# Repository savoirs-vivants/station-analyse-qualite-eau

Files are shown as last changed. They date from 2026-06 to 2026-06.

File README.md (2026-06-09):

# Station d'Analyse de la Qualité de l'Eau 💧

Station autonome pour la surveillance de la qualité de l'eau. Ce dépôt contient l'intégralité de la conception matérielle (schémas et routage PCB) ainsi que le firmware d'acquisition.

## 🎯 Objectif du projet

Ce système a pour but de collecter, traiter, transmettre et enregistrer des données environnementales issues de différentes sondes. Il est conçu pour être autonome en énergie et low-cost.

**Paramètres mesurés :**
*  Température de l'eau
*  Température et Humidité de l'air
*  Conductivité / TDS
*  Turbidité
*  Débit/Hauteur d'eau

## 📁 Architecture du projet

Ce dépôt est organisé en deux parties distinctes :

* 🛠️ **`/hardware`** : Fichiers de conception de la carte électronique réalisés sous KiCad (Schémas, PCB, nomenclatures).
* 💻 **`/firmware`** : Code source en C gérant l'acquisition , le traitement des signaux capteurs et la logique système.

*Pour plus de détails techniques, veuillez consulter les fichiers `README.md` présents dans chacun de ces répertoires.*

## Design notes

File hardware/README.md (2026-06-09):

# 🛠️ Conception Matérielle (Hardware)

Ce dossier contient l'intégralité du projet de conception de la carte mère de la **Station d'Analyse de la Qualité de l'Eau**. La carte est architecturée autour d'un microcontrôleur ultra-basse consommation **STM32U083RC**.

## 📌 Caractéristiques Techniques

* **Microcontrôleur :** STM32U083RC (ARM Cortex-M0+, optimisation Low-Power).
* **Mémoire non volatile :** FeRAM (Ferroelectric RAM) via bus SPI pour le datalogging.
* **Connectivité Radio :**
    * **LoRaWAN :** Module radio intégré pour la transmission vers réseau ChirpStack.
    * **Bluetooth Low Energy (BLE) :** Pour la récupération locale des données en cas de problème avec le LoRa.

## 📂 Architecture du dossier KiCad

* `*.kicad_sch` : Schémas électriques hiérarchiques.
* `*.kicad_pcb` : Routage de la carte.
* `/production` : Fichiers de fabrication générés pour JLCPCB.
* `/3D_Models` : Fichiers STEP pour le rendu 3D.

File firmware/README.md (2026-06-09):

# 💻 Code Embarqué (Firmware STM32)

Ce dossier contient le code source en **C** développé sous **STM32CubeIDE / Eclipse**. Le firmware orchestre l'acquisition des données environnementales, leur stockage sécurisé et leur transmission.

## ⚙️ Environnement & Outils

* **Cible :** STM32U083RC
* **IDE :** STM32CubeIDE (Génération initiale via STM32CubeMX)
* **Documentation :** Doxygen + Graphviz (Voir la section *Documentation* ci-dessous).

## 📂 Architecture du Code

Le projet suit la structure standard de STM32CubeIDE, enrichie de nos propres bibliothèques matérielles :

* `Core/Src/main.c` : Point d'entrée.
* `Core/Src/app_main_test.c` : Fichier d'orchestration principale (Machine d'états, gestion des priorités et du mode Sleep).
* `Drivers/Custom/` : Pilotes développés spécifiquement pour la station :
    * `driverDS18B20` : Lecture de la température (1-Wire émulé via UART).
    * `driverAnalog` : Gestion de l'ADC avec séquenceur fixe et transferts DMA.
    * `driverFRAM` & `driverDataLog` : Pilotes SPI bas niveau et système de fichiers pour le stockage des logs.
    * `driverLoRaWAN` : Empaquetage (Cayenne LPP) et transmission des trames.
    * `driverBLE` : Streaming des archives de données vers un smartphone.
    * `driverRTC` : Gestion du temps et réveils périodiques.

## 🚀 Fonctionnalités Clés & Choix Techniques

1.  **Datalogging Robuste :** Les mesures sont stockées en FeRAM. Le système utilise un pointeur circulaire (`newest_id`) pour gérer l'écrasement des données les plus anciennes.
2.  **Transmission LoRaWAN :** Envoi périodique sur réseau privé ChirpStack (Utilisation d'un `JoinEUI` à `0000000000000000` par défaut). Format de charge utile : **Cayenne LPP**.
3.  **Optimisation des transferts :** Utilisation systématique du DMA pour les lectures FeRAM et le streaming BLE afin de ne pas bloquer le processeur et éviter les corruptions de données.
4.  **Mathématiques en Virgule Fixe :** Remplacement des `float` par la notation en virgule fixe (Q-format) sur 16 bits signés pour optimiser le temps d'exécution et réduire la charge utile radio.

## 📚 Documentation (Doxygen)

Le code est intégralement documenté via des balises Doxygen.
Pour générer la documentation HTML sur votre machine :
1. Ouvrir `Doxywizard`.
2. Charger le fichier de configuration (Doxyfile) situé à la racine du projet firmware.
3. Vérifier que l'option **"Scan recursively"** est bien cochée.
4. Cliquer sur **"Run Doxygen"**. La documentation sera disponible dans le dossier `/html`.

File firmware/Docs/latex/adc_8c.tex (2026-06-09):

\doxysection{C:\+/\+\+Users/\+valen/\+\+Documents/\+\+BUT GEII/\+\+SAE601/\+station\+\_\+analyse\+\_\+qualite\+\_\+eau/\+firmware/\+station\+\_\+analyse\+\_\+qualite\+\_\+eau/\+\+Core/\+\+Src/\+adc.c File Reference}
\hypertarget{adc_8c}{}\label{adc_8c}\index{C:/Users/valen/Documents/BUT GEII/SAE601/station\_analyse\_qualite\_eau/firmware/station\_analyse\_qualite\_eau/Core/Src/adc.c@{C:/Users/valen/Documents/BUT GEII/SAE601/station\_analyse\_qualite\_eau/firmware/station\_analyse\_qualite\_eau/Core/Src/adc.c}}

This file provides code for the configuration of the ADC instances.  

{\ttfamily \+\#include "{}adc.\+h"{}}\newline
Include dependency graph for adc.\+c:\+
\nopagebreak
\begin{figure}[H]
\begin{center}
\leavevmode
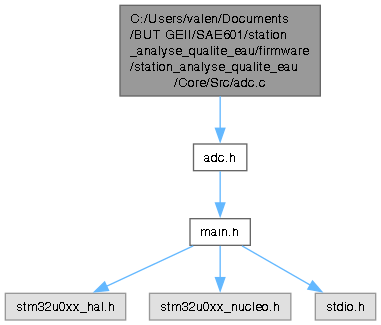
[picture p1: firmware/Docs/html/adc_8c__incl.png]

\end{center}
\end{figure}
\doxysubsubsection*{Functions}
\begin{DoxyCompactItemize}
\item 
void \doxymbox{\hyperlink{adc_8c_acccd58aa70215a6b184ad242312ffd0c}{MX\+\_\+\+ADC1\+\_\+\+Init}} (void)
\item 
void \doxymbox{\hyperlink{adc_8c_ac3139540667c403c5dfd37a99c610b1c}{HAL\+\_\+\+ADC\+\_\+\+Msp\+Init}} (ADC\+\_\+\+Handle\+Type\+Def \texorpdfstring{$\ast$}{*}adc\+Handle)
\item 
void \doxymbox{\hyperlink{adc_8c_a3f61f2c2af0f122f81a87af8ad7b4360}{HAL\+\_\+\+ADC\+\_\+\+Msp\+De\+Init}} (ADC\+\_\+\+Handle\+Type\+Def \texorpdfstring{$\ast$}{*}adc\+Handle)
\end{DoxyCompactItemize}
\doxysubsubsection*{Variables}
\begin{DoxyCompactItemize}
\item 
ADC\+\_\+\+Handle\+Type\+Def \doxymbox{\hyperlink{adc_8c_a22b804736f5648d52f639b2647d4ed13}{hadc1}}
\item 
DMA\+\_\+\+Handle\+Type\+Def \doxymbox{\hyperlink{adc_8c_a1c126854bb1813d31ab4776b21dcc51f}{hdma\+\_\+adc1}}
\end{DoxyCompactItemize}

\doxysubsection{Detailed Description}
This file provides code for the configuration of the ADC instances. 

\begin{DoxyAttention}{Attention}

\end{DoxyAttention}
Copyright (c) 2026 STMicroelectronics. All rights reserved.

This software is licensed under terms that can be found in the LICENSE file in the root directory of this software component. If no LICENSE file comes with this software, it is provided AS-\/\+IS. 

\label{adc_8c_doc-func-members}
\Hypertarget{adc_8c_doc-func-members}
\doxysubsection{Function Documentation}
\Hypertarget{adc_8c_a3f61f2c2af0f122f81a87af8ad7b4360}\index{adc.c@{adc.c}!HAL\_ADC\_MspDeInit@{HAL\_ADC\_MspDeInit}}
\index{HAL\_ADC\_MspDeInit@{HAL\_ADC\_MspDeInit}!adc.c@{adc.c}}
\doxysubsubsection{\texorpdfstring{HAL\_ADC\_MspDeInit()}{HAL\_ADC\_MspDeInit()}}
{\footnotesize\ttfamily \label{adc_8c_a3f61f2c2af0f122f81a87af8ad7b4360} 
void HAL\+\_\+\+ADC\+\_\+\+Msp\+De\+Init (\begin{DoxyParamCaption}\item[{ADC\+\_\+\+Handle\+Type\+Def \texorpdfstring{$\ast$}{*}}]{adc\+Handle}{}\end{DoxyParamCaption})}

ADC1 GPIO Configuration PC2 -\/-\/-\/-\/-\/-\/\texorpdfstring{$>$}{>} ADC1\+\_\+\+IN2 PC3 -\/-\/-\/-\/-\/-\/\texorpdfstring{$>$}{>} ADC1\+\_\+\+IN3 PB1 -\/-\/-\/-\/-\/-\/\texorpdfstring{$>$}{>} ADC1\+\_\+\+IN18\Hypertarget{adc_8c_ac3139540667c403c5dfd37a99c610b1c}\index{adc.c@{adc.c}!HAL\_ADC\_MspInit@{HAL\_ADC\_MspInit}}
\index{HAL\_ADC\_MspInit@{HAL\_ADC\_MspInit}!adc.c@{adc.c}}
\doxysubsubsection{\texorpdfstring{HAL\_ADC\_MspInit()}{HAL\_ADC\_MspInit()}}
{\footnotesize\ttfamily \label{adc_8c_ac3139540667c403c5dfd37a99c610b1c} 
void HAL\+\_\+\+ADC\+\_\+\+Msp\+Init (\begin{DoxyParamCaption}\item[{ADC\+\_\+\+Handle\+Type\+Def \texorpdfstring{$\ast$}{*}}]{adc\+Handle}{}\end{DoxyParamCaption})}

Initializes the peripherals clocks

ADC1 GPIO Configuration PC2 -\/-\/-\/-\/-\/-\/\texorpdfstring{$>$}{>} ADC1\+\_\+\+IN2 PC3 -\/-\/-\/-\/-\/-\/\texorpdfstring{$>$}{>} ADC1\+\_\+\+IN3 PB1 -\/-\/-\/-\/-\/-\/\texorpdfstring{$>$}{>} ADC1\+\_\+\+IN18Here is the call graph for this function:\+
\nopagebreak
\begin{figure}[H]
\begin{center}
\leavevmode

\end{center}
\end{figure}
\Hypertarget{adc_8c_acccd58aa70215a6b184ad242312ffd0c}\index{adc.c@{adc.c}!MX\_ADC1\_Init@{MX\_ADC1\_Init}}
\index{MX\_ADC1\_Init@{MX\_ADC1\_Init}!adc.c@{adc.c}}
\doxysubsubsection{\texorpdfstring{MX\_ADC1\_Init()}{MX\_ADC1\_Init()}}
{\footnotesize\ttfamily \label{adc_8c_acccd58aa70215a6b184ad242312ffd0c} 
void MX\+\_\+\+ADC1\+\_\+\+Init (\begin{DoxyParamCaption}\item[{void}]{}{}\end{DoxyParamCaption})}

Configure the global features of the ADC (Clock, Resolution, Data Alignment and number of conversion)

Configure Regular Channel

Configure Regular Channel

Configure Regular Channel

Configure Regular Channel

Configure the Watch\+Dogs 2

Configure the Watch\+Dogs 3Here is the call graph for this function:\+
\nopagebreak
\begin{figure}[H]
\begin{center}
\leavevmode

\end{center}
\end{figure}
Here is the caller graph for this function:\+
\nopagebreak
\begin{figure}[H]
\begin{center}
\leavevmode

\end{center}
\end{figure}

\label{adc_8c_doc-var-members}
\Hypertarget{adc_8c_doc-var-members}
\doxysubsection{Variable Documentation}
\Hypertarget{adc_8c_a22b804736f5648d52f639b2647d4ed13}\index{adc.c@{adc.c}!hadc1@{hadc1}}
\index{hadc1@{hadc1}!adc.c@{adc.c}}
\doxysubsubsection{\texorpdfstring{hadc1}{hadc1}}
{\footnotesize\ttfamily \label{adc_8c_a22b804736f5648d52f639b2647d4ed13} 
ADC\+\_\+\+Handle\+Type\+Def hadc1}

\Hypertarget{adc_8c_a1c126854bb1813d31ab4776b21dcc51f}\index{adc.c@{adc.c}!hdma\_adc1@{hdma\_adc1}}
\index{hdma\_adc1@{hdma\_adc1}!adc.c@{adc.c}}
\doxysubsubsection{\texorpdfstring{hdma\_adc1}{hdma\_adc1}}
{\footnotesize\ttfamily \label{adc_8c_a1c126854bb1813d31ab4776b21dcc51f} 
DMA\+\_\+\+Handle\+Type\+Def hdma\+\_\+adc1}

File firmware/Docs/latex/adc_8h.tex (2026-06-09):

\doxysection{C:\+/\+\+Users/\+valen/\+\+Documents/\+\+BUT GEII/\+\+SAE601/\+station\+\_\+analyse\+\_\+qualite\+\_\+eau/\+firmware/\+station\+\_\+analyse\+\_\+qualite\+\_\+eau/\+\+Core/\+\+Inc/\+adc.h File Reference}
\hypertarget{adc_8h}{}\label{adc_8h}\index{C:/Users/valen/Documents/BUT GEII/SAE601/station\_analyse\_qualite\_eau/firmware/station\_analyse\_qualite\_eau/Core/Inc/adc.h@{C:/Users/valen/Documents/BUT GEII/SAE601/station\_analyse\_qualite\_eau/firmware/station\_analyse\_qualite\_eau/Core/Inc/adc.h}}

This file contains all the function prototypes for the \doxylink{adc_8c}{adc.\+c} file.  

{\ttfamily \+\#include "{}main.\+h"{}}\newline
Include dependency graph for adc.\+h:\+
\nopagebreak
\begin{figure}[H]
\begin{center}
\leavevmode
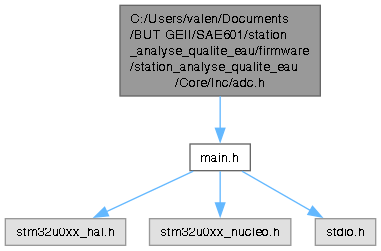
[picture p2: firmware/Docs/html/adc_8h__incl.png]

\end{center}
\end{figure}
This graph shows which files directly or indirectly include this file:\+
\nopagebreak
\begin{figure}[H]
\begin{center}
\leavevmode
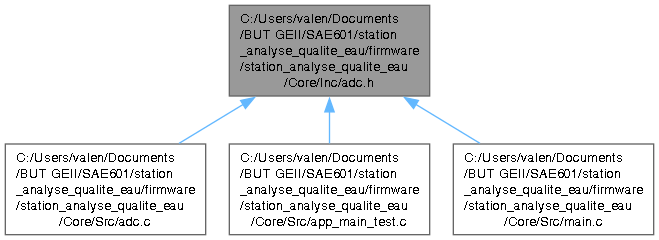
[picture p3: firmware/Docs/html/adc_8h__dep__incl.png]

\end{center}
\end{figure}
\doxysubsubsection*{Functions}
\begin{DoxyCompactItemize}
\item 
void \doxymbox{\hyperlink{adc_8h_acccd58aa70215a6b184ad242312ffd0c}{MX\+\_\+\+ADC1\+\_\+\+Init}} (void)
\end{DoxyCompactItemize}
\doxysubsubsection*{Variables}
\begin{DoxyCompactItemize}
\item 
ADC\+\_\+\+Handle\+Type\+Def \doxymbox{\hyperlink{adc_8h_a22b804736f5648d52f639b2647d4ed13}{hadc1}}
\end{DoxyCompactItemize}

\doxysubsection{Detailed Description}
This file contains all the function prototypes for the \doxylink{adc_8c}{adc.\+c} file. 

\begin{DoxyAttention}{Attention}

\end{DoxyAttention}
Copyright (c) 2026 STMicroelectronics. All rights reserved.

This software is licensed under terms that can be found in the LICENSE file in the root directory of this software component. If no LICENSE file comes with this software, it is provided AS-\/\+IS. 

\label{adc_8h_doc-func-members}
\Hypertarget{adc_8h_doc-func-members}
\doxysubsection{Function Documentation}
\Hypertarget{adc_8h_acccd58aa70215a6b184ad242312ffd0c}\index{adc.h@{adc.h}!MX\_ADC1\_Init@{MX\_ADC1\_Init}}
\index{MX\_ADC1\_Init@{MX\_ADC1\_Init}!adc.h@{adc.h}}
\doxysubsubsection{\texorpdfstring{MX\_ADC1\_Init()}{MX\_ADC1\_Init()}}
{\footnotesize\ttfamily \label{adc_8h_acccd58aa70215a6b184ad242312ffd0c} 
void MX\+\_\+\+ADC1\+\_\+\+Init (\begin{DoxyParamCaption}\item[{void}]{}{}\end{DoxyParamCaption})}

Configure the global features of the ADC (Clock, Resolution, Data Alignment and number of conversion)

Configure Regular Channel

Configure Regular Channel

Configure Regular Channel

Configure Regular Channel

Configure the Watch\+Dogs 2

Configure the Watch\+Dogs 3Here is the call graph for this function:\+
\nopagebreak
\begin{figure}[H]
\begin{center}
\leavevmode

\end{center}
\end{figure}
Here is the caller graph for this function:\+
\nopagebreak
\begin{figure}[H]
\begin{center}
\leavevmode

\end{center}
\end{figure}

\label{adc_8h_doc-var-members}
\Hypertarget{adc_8h_doc-var-members}
\doxysubsection{Variable Documentation}
\Hypertarget{adc_8h_a22b804736f5648d52f639b2647d4ed13}\index{adc.h@{adc.h}!hadc1@{hadc1}}
\index{hadc1@{hadc1}!adc.h@{adc.h}}
\doxysubsubsection{\texorpdfstring{hadc1}{hadc1}}
{\footnotesize\ttfamily \label{adc_8h_a22b804736f5648d52f639b2647d4ed13} 
ADC\+\_\+\+Handle\+Type\+Def hadc1\hspace{0.3cm}{\ttfamily [extern]}}

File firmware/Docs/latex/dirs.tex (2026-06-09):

\doxysection{Directories}
\begin{DoxyCompactList}
\item \contentsline{section}{Core }{\pageref{dir_9d5e7573dc5466d7cafab5f0bc7db382}}{}
\begin{DoxyCompactList}
\item \contentsline{section}{Inc }{\pageref{dir_90b35f58c259cafbcc0aa6572fba667e}}{}
\begin{DoxyCompactList}
\item \contentsline{section}{adc.\+h }{\pageref{adc_8h}}{}
\item \contentsline{section}{app\+\_\+main\+\_\+test.\+h }{\pageref{app__main__test_8h}}{}
\item \contentsline{section}{dma.\+h }{\pageref{dma_8h}}{}
\item \contentsline{section}{driver\+Analog.\+h }{\pageref{driver_analog_8h}}{}
\item \contentsline{section}{driver\+BLE.\+h }{\pageref{driver_b_l_e_8h}}{}
\item \contentsline{section}{driver\+Data\+Log.\+h }{\pageref{driver_data_log_8h}}{}
\item \contentsline{section}{driver\+DS18\+B20.\+h }{\pageref{driver_d_s18_b20_8h}}{}
\item \contentsline{section}{driver\+FRAM.\+h }{\pageref{driver_f_r_a_m_8h}}{}
\item \contentsline{section}{driver\+Lo\+Ra.\+h }{\pageref{driver_lo_ra_8h}}{}
\item \contentsline{section}{driver\+Lo\+Ra\+App.\+h }{\pageref{driver_lo_ra_app_8h}}{}
\item \contentsline{section}{driver\+Lo\+Ra\+WAN.\+h }{\pageref{driver_lo_ra_w_a_n_8h}}{}
\item \contentsline{section}{driver\+LPPCayenne.\+h }{\pageref{driver_l_p_p_cayenne_8h}}{}
\item \contentsline{section}{driver\+RTC.\+h }{\pageref{driver_r_t_c_8h}}{}
\item \contentsline{section}{gpio.\+h }{\pageref{gpio_8h}}{}
\item \contentsline{section}{lptim.\+h }{\pageref{lptim_8h}}{}
\item \contentsline{section}{main.\+h }{\pageref{main_8h}}{}
\item \contentsline{section}{rtc.\+h }{\pageref{rtc_8h}}{}
\item \contentsline{section}{spi.\+h }{\pageref{spi_8h}}{}
\item \contentsline{section}{stm32u0xx\+\_\+hal\+\_\+conf.\+h }{\pageref{stm32u0xx__hal__conf_8h}}{}
\item \contentsline{section}{stm32u0xx\+\_\+it.\+h }{\pageref{stm32u0xx__it_8h}}{}
\item \contentsline{section}{stm32u0xx\+\_\+nucleo\+\_\+conf.\+h }{\pageref{stm32u0xx__nucleo__conf_8h}}{}
\item \contentsline{section}{test\+\_\+analog.\+h }{\pageref{test__analog_8h}}{}
\item \contentsline{section}{test\+\_\+ble.\+h }{\pageref{test__ble_8h}}{}
\item \contentsline{section}{test\+\_\+datalog.\+h }{\pageref{test__datalog_8h}}{}
\item \contentsline{section}{test\+\_\+ds18b20.\+h }{\pageref{test__ds18b20_8h}}{}
\item \contentsline{section}{test\+\_\+fram.\+h }{\pageref{test__fram_8h}}{}
\item \contentsline{section}{test\+\_\+lorawan.\+h }{\pageref{test__lorawan_8h}}{}
\item \contentsline{section}{test\+\_\+lpp.\+h }{\pageref{test__lpp_8h}}{}
\item \contentsline{section}{tim.\+h }{\pageref{tim_8h}}{}
\item \contentsline{section}{usart.\+h }{\pageref{usart_8h}}{}
\end{DoxyCompactList}
\item \contentsline{section}{Src }{\pageref{dir_1ca2d35386e5ad8f7045c2fe5e28151f}}{}
\begin{DoxyCompactList}
\item \contentsline{section}{adc.\+c }{\pageref{adc_8c}}{}
\item \contentsline{section}{app\+\_\+main\+\_\+test.\+c }{\pageref{app__main__test_8c}}{}
\item \contentsline{section}{dma.\+c }{\pageref{dma_8c}}{}
\item \contentsline{section}{driver\+Analog.\+c }{\pageref{driver_analog_8c}}{}
\item \contentsline{section}{driver\+BLE.\+c }{\pageref{driver_b_l_e_8c}}{}
\item \contentsline{section}{driver\+Data\+Log.\+c }{\pageref{driver_data_log_8c}}{}
\item \contentsline{section}{driver\+DS18\+B20.\+c }{\pageref{driver_d_s18_b20_8c}}{}
\item \contentsline{section}{driver\+FRAM.\+c }{\pageref{driver_f_r_a_m_8c}}{}
\item \contentsline{section}{driver\+Lo\+Ra.\+c }{\pageref{driver_lo_ra_8c}}{}
\item \contentsline{section}{driver\+Lo\+Ra\+App.\+c }{\pageref{driver_lo_ra_app_8c}}{}
\item \contentsline{section}{driver\+Lo\+Ra\+WAN.\+c }{\pageref{driver_lo_ra_w_a_n_8c}}{}
\item \contentsline{section}{driver\+LPPCayenne.\+c }{\pageref{driver_l_p_p_cayenne_8c}}{}
\item \contentsline{section}{driver\+RTC.\+c }{\pageref{driver_r_t_c_8c}}{}
\item \contentsline{section}{gpio.\+c }{\pageref{gpio_8c}}{}
\item \contentsline{section}{lptim.\+c }{\pageref{lptim_8c}}{}
\item \contentsline{section}{main.\+c }{\pageref{main_8c}}{}
\item \contentsline{section}{rtc.\+c }{\pageref{rtc_8c}}{}
\item \contentsline{section}{spi.\+c }{\pageref{spi_8c}}{}
\item \contentsline{section}{stm32u0xx\+\_\+hal\+\_\+msp.\+c }{\pageref{stm32u0xx__hal__msp_8c}}{}
\item \contentsline{section}{stm32u0xx\+\_\+it.\+c }{\pageref{stm32u0xx__it_8c}}{}
\item \contentsline{section}{syscalls.\+c }{\pageref{syscalls_8c}}{}
\item \contentsline{section}{sysmem.\+c }{\pageref{sysmem_8c}}{}
\item \contentsline{section}{system\+\_\+stm32u0xx.\+c }{\pageref{system__stm32u0xx_8c}}{}
\item \contentsline{section}{test\+\_\+analog.\+c }{\pageref{test__analog_8c}}{}
\item \contentsline{section}{test\+\_\+ble.\+c }{\pageref{test__ble_8c}}{}
\item \contentsline{section}{test\+\_\+datalog.\+c }{\pageref{test__datalog_8c}}{}
\item \contentsline{section}{test\+\_\+ds18b20.\+c }{\pageref{test__ds18b20_8c}}{}
\item \contentsline{section}{test\+\_\+fram.\+c }{\pageref{test__fram_8c}}{}
\item \contentsline{section}{test\+\_\+lorawan.\+c }{\pageref{test__lorawan_8c}}{}
\item \contentsline{section}{test\+\_\+lpp.\+c }{\pageref{test__lpp_8c}}{}
\item \contentsline{section}{tim.\+c }{\pageref{tim_8c}}{}
\item \contentsline{section}{usart.\+c }{\pageref{usart_8c}}{}
\end{DoxyCompactList}
\end{DoxyCompactList}
\item \contentsline{section}{Inc }{\pageref{dir_90b35f58c259cafbcc0aa6572fba667e}}{}
\begin{DoxyCompactList}
\item \contentsline{section}{adc.\+h }{\pageref{adc_8h}}{}
\item \contentsline{section}{app\+\_\+main\+\_\+test.\+h }{\pageref{app__main__test_8h}}{}
\item \contentsline{section}{dma.\+h }{\pageref{dma_8h}}{}
\item \contentsline{section}{driver\+Analog.\+h }{\pageref{driver_analog_8h}}{}
\item \contentsline{section}{driver\+BLE.\+h }{\pageref{driver_b_l_e_8h}}{}
\item \contentsline{section}{driver\+Data\+Log.\+h }{\pageref{driver_data_log_8h}}{}
\item \contentsline{section}{driver\+DS18\+B20.\+h }{\pageref{driver_d_s18_b20_8h}}{}
\item \contentsline{section}{driver\+FRAM.\+h }{\pageref{driver_f_r_a_m_8h}}{}
\item \contentsline{section}{driver\+Lo\+Ra.\+h }{\pageref{driver_lo_ra_8h}}{}
\item \contentsline{section}{driver\+Lo\+Ra\+App.\+h }{\pageref{driver_lo_ra_app_8h}}{}
\item \contentsline{section}{driver\+Lo\+Ra\+WAN.\+h }{\pageref{driver_lo_ra_w_a_n_8h}}{}
\item \contentsline{section}{driver\+LPPCayenne.\+h }{\pageref{driver_l_p_p_cayenne_8h}}{}
\item \contentsline{section}{driver\+RTC.\+h }{\pageref{driver_r_t_c_8h}}{}
\item \contentsline{section}{gpio.\+h }{\pageref{gpio_8h}}{}
\item \contentsline{section}{lptim.\+h }{\pageref{lptim_8h}}{}
\item \contentsline{section}{main.\+h }{\pageref{main_8h}}{}
\item \contentsline{section}{rtc.\+h }{\pageref{rtc_8h}}{}
\item \contentsline{section}{spi.\+h }{\pageref{spi_8h}}{}
\item \contentsline{section}{stm32u0xx\+\_\+hal\+\_\+conf.\+h }{\pageref{stm32u0xx__hal__conf_8h}}{}
\item \contentsline{section}{stm32u0xx\+\_\+it.\+h }{\pageref{stm32u0xx__it_8h}}{}
\item \contentsline{section}{stm32u0xx\+\_\+nucleo\+\_\+conf.\+h }{\pageref{stm32u0xx__nucleo__conf_8h}}{}
\item \contentsline{section}{test\+\_\+analog.\+h }{\pageref{test__analog_8h}}{}
\item \contentsline{section}{test\+\_\+ble.\+h }{\pageref{test__ble_8h}}{}
\item \contentsline{section}{test\+\_\+datalog.\+h }{\pageref{test__datalog_8h}}{}
\item \contentsline{section}{test\+\_\+ds18b20.\+h }{\pageref{test__ds18b20_8h}}{}
\item \contentsline{section}{test\+\_\+fram.\+h }{\pageref{test__fram_8h}}{}
\item \contentsline{section}{test\+\_\+lorawan.\+h }{\pageref{test__lorawan_8h}}{}
\item \contentsline{section}{test\+\_\+lpp.\+h }{\pageref{test__lpp_8h}}{}
\item \contentsline{section}{tim.\+h }{\pageref{tim_8h}}{}
\item \contentsline{section}{usart.\+h }{\pageref{usart_8h}}{}
\end{DoxyCompactList}
\item \contentsline{section}{Src }{\pageref{dir_1ca2d35386e5ad8f7045c2fe5e28151f}}{}
\begin{DoxyCompactList}
\item \contentsline{section}{adc.\+c }{\pageref{adc_8c}}{}
\item \contentsline{section}{app\+\_\+main\+\_\+test.\+c }{\pageref{app__main__test_8c}}{}
\item \contentsline{section}{dma.\+c }{\pageref{dma_8c}}{}
\item \contentsline{section}{driver\+Analog.\+c }{\pageref{driver_analog_8c}}{}
\item \contentsline{section}{driver\+BLE.\+c }{\pageref{driver_b_l_e_8c}}{}
\item \contentsline{section}{driver\+Data\+Log.\+c }{\pageref{driver_data_log_8c}}{}
\item \contentsline{section}{driver\+DS18\+B20.\+c }{\pageref{driver_d_s18_b20_8c}}{}
\item \contentsline{section}{driver\+FRAM.\+c }{\pageref{driver_f_r_a_m_8c}}{}
\item \contentsline{section}{driver\+Lo\+Ra.\+c }{\pageref{driver_lo_ra_8c}}{}
\item \contentsline{section}{driver\+Lo\+Ra\+App.\+c }{\pageref{driver_lo_ra_app_8c}}{}
\item \contentsline{section}{driver\+Lo\+Ra\+WAN.\+c }{\pageref{driver_lo_ra_w_a_n_8c}}{}
\item \contentsline{section}{driver\+LPPCayenne.\+c }{\pageref{driver_l_p_p_cayenne_8c}}{}
\item \contentsline{section}{driver\+RTC.\+c }{\pageref{driver_r_t_c_8c}}{}
\item \contentsline{section}{gpio.\+c }{\pageref{gpio_8c}}{}
\item \contentsline{section}{lptim.\+c }{\pageref{lptim_8c}}{}
\item \contentsline{section}{main.\+c }{\pageref{main_8c}}{}
\item \contentsline{section}{rtc.\+c }{\pageref{rtc_8c}}{}
\item \contentsline{section}{spi.\+c }{\pageref{spi_8c}}{}
\item \contentsline{section}{stm32u0xx\+\_\+hal\+\_\+msp.\+c }{\pageref{stm32u0xx__hal__msp_8c}}{}
\item \contentsline{section}{stm32u0xx\+\_\+it.\+c }{\pageref{stm32u0xx__it_8c}}{}
\item \contentsline{section}{syscalls.\+c }{\pageref{syscalls_8c}}{}
\item \contentsline{section}{sysmem.\+c }{\pageref{sysmem_8c}}{}
\item \contentsline{section}{system\+\_\+stm32u0xx.\+c }{\pageref{system__stm32u0xx_8c}}{}
\item \contentsline{section}{test\+\_\+analog.\+c }{\pageref{test__analog_8c}}{}
\item \contentsline{section}{test\+\_\+ble.\+c }{\pageref{test__ble_8c}}{}
\item \contentsline{section}{test\+\_\+datalog.\+c }{\pageref{test__datalog_8c}}{}
\item \contentsline{section}{test\+\_\+ds18b20.\+c }{\pageref{test__ds18b20_8c}}{}
\item \contentsline{section}{test\+\_\+fram.\+c }{\pageref{test__fram_8c}}{}
\item \contentsline{section}{test\+\_\+lorawan.\+c }{\pageref{test__lorawan_8c}}{}
\item \contentsline{section}{test\+\_\+lpp.\+c }{\pageref{test__lpp_8c}}{}
\item \contentsline{section}{tim.\+c }{\pageref{tim_8c}}{}
\item \contentsline{section}{usart.\+c }{\pageref{usart_8c}}{}
\end{DoxyCompactList}
\item \contentsline{section}{station\+\_\+analyse\+\_\+qualite\+\_\+eau }{\pageref{dir_4fc195ea1a251ebc8cad320ade13d143}}{}
\begin{DoxyCompactList}
\item \contentsline{section}{Core }{\pageref{dir_9d5e7573dc5466d7cafab5f0bc7db382}}{}
\begin{DoxyCompactList}
\item \contentsline{section}{Inc }{\pageref{dir_90b35f58c259cafbcc0aa6572fba667e}}{}
\begin{DoxyCompactList}
\item \contentsline{section}{adc.\+h }{\pageref{adc_8h}}{}
\item \contentsline{section}{app\+\_\+main\+\_\+test.\+h }{\pageref{app__main__test_8h}}{}
\item \contentsline{section}{dma.\+h }{\pageref{dma_8h}}{}
\item \contentsline{section}{driver\+Analog.\+h }{\pageref{driver_analog_8h}}{}
\item \contentsline{section}{driver\+BLE.\+h }{\pageref{driver_b_l_e_8h}}{}
\item \contentsline{section}{driver\+Data\+Log.\+h }{\pageref{driver_data_log_8h}}{}
\item \contentsline{section}{driver\+DS18\+B20.\+h }{\pageref{driver_d_s18_b20_8h}}{}
\item \contentsline{section}{driver\+FRAM.\+h }{\pageref{driver_f_r_a_m_8h}}{}
\item \contentsline{section}{driver\+Lo\+Ra.\+h }{\pageref{driver_lo_ra_8h}}{}
\item \contentsline{section}{driver\+Lo\+Ra\+App.\+h }{\pageref{driver_lo_ra_app_8h}}{}
\item \contentsline{section}{driver\+Lo\+Ra\+WAN.\+h }{\pageref{driver_lo_ra_w_a_n_8h}}{}
\item \contentsline{section}{driver\+LPPCayenne.\+h }{\pageref{driver_l_p_p_cayenne_8h}}{}
\item \contentsline{section}{driver\+RTC.\+h }{\pageref{driver_r_t_c_8h}}{}
\item \contentsline{section}{gpio.\+h }{\pageref{gpio_8h}}{}
\item \contentsline{section}{lptim.\+h }{\pageref{lptim_8h}}{}
\item \contentsline{section}{main.\+h }{\pageref{main_8h}}{}
\item \contentsline{section}{rtc.\+h }{\pageref{rtc_8h}}{}
\item \contentsline{section}{spi.\+h }{\pageref{spi_8h}}{}
\item \contentsline{section}{stm32u0xx\+\_\+hal\+\_\+conf.\+h }{\pageref{stm32u0xx__hal__conf_8h}}{}
\item \contentsline{section}{stm32u0xx\+\_\+it.\+h }{\pageref{stm32u0xx__it_8h}}{}
\item \contentsline{section}{stm32u0xx\+\_\+nucleo\+\_\+conf.\+h }{\pageref{stm32u0xx__nucleo__conf_8h}}{}
\item \contentsline{section}{test\+\_\+analog.\+h }{\pageref{test__analog_8h}}{}
\item \contentsline{section}{test\+\_\+ble.\+h }{\pageref{test__ble_8h}}{}
\item \contentsline{section}{test\+\_\+datalog.\+h }{\pageref{test__datalog_8h}}{}
\item \contentsline{section}{test\+\_\+ds18b20.\+h }{\pageref{test__ds18b20_8h}}{}
\item \contentsline{section}{test\+\_\+fram.\+h }{\pageref{test__fram_8h}}{}
\item \contentsline{section}{test\+\_\+lorawan.\+h }{\pageref{test__lorawan_8h}}{}
\item \contentsline{section}{test\+\_\+lpp.\+h }{\pageref{test__lpp_8h}}{}
\item \contentsline{section}{tim.\+h }{\pageref{tim_8h}}{}
\item \contentsline{section}{usart.\+h }{\pageref{usart_8h}}{}
\end{DoxyCompactList}
\item \contentsline{section}{Src }{\pageref{dir_1ca2d35386e5ad8f7045c2fe5e28151f}}{}
\begin{DoxyCompactList}
\item \contentsline{section}{adc.\+c }{\pageref{adc_8c}}{}
\item \contentsline{section}{app\+\_\+main\+\_\+test.\+c }{\pageref{app__main__test_8c}}{}
\item \contentsline{section}{dma.\+c }{\pageref{dma_8c}}{}
\item \contentsline{section}{driver\+Analog.\+c }{\pageref{driver_analog_8c}}{}
\item \contentsline{section}{driver\+BLE.\+c }{\pageref{driver_b_l_e_8c}}{}
\item \contentsline{section}{driver\+Data\+Log.\+c }{\pageref{driver_data_log_8c}}{}
\item \contentsline{section}{driver\+DS18\+B20.\+c }{\pageref{driver_d_s18_b20_8c}}{}
\item \contentsline{section}{driver\+FRAM.\+c }{\pageref{driver_f_r_a_m_8c}}{}
\item \contentsline{section}{driver\+Lo\+Ra.\+c }{\pageref{driver_lo_ra_8c}}{}
\item \contentsline{section}{driver\+Lo\+Ra\+App.\+c }{\pageref{driver_lo_ra_app_8c}}{}
\item \contentsline{section}{driver\+Lo\+Ra\+WAN.\+c }{\pageref{driver_lo_ra_w_a_n_8c}}{}
\item \contentsline{section}{driver\+LPPCayenne.\+c }{\pageref{driver_l_p_p_cayenne_8c}}{}
\item \contentsline{section}{driver\+RTC.\+c }{\pageref{driver_r_t_c_8c}}{}
\item \contentsline{section}{gpio.\+c }{\pageref{gpio_8c}}{}
\item \contentsline{section}{lptim.\+c }{\pageref{lptim_8c}}{}
\item \contentsline{section}{main.\+c }{\pageref{main_8c}}{}
\item \contentsline{section}{rtc.\+c }{\pageref{rtc_8c}}{}
\item \contentsline{section}{spi.\+c }{\pageref{spi_8c}}{}
\item \contentsline{section}{stm32u0xx\+\_\+hal\+\_\+msp.\+c }{\pageref{stm32u0xx__hal__msp_8c}}{}
\item \contentsline{section}{stm32u0xx\+\_\+it.\+c }{\pageref{stm32u0xx__it_8c}}{}
\item \contentsline{section}{syscalls.\+c }{\pageref{syscalls_8c}}{}
\item \contentsline{section}{sysmem.\+c }{\pageref{sysmem_8c}}{}
\item \contentsline{section}{system\+\_\+stm32u0xx.\+c }{\pageref{system__stm32u0xx_8c}}{}
\item \contentsline{section}{test\+\_\+analog.\+c }{\pageref{test__analog_8c}}{}
\item \contentsline{section}{test\+\_\+ble.\+c }{\pageref{test__ble_8c}}{}
\item \contentsline{section}{test\+\_\+datalog.\+c }{\pageref{test__datalog_8c}}{}
\item \contentsline{section}{test\+\_\+ds18b20.\+c }{\pageref{test__ds18b20_8c}}{}
\item \contentsline{section}{test\+\_\+fram.\+c }{\pageref{test__fram_8c}}{}
\item \contentsline{section}{test\+\_\+lorawan.\+c }{\pageref{test__lorawan_8c}}{}
\item \contentsline{section}{test\+\_\+lpp.\+c }{\pageref{test__lpp_8c}}{}
\item \contentsline{section}{tim.\+c }{\pageref{tim_8c}}{}
\item \contentsline{section}{usart.\+c }{\pageref{usart_8c}}{}
\end{DoxyCompactList}
\end{DoxyCompactList}
\end{DoxyCompactList}
\end{DoxyCompactList}

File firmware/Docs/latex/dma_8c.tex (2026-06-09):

\doxysection{C:\+/\+\+Users/\+valen/\+\+Documents/\+\+BUT GEII/\+\+SAE601/\+station\+\_\+analyse\+\_\+qualite\+\_\+eau/\+firmware/\+station\+\_\+analyse\+\_\+qualite\+\_\+eau/\+\+Core/\+\+Src/\+dma.c File Reference}
\hypertarget{dma_8c}{}\label{dma_8c}\index{C:/Users/valen/Documents/BUT GEII/SAE601/station\_analyse\_qualite\_eau/firmware/station\_analyse\_qualite\_eau/Core/Src/dma.c@{C:/Users/valen/Documents/BUT GEII/SAE601/station\_analyse\_qualite\_eau/firmware/station\_analyse\_qualite\_eau/Core/Src/dma.c}}

This file provides code for the configuration of all the requested memory to memory DMA transfers.  

{\ttfamily \+\#include "{}dma.\+h"{}}\newline
Include dependency graph for dma.\+c:\+
\nopagebreak
\begin{figure}[H]
\begin{center}
\leavevmode
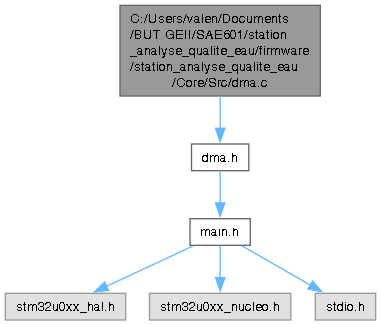
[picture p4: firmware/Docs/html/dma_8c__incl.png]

\end{center}
\end{figure}
\doxysubsubsection*{Functions}
\begin{DoxyCompactItemize}
\item 
void \doxymbox{\hyperlink{dma_8c_a323249dac769f9855c10b4ec9446b707}{MX\+\_\+\+DMA\+\_\+\+Init}} (void)
\end{DoxyCompactItemize}

\doxysubsection{Detailed Description}
This file provides code for the configuration of all the requested memory to memory DMA transfers. 

\begin{DoxyAttention}{Attention}

\end{DoxyAttention}
Copyright (c) 2026 STMicroelectronics. All rights reserved.

This software is licensed under terms that can be found in the LICENSE file in the root directory of this software component. If no LICENSE file comes with this software, it is provided AS-\/\+IS. 

\label{dma_8c_doc-func-members}
\Hypertarget{dma_8c_doc-func-members}
\doxysubsection{Function Documentation}
\Hypertarget{dma_8c_a323249dac769f9855c10b4ec9446b707}\index{dma.c@{dma.c}!MX\_DMA\_Init@{MX\_DMA\_Init}}
\index{MX\_DMA\_Init@{MX\_DMA\_Init}!dma.c@{dma.c}}
\doxysubsubsection{\texorpdfstring{MX\_DMA\_Init()}{MX\_DMA\_Init()}}
{\footnotesize\ttfamily \label{dma_8c_a323249dac769f9855c10b4ec9446b707} 
void MX\+\_\+\+DMA\+\_\+\+Init (\begin{DoxyParamCaption}\item[{void}]{}{}\end{DoxyParamCaption})}

Enable DMA controller clock Here is the caller graph for this function:\+
\nopagebreak
\begin{figure}[H]
\begin{center}
\leavevmode

\end{center}
\end{figure}

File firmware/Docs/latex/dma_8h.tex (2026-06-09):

\doxysection{C:\+/\+\+Users/\+valen/\+\+Documents/\+\+BUT GEII/\+\+SAE601/\+station\+\_\+analyse\+\_\+qualite\+\_\+eau/\+firmware/\+station\+\_\+analyse\+\_\+qualite\+\_\+eau/\+\+Core/\+\+Inc/\+dma.h File Reference}
\hypertarget{dma_8h}{}\label{dma_8h}\index{C:/Users/valen/Documents/BUT GEII/SAE601/station\_analyse\_qualite\_eau/firmware/station\_analyse\_qualite\_eau/Core/Inc/dma.h@{C:/Users/valen/Documents/BUT GEII/SAE601/station\_analyse\_qualite\_eau/firmware/station\_analyse\_qualite\_eau/Core/Inc/dma.h}}

This file contains all the function prototypes for the \doxylink{dma_8c}{dma.\+c} file.  

{\ttfamily \+\#include "{}main.\+h"{}}\newline
Include dependency graph for dma.\+h:\+
\nopagebreak
\begin{figure}[H]
\begin{center}
\leavevmode
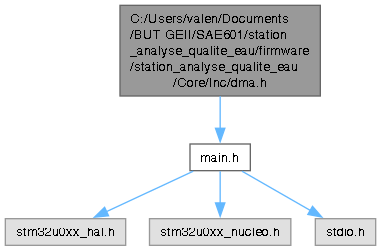
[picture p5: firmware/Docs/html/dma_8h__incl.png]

\end{center}
\end{figure}
This graph shows which files directly or indirectly include this file:\+
\nopagebreak
\begin{figure}[H]
\begin{center}
\leavevmode
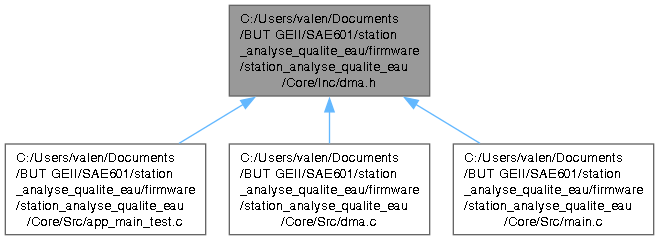
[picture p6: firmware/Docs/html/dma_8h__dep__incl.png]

\end{center}
\end{figure}
\doxysubsubsection*{Functions}
\begin{DoxyCompactItemize}
\item 
void \doxymbox{\hyperlink{dma_8h_a323249dac769f9855c10b4ec9446b707}{MX\+\_\+\+DMA\+\_\+\+Init}} (void)
\end{DoxyCompactItemize}

\doxysubsection{Detailed Description}
This file contains all the function prototypes for the \doxylink{dma_8c}{dma.\+c} file. 

\begin{DoxyAttention}{Attention}

\end{DoxyAttention}
Copyright (c) 2026 STMicroelectronics. All rights reserved.

This software is licensed under terms that can be found in the LICENSE file in the root directory of this software component. If no LICENSE file comes with this software, it is provided AS-\/\+IS. 

\label{dma_8h_doc-func-members}
\Hypertarget{dma_8h_doc-func-members}
\doxysubsection{Function Documentation}
\Hypertarget{dma_8h_a323249dac769f9855c10b4ec9446b707}\index{dma.h@{dma.h}!MX\_DMA\_Init@{MX\_DMA\_Init}}
\index{MX\_DMA\_Init@{MX\_DMA\_Init}!dma.h@{dma.h}}
\doxysubsubsection{\texorpdfstring{MX\_DMA\_Init()}{MX\_DMA\_Init()}}
{\footnotesize\ttfamily \label{dma_8h_a323249dac769f9855c10b4ec9446b707} 
void MX\+\_\+\+DMA\+\_\+\+Init (\begin{DoxyParamCaption}\item[{void}]{}{}\end{DoxyParamCaption})}

Enable DMA controller clock Here is the caller graph for this function:\+
\nopagebreak
\begin{figure}[H]
\begin{center}
\leavevmode

\end{center}
\end{figure}

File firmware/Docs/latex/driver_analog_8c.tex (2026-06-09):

\doxysection{C:\+/\+\+Users/\+valen/\+\+Documents/\+\+BUT GEII/\+\+SAE601/\+station\+\_\+analyse\+\_\+qualite\+\_\+eau/\+firmware/\+station\+\_\+analyse\+\_\+qualite\+\_\+eau/\+\+Core/\+\+Src/\+driver\+Analog.c File Reference}
\hypertarget{driver_analog_8c}{}\label{driver_analog_8c}\index{C:/Users/valen/Documents/BUT GEII/SAE601/station\_analyse\_qualite\_eau/firmware/station\_analyse\_qualite\_eau/Core/Src/driverAnalog.c@{C:/Users/valen/Documents/BUT GEII/SAE601/station\_analyse\_qualite\_eau/firmware/station\_analyse\_qualite\_eau/Core/Src/driverAnalog.c}}
{\ttfamily \+\#include "{}driver\+Analog.\+h"{}}\newline
{\ttfamily \+\#include $<$string.\+h$>$}\newline
Include dependency graph for driver\+Analog.\+c:\+
\nopagebreak
\begin{figure}[H]
\begin{center}
\leavevmode
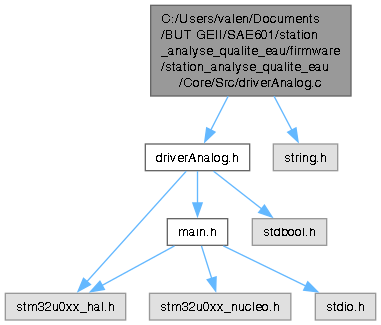
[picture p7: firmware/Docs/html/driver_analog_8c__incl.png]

\end{center}
\end{figure}
\doxysubsubsection*{Macros}
\begin{DoxyCompactItemize}
\item 
\+\#define \doxymbox{\hyperlink{driver_analog_8c_a391982875032f735379bc0dabd2ed7ed}{ANALOG\+\_\+\+PRINT}}(...)
\end{DoxyCompactItemize}
\doxysubsubsection*{Functions}
\begin{DoxyCompactItemize}
\item 
\doxymbox{\hyperlink{driver_analog_8h_af51dcdaed089c23aa51f7be006dc69c4}{Analog\+\_\+\+Result\+\_\+t}} \doxymbox{\hyperlink{driver_analog_8c_a866228196e63804439b8618f3549c297}{Analog\+\_\+\+Init}} (\doxymbox{\hyperlink{struct_analog__t}{Analog\+\_\+t}} \texorpdfstring{$\ast$}{*}hanalog, ADC\+\_\+\+Handle\+Type\+Def \texorpdfstring{$\ast$}{*}hadc)
\begin{DoxyCompactList}\small\item\em Initialise le driver analogique et lance la calibration matérielle. \end{DoxyCompactList}\item 
\doxymbox{\hyperlink{driver_analog_8h_af51dcdaed089c23aa51f7be006dc69c4}{Analog\+\_\+\+Result\+\_\+t}} \doxymbox{\hyperlink{driver_analog_8c_afee6bed3ae606eeebb59feda2dc2208b}{Analog\+\_\+\+Start}} (\doxymbox{\hyperlink{struct_analog__t}{Analog\+\_\+t}} \texorpdfstring{$\ast$}{*}hanalog)
\begin{DoxyCompactList}\small\item\em Demande le démarrage d\textquotesingle{}une nouvelle séquence de conversions. \end{DoxyCompactList}\item 
void \doxymbox{\hyperlink{driver_analog_8c_a9954dbb1a49b2e43a09dedc54a48d79c}{Analog\+\_\+\+Process}} (\doxymbox{\hyperlink{struct_analog__t}{Analog\+\_\+t}} \texorpdfstring{$\ast$}{*}hanalog)
\begin{DoxyCompactList}\small\item\em Machine d\textquotesingle{}état (FSM) gérant la séquence DMA, les timeouts et les calculs physiques. \end{DoxyCompactList}\item 
\doxymbox{\hyperlink{driver_analog_8h_a67e4ace606a4946983ae18c7f7970cbf}{Analog\+\_\+\+Status\+\_\+t}} \doxymbox{\hyperlink{driver_analog_8c_a53c52728e5f98bce7ffb92ea1ac6c21e}{Analog\+\_\+\+Get\+Status}} (\doxymbox{\hyperlink{struct_analog__t}{Analog\+\_\+t}} \texorpdfstring{$\ast$}{*}hanalog)
\begin{DoxyCompactList}\small\item\em Retourne le statut opérationnel actuel du driver. \end{DoxyCompactList}\item 
void \doxymbox{\hyperlink{driver_analog_8c_ad22fd8d893a43f1ba2c0ba4aa171efe8}{Analog\+\_\+\+Conv\+Cplt\+Callback}} (\doxymbox{\hyperlink{struct_analog__t}{Analog\+\_\+t}} \texorpdfstring{$\ast$}{*}hanalog)
\begin{DoxyCompactList}\small\item\em Fonction de rappel (Callback) à insérer dans l\textquotesingle{}interruption HAL\+\_\+\+ADC\+\_\+\+Conv\+Cplt\+Callback. \end{DoxyCompactList}\end{DoxyCompactItemize}

\label{driver_analog_8c_doc-define-members}
\Hypertarget{driver_analog_8c_doc-define-members}
\doxysubsection{Macro Definition Documentation}
\Hypertarget{driver_analog_8c_a391982875032f735379bc0dabd2ed7ed}\index{driverAnalog.c@{driverAnalog.c}!ANALOG\_PRINT@{ANALOG\_PRINT}}
\index{ANALOG\_PRINT@{ANALOG\_PRINT}!driverAnalog.c@{driverAnalog.c}}
\doxysubsubsection{\texorpdfstring{ANALOG\_PRINT}{ANALOG\_PRINT}}
{\footnotesize\ttfamily \label{driver_analog_8c_a391982875032f735379bc0dabd2ed7ed} 
\+\#define ANALOG\+\_\+\+PRINT(\begin{DoxyParamCaption}\item[{}]{}...{}\end{DoxyParamCaption})}

\label{driver_analog_8c_doc-func-members}
\Hypertarget{driver_analog_8c_doc-func-members}
\doxysubsection{Function Documentation}
\Hypertarget{driver_analog_8c_ad22fd8d893a43f1ba2c0ba4aa171efe8}\index{driverAnalog.c@{driverAnalog.c}!Analog\_ConvCpltCallback@{Analog\_ConvCpltCallback}}
\index{Analog\_ConvCpltCallback@{Analog\_ConvCpltCallback}!driverAnalog.c@{driverAnalog.c}}
\doxysubsubsection{\texorpdfstring{Analog\_ConvCpltCallback()}{Analog\_ConvCpltCallback()}}
{\footnotesize\ttfamily \label{driver_analog_8c_ad22fd8d893a43f1ba2c0ba4aa171efe8} 
void Analog\+\_\+\+Conv\+Cplt\+Callback (\begin{DoxyParamCaption}\item[{\doxymbox{\hyperlink{struct_analog__t}{Analog\+\_\+t}} \texorpdfstring{$\ast$}{*}}]{hanalog}{}\end{DoxyParamCaption})}

Fonction de rappel (Callback) à insérer dans l\textquotesingle{}interruption HAL\+\_\+\+ADC\+\_\+\+Conv\+Cplt\+Callback. 

\begin{DoxyNote}{Note}
Lève le drapeau de fin de conversion pour débloquer la machine d\textquotesingle{}état. 
\end{DoxyNote}

\begin{DoxyParams}{Parameters}
{\em hanalog} & Pointeur vers l\textquotesingle{}instance du driver Analogique. \\
\hline
\end{DoxyParams}
Here is the caller graph for this function:\+
\nopagebreak
\begin{figure}[H]
\begin{center}
\leavevmode

\end{center}
\end{figure}
\Hypertarget{driver_analog_8c_a53c52728e5f98bce7ffb92ea1ac6c21e}\index{driverAnalog.c@{driverAnalog.c}!Analog\_GetStatus@{Analog\_GetStatus}}
\index{Analog\_GetStatus@{Analog\_GetStatus}!driverAnalog.c@{driverAnalog.c}}
\doxysubsubsection{\texorpdfstring{Analog\_GetStatus()}{Analog\_GetStatus()}}
{\footnotesize\ttfamily \label{driver_analog_8c_a53c52728e5f98bce7ffb92ea1ac6c21e} 
\doxymbox{\hyperlink{driver_analog_8h_a67e4ace606a4946983ae18c7f7970cbf}{Analog\+\_\+\+Status\+\_\+t}} Analog\+\_\+\+Get\+Status (\begin{DoxyParamCaption}\item[{\doxymbox{\hyperlink{struct_analog__t}{Analog\+\_\+t}} \texorpdfstring{$\ast$}{*}}]{hanalog}{}\end{DoxyParamCaption})}

Retourne le statut opérationnel actuel du driver. 

\begin{DoxyParams}{Parameters}
{\em hanalog} & Pointeur vers l\textquotesingle{}instance du driver Analogique. \\
\hline
\end{DoxyParams}

\begin{DoxyRetVals}{Return values}
{\em ANALOG\+\_\+\+STATUS\+\_\+\+READY,ANALOG\+\_\+\+STATUS\+\_\+\+BUSY} & ou ANALOG\+\_\+\+STATUS\+\_\+\+ERROR. \\
\hline
\end{DoxyRetVals}
Here is the caller graph for this function:\+
\nopagebreak
\begin{figure}[H]
\begin{center}
\leavevmode

\end{center}
\end{figure}
\Hypertarget{driver_analog_8c_a866228196e63804439b8618f3549c297}\index{driverAnalog.c@{driverAnalog.c}!Analog\_Init@{Analog\_Init}}
\index{Analog\_Init@{Analog\_Init}!driverAnalog.c@{driverAnalog.c}}
\doxysubsubsection{\texorpdfstring{Analog\_Init()}{Analog\_Init()}}
{\footnotesize\ttfamily \label{driver_analog_8c_a866228196e63804439b8618f3549c297} 
\doxymbox{\hyperlink{driver_analog_8h_af51dcdaed089c23aa51f7be006dc69c4}{Analog\+\_\+\+Result\+\_\+t}} Analog\+\_\+\+Init (\begin{DoxyParamCaption}\item[{\doxymbox{\hyperlink{struct_analog__t}{Analog\+\_\+t}} \texorpdfstring{$\ast$}{*}}]{hanalog}{, }\item[{ADC\+\_\+\+Handle\+Type\+Def \texorpdfstring{$\ast$}{*}}]{hadc}{}\end{DoxyParamCaption})}

Initialise le driver analogique et lance la calibration matérielle. 

\begin{DoxyNote}{Note}
Doit être appelée une seule fois au démarrage de l\textquotesingle{}application. 
\end{DoxyNote}

\begin{DoxyParams}{Parameters}
{\em hanalog} & Pointeur vers l\textquotesingle{}instance du driver Analogique. \\
\hline
{\em hadc} & Pointeur vers le handle HAL de l\textquotesingle{}ADC (déjà initialisé par Cube\+MX). \\
\hline
\end{DoxyParams}

\begin{DoxyRetVals}{Return values}
{\em ANALOG\+\_\+\+OK} & en cas de succès, ANALOG\+\_\+\+ERR\+\_\+\+HAL si la calibration échoue. \\
\hline
\end{DoxyRetVals}
Here is the caller graph for this function:\+
\nopagebreak
\begin{figure}[H]
\begin{center}
\leavevmode

\end{center}
\end{figure}
\Hypertarget{driver_analog_8c_a9954dbb1a49b2e43a09dedc54a48d79c}\index{driverAnalog.c@{driverAnalog.c}!Analog\_Process@{Analog\_Process}}
\index{Analog\_Process@{Analog\_Process}!driverAnalog.c@{driverAnalog.c}}
\doxysubsubsection{\texorpdfstring{Analog\_Process()}{Analog\_Process()}}
{\footnotesize\ttfamily \label{driver_analog_8c_a9954dbb1a49b2e43a09dedc54a48d79c} 
void Analog\+\_\+\+Process (\begin{DoxyParamCaption}\item[{\doxymbox{\hyperlink{struct_analog__t}{Analog\+\_\+t}} \texorpdfstring{$\ast$}{*}}]{hanalog}{}\end{DoxyParamCaption})}

Machine d\textquotesingle{}état (FSM) gérant la séquence DMA, les timeouts et les calculs physiques. 

\begin{DoxyNote}{Note}
Doit être appelée régulièrement dans la boucle principale (main/\+while(1)). 
\end{DoxyNote}

\begin{DoxyParams}{Parameters}
{\em hanalog} & Pointeur vers l\textquotesingle{}instance du driver Analogique. \\
\hline
\end{DoxyParams}
Here is the caller graph for this function:\+
\nopagebreak
\begin{figure}[H]
\begin{center}
\leavevmode

\end{center}
\end{figure}
\Hypertarget{driver_analog_8c_afee6bed3ae606eeebb59feda2dc2208b}\index{driverAnalog.c@{driverAnalog.c}!Analog\_Start@{Analog\_Start}}
\index{Analog\_Start@{Analog\_Start}!driverAnalog.c@{driverAnalog.c}}
\doxysubsubsection{\texorpdfstring{Analog\_Start()}{Analog\_Start()}}
{\footnotesize\ttfamily \label{driver_analog_8c_afee6bed3ae606eeebb59feda2dc2208b} 
\doxymbox{\hyperlink{driver_analog_8h_af51dcdaed089c23aa51f7be006dc69c4}{Analog\+\_\+\+Result\+\_\+t}} Analog\+\_\+\+Start (\begin{DoxyParamCaption}\item[{\doxymbox{\hyperlink{struct_analog__t}{Analog\+\_\+t}} \texorpdfstring{$\ast$}{*}}]{hanalog}{}\end{DoxyParamCaption})}

Demande le démarrage d\textquotesingle{}une nouvelle séquence de conversions. 

\begin{DoxyParams}{Parameters}
{\em hanalog} & Pointeur vers l\textquotesingle{}instance du driver Analogique. \\
\hline
\end{DoxyParams}

\begin{DoxyRetVals}{Return values}
{\em ANALOG\+\_\+\+OK} & si la demande est acceptée, ANALOG\+\_\+\+ERR\+\_\+\+BUSY si l\textquotesingle{}ADC est déjà occupé. \\
\hline
\end{DoxyRetVals}
Here is the caller graph for this function:\+
\nopagebreak
\begin{figure}[H]
\begin{center}
\leavevmode

\end{center}
\end{figure}

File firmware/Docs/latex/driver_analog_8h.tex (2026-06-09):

\doxysection{C:\+/\+\+Users/\+valen/\+\+Documents/\+\+BUT GEII/\+\+SAE601/\+station\+\_\+analyse\+\_\+qualite\+\_\+eau/\+firmware/\+station\+\_\+analyse\+\_\+qualite\+\_\+eau/\+\+Core/\+\+Inc/\+driver\+Analog.h File Reference}
\hypertarget{driver_analog_8h}{}\label{driver_analog_8h}\index{C:/Users/valen/Documents/BUT GEII/SAE601/station\_analyse\_qualite\_eau/firmware/station\_analyse\_qualite\_eau/Core/Inc/driverAnalog.h@{C:/Users/valen/Documents/BUT GEII/SAE601/station\_analyse\_qualite\_eau/firmware/station\_analyse\_qualite\_eau/Core/Inc/driverAnalog.h}}

Pilote d\textquotesingle{}acquisition analogique (ADC) asynchrone avec monitoring.  

{\ttfamily \+\#include "{}main.\+h"{}}\newline
{\ttfamily \+\#include "{}stm32u0xx\+\_\+hal.\+h"{}}\newline
{\ttfamily \+\#include $<$stdbool.\+h$>$}\newline
Include dependency graph for driver\+Analog.\+h:\+
\nopagebreak
\begin{figure}[H]
\begin{center}
\leavevmode
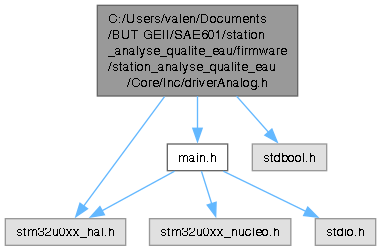
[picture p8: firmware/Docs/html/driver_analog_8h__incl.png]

\end{center}
\end{figure}
This graph shows which files directly or indirectly include this file:\+
\nopagebreak
\begin{figure}[H]
\begin{center}
\leavevmode
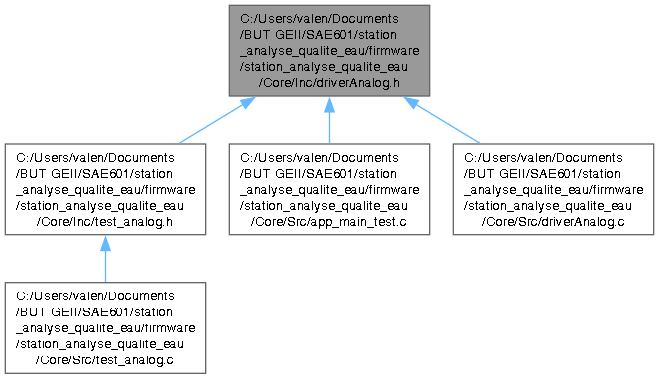
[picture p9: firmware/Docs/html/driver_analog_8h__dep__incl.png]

\end{center}
\end{figure}
\doxysubsubsection*{Data Structures}
\begin{DoxyCompactItemize}
\item 
struct \doxymbox{\hyperlink{struct_analog__t}{Analog\+\_\+t}}
\begin{DoxyCompactList}\small\item\em Contexte d\textquotesingle{}exécution global du driver analogique. \end{DoxyCompactList}\end{DoxyCompactItemize}
\doxysubsubsection*{Macros}
\begin{DoxyCompactItemize}
\item 
\+\#define \doxymbox{\hyperlink{driver_analog_8h_a2b253ff8dc858bafc4bb77978b98b521}{NBR\+\_\+\+ANALOG\+\_\+\+SENSOR}}~4U
\begin{DoxyCompactList}\small\item\em Nombre total de canaux convertis par la séquence ADC (Ranks). \end{DoxyCompactList}\item 
\+\#define \doxymbox{\hyperlink{driver_analog_8h_ab740447b0224929bac4b8378412d02af}{ATTENUATOR\+\_\+\+MULTIPLICATOR}}~2.\+0f
\begin{DoxyCompactList}\small\item\em Coefficient multiplicateur pour compenser un pont diviseur externe. \end{DoxyCompactList}\item 
\+\#define \doxymbox{\hyperlink{driver_analog_8h_ae098a09e49608e9ff36d34690288a6b7}{ADC\+\_\+\+MAX\+\_\+\+RESOLUTION\+\_\+12B}}~4095.\+0f
\begin{DoxyCompactList}\small\item\em Valeur maximale d\textquotesingle{}un ADC 12 bits (Utilisé pour éviter le conflit avec la macro HAL). \end{DoxyCompactList}\end{DoxyCompactItemize}
\doxysubsubsection*{Enumerations}
\begin{DoxyCompactItemize}
\item 
enum \doxymbox{\hyperlink{driver_analog_8h_af51dcdaed089c23aa51f7be006dc69c4}{Analog\+\_\+\+Result\+\_\+t}} \{ \doxymbox{\hyperlink{driver_analog_8h_af51dcdaed089c23aa51f7be006dc69c4ac393781bf1cc6966378f70ad49d2d401}{ANALOG\+\_\+\+OK}} = 0
, \doxymbox{\hyperlink{driver_analog_8h_af51dcdaed089c23aa51f7be006dc69c4ad2b216ef435441a04c9c311c2d78b2e5}{ANALOG\+\_\+\+ERR\+\_\+\+PARAM}}
, \doxymbox{\hyperlink{driver_analog_8h_af51dcdaed089c23aa51f7be006dc69c4ac38d730ab0d0d0589b85858413cc7be5}{ANALOG\+\_\+\+ERR\+\_\+\+BUSY}}
, \doxymbox{\hyperlink{driver_analog_8h_af51dcdaed089c23aa51f7be006dc69c4a4a876a3a82aa5dfc59a3a34a53afbeb5}{ANALOG\+\_\+\+ERR\+\_\+\+HAL}}
 \}
\begin{DoxyCompactList}\small\item\em Code de retour immédiat pour les appels de l\textquotesingle{}API. \end{DoxyCompactList}\item 
enum \doxymbox{\hyperlink{driver_analog_8h_a67e4ace606a4946983ae18c7f7970cbf}{Analog\+\_\+\+Status\+\_\+t}} \{ \doxymbox{\hyperlink{driver_analog_8h_a67e4ace606a4946983ae18c7f7970cbfad13798b1a3a04a689d20668d92f74206}{ANALOG\+\_\+\+STATUS\+\_\+\+READY}} = 0
, \doxymbox{\hyperlink{driver_analog_8h_a67e4ace606a4946983ae18c7f7970cbfad77efc015db0617891c3e4ca2f3e27c8}{ANALOG\+\_\+\+STATUS\+\_\+\+BUSY}}
, \doxymbox{\hyperlink{driver_analog_8h_a67e4ace606a4946983ae18c7f7970cbfa20b1ce2712ac17b9da25f7960054e5f0}{ANALOG\+\_\+\+STATUS\+\_\+\+ERROR}}
 \}
\begin{DoxyCompactList}\small\item\em Statut opérationnel global du driver analogique. \end{DoxyCompactList}\item 
enum \doxymbox{\hyperlink{driver_analog_8h_a265ba346976a3893bb384d3e9f56bb78}{Analog\+\_\+\+State\+\_\+t}} \{ \doxymbox{\hyperlink{driver_analog_8h_a265ba346976a3893bb384d3e9f56bb78afdd294605d2bf321eca2690912324dc1}{ANALOG\+\_\+\+IDLE}} = 0
, \doxymbox{\hyperlink{driver_analog_8h_a265ba346976a3893bb384d3e9f56bb78a5b03926559a2e874c06cb683f09d651d}{ANALOG\+\_\+\+START\+\_\+\+CONVERSION}}
, \doxymbox{\hyperlink{driver_analog_8h_a265ba346976a3893bb384d3e9f56bb78ac3bc92d03e3d0da3b6ca6c5fb7d1f50f}{ANALOG\+\_\+\+WAIT\+\_\+\+CONVERSION}}
, \doxymbox{\hyperlink{driver_analog_8h_a265ba346976a3893bb384d3e9f56bb78a01963c6df14ab6d04f7d154bf9aa6476}{ANALOG\+\_\+\+PROCESS\+\_\+\+DATA}}
 \}
\begin{DoxyCompactList}\small\item\em États internes de la machine d\textquotesingle{}état (FSM). \end{DoxyCompactList}\end{DoxyCompactItemize}
\doxysubsubsection*{Functions}
\begin{DoxyCompactItemize}
\item 
\doxymbox{\hyperlink{driver_analog_8h_af51dcdaed089c23aa51f7be006dc69c4}{Analog\+\_\+\+Result\+\_\+t}} \doxymbox{\hyperlink{driver_analog_8h_a866228196e63804439b8618f3549c297}{Analog\+\_\+\+Init}} (\doxymbox{\hyperlink{struct_analog__t}{Analog\+\_\+t}} \texorpdfstring{$\ast$}{*}hanalog, ADC\+\_\+\+Handle\+Type\+Def \texorpdfstring{$\ast$}{*}hadc)
\begin{DoxyCompactList}\small\item\em Initialise le driver analogique et lance la calibration matérielle. \end{DoxyCompactList}\item 
\doxymbox{\hyperlink{driver_analog_8h_af51dcdaed089c23aa51f7be006dc69c4}{Analog\+\_\+\+Result\+\_\+t}} \doxymbox{\hyperlink{driver_analog_8h_afee6bed3ae606eeebb59feda2dc2208b}{Analog\+\_\+\+Start}} (\doxymbox{\hyperlink{struct_analog__t}{Analog\+\_\+t}} \texorpdfstring{$\ast$}{*}hanalog)
\begin{DoxyCompactList}\small\item\em Demande le démarrage d\textquotesingle{}une nouvelle séquence de conversions. \end{DoxyCompactList}\item 
void \doxymbox{\hyperlink{driver_analog_8h_a9954dbb1a49b2e43a09dedc54a48d79c}{Analog\+\_\+\+Process}} (\doxymbox{\hyperlink{struct_analog__t}{Analog\+\_\+t}} \texorpdfstring{$\ast$}{*}hanalog)
\begin{DoxyCompactList}\small\item\em Machine d\textquotesingle{}état (FSM) gérant la séquence DMA, les timeouts et les calculs physiques. \end{DoxyCompactList}\item 
\doxymbox{\hyperlink{driver_analog_8h_a67e4ace606a4946983ae18c7f7970cbf}{Analog\+\_\+\+Status\+\_\+t}} \doxymbox{\hyperlink{driver_analog_8h_a53c52728e5f98bce7ffb92ea1ac6c21e}{Analog\+\_\+\+Get\+Status}} (\doxymbox{\hyperlink{struct_analog__t}{Analog\+\_\+t}} \texorpdfstring{$\ast$}{*}hanalog)
\begin{DoxyCompactList}\small\item\em Retourne le statut opérationnel actuel du driver. \end{DoxyCompactList}\item 
void \doxymbox{\hyperlink{driver_analog_8h_ad22fd8d893a43f1ba2c0ba4aa171efe8}{Analog\+\_\+\+Conv\+Cplt\+Callback}} (\doxymbox{\hyperlink{struct_analog__t}{Analog\+\_\+t}} \texorpdfstring{$\ast$}{*}hanalog)
\begin{DoxyCompactList}\small\item\em Fonction de rappel (Callback) à insérer dans l\textquotesingle{}interruption HAL\+\_\+\+ADC\+\_\+\+Conv\+Cplt\+Callback. \end{DoxyCompactList}\end{DoxyCompactItemize}

\doxysubsection{Detailed Description}
Pilote d\textquotesingle{}acquisition analogique (ADC) asynchrone avec monitoring. 

\begin{DoxyAuthor}{Author}
\+[Ton Nom/\+\+Projet]\+ 
\end{DoxyAuthor}
\begin{DoxyDate}{Date}
\+[Date actuelle]\+
\end{DoxyDate}
Ce module gère l\textquotesingle{}acquisition de capteurs analogiques externes et internes (Température MCU, VREFINT, VBAT) via le DMA du STM32 pour un fonctionnement 100\% non-\/bloquant.
\begin{DoxyItemize}
\item Il intègre une compensation dynamique de la tension d\textquotesingle{}alimentation (VDDA) basée sur la lecture de la référence interne (VREFINT), garantissant des mesures précises même lors de la décharge d\textquotesingle{}une batterie.
\end{DoxyItemize}

\begin{DoxyNote}{Note}
L\textquotesingle{}ordre des conversions dans Cube\+MX doit correspondre aux index :\+
\begin{DoxyItemize}
\item Index 0, 1 :\+ Capteurs externes (ex:\+ C1, C2)
\item Index 2 :\+ VREFINT Channel
\item Index 3 :\+ Temperature Sensor Channel
\item Index 4 :\+ Vbat Channel 
\end{DoxyItemize}
\end{DoxyNote}

\label{driver_analog_8h_doc-define-members}
\Hypertarget{driver_analog_8h_doc-define-members}
\doxysubsection{Macro Definition Documentation}
\Hypertarget{driver_analog_8h_ae098a09e49608e9ff36d34690288a6b7}\index{driverAnalog.h@{driverAnalog.h}!ADC\_MAX\_RESOLUTION\_12B@{ADC\_MAX\_RESOLUTION\_12B}}
\index{ADC\_MAX\_RESOLUTION\_12B@{ADC\_MAX\_RESOLUTION\_12B}!driverAnalog.h@{driverAnalog.h}}
\doxysubsubsection{\texorpdfstring{ADC\_MAX\_RESOLUTION\_12B}{ADC\_MAX\_RESOLUTION\_12B}}
{\footnotesize\ttfamily \label{driver_analog_8h_ae098a09e49608e9ff36d34690288a6b7} 
\+\#define ADC\+\_\+\+MAX\+\_\+\+RESOLUTION\+\_\+12B~4095.\+0f}

Valeur maximale d\textquotesingle{}un ADC 12 bits (Utilisé pour éviter le conflit avec la macro HAL). 

\Hypertarget{driver_analog_8h_ab740447b0224929bac4b8378412d02af}\index{driverAnalog.h@{driverAnalog.h}!ATTENUATOR\_MULTIPLICATOR@{ATTENUATOR\_MULTIPLICATOR}}
\index{ATTENUATOR\_MULTIPLICATOR@{ATTENUATOR\_MULTIPLICATOR}!driverAnalog.h@{driverAnalog.h}}
\doxysubsubsection{\texorpdfstring{ATTENUATOR\_MULTIPLICATOR}{ATTENUATOR\_MULTIPLICATOR}}
{\footnotesize\ttfamily \label{driver_analog_8h_ab740447b0224929bac4b8378412d02af} 
\+\#define ATTENUATOR\+\_\+\+MULTIPLICATOR~2.\+0f}

Coefficient multiplicateur pour compenser un pont diviseur externe. 

\Hypertarget{driver_analog_8h_a2b253ff8dc858bafc4bb77978b98b521}\index{driverAnalog.h@{driverAnalog.h}!NBR\_ANALOG\_SENSOR@{NBR\_ANALOG\_SENSOR}}
\index{NBR\_ANALOG\_SENSOR@{NBR\_ANALOG\_SENSOR}!driverAnalog.h@{driverAnalog.h}}
\doxysubsubsection{\texorpdfstring{NBR\_ANALOG\_SENSOR}{NBR\_ANALOG\_SENSOR}}
{\footnotesize\ttfamily \label{driver_analog_8h_a2b253ff8dc858bafc4bb77978b98b521} 
\+\#define NBR\+\_\+\+ANALOG\+\_\+\+SENSOR~4U}

Nombre total de canaux convertis par la séquence ADC (Ranks). 

\label{driver_analog_8h_doc-enum-members}
\Hypertarget{driver_analog_8h_doc-enum-members}
\doxysubsection{Enumeration Type Documentation}
\Hypertarget{driver_analog_8h_af51dcdaed089c23aa51f7be006dc69c4}\index{driverAnalog.h@{driverAnalog.h}!Analog\_Result\_t@{Analog\_Result\_t}}
\index{Analog\_Result\_t@{Analog\_Result\_t}!driverAnalog.h@{driverAnalog.h}}
\doxysubsubsection{\texorpdfstring{Analog\_Result\_t}{Analog\_Result\_t}}
{\footnotesize\ttfamily \label{driver_analog_8h_af51dcdaed089c23aa51f7be006dc69c4} 
enum \doxymbox{\hyperlink{driver_analog_8h_af51dcdaed089c23aa51f7be006dc69c4}{Analog\+\_\+\+Result\+\_\+t}}}

Code de retour immédiat pour les appels de l\textquotesingle{}API. 

\begin{DoxyEnumFields}[2]{Enumerator}
\raisebox{\heightof{T}}[0pt][0pt]{\index{ANALOG\_OK@{ANALOG\_OK}!driverAnalog.h@{driverAnalog.h}}
\index{driverAnalog.h@{driverAnalog.h}!ANALOG\_OK@{ANALOG\_OK}}
}\Hypertarget{driver_analog_8h_af51dcdaed089c23aa51f7be006dc69c4ac393781bf1cc6966378f70ad49d2d401}\label{driver_analog_8h_af51dcdaed089c23aa51f7be006dc69c4ac393781bf1cc6966378f70ad49d2d401} 
ANALOG\+\_\+\+OK&Opération acceptée avec succès \\
\hline

\raisebox{\heightof{T}}[0pt][0pt]{\index{ANALOG\_ERR\_PARAM@{ANALOG\_ERR\_PARAM}!driverAnalog.h@{driverAnalog.h}}
\index{driverAnalog.h@{driverAnalog.h}!ANALOG\_ERR\_PARAM@{ANALOG\_ERR\_PARAM}}
}\Hypertarget{driver_analog_8h_af51dcdaed089c23aa51f7be006dc69c4ad2b216ef435441a04c9c311c2d78b2e5}\label{driver_analog_8h_af51dcdaed089c23aa51f7be006dc69c4ad2b216ef435441a04c9c311c2d78b2e5} 
ANALOG\+\_\+\+ERR\+\_\+\+PARAM&Erreur de paramètre (ex:\+ pointeur NULL) \\
\hline

\raisebox{\heightof{T}}[0pt][0pt]{\index{ANALOG\_ERR\_BUSY@{ANALOG\_ERR\_BUSY}!driverAnalog.h@{driverAnalog.h}}
\index{driverAnalog.h@{driverAnalog.h}!ANALOG\_ERR\_BUSY@{ANALOG\_ERR\_BUSY}}
}\Hypertarget{driver_analog_8h_af51dcdaed089c23aa51f7be006dc69c4ac38d730ab0d0d0589b85858413cc7be5}\label{driver_analog_8h_af51dcdaed089c23aa51f7be006dc69c4ac38d730ab0d0d0589b85858413cc7be5} 
ANALOG\+\_\+\+ERR\+\_\+\+BUSY&Refus :\+ Une conversion DMA est déjà en cours \\
\hline

\raisebox{\heightof{T}}[0pt][0pt]{\index{ANALOG\_ERR\_HAL@{ANALOG\_ERR\_HAL}!driverAnalog.h@{driverAnalog.h}}
\index{driverAnalog.h@{driverAnalog.h}!ANALOG\_ERR\_HAL@{ANALOG\_ERR\_HAL}}
}\Hypertarget{driver_analog_8h_af51dcdaed089c23aa51f7be006dc69c4a4a876a3a82aa5dfc59a3a34a53afbeb5}\label{driver_analog_8h_af51dcdaed089c23aa51f7be006dc69c4a4a876a3a82aa5dfc59a3a34a53afbeb5} 
ANALOG\+\_\+\+ERR\+\_\+\+HAL&Erreur retournée par la couche d\textquotesingle{}abstraction matérielle (HAL) \\
\hline

\end{DoxyEnumFields}
\Hypertarget{driver_analog_8h_a265ba346976a3893bb384d3e9f56bb78}\index{driverAnalog.h@{driverAnalog.h}!Analog\_State\_t@{Analog\_State\_t}}
\index{Analog\_State\_t@{Analog\_State\_t}!driverAnalog.h@{driverAnalog.h}}
\doxysubsubsection{\texorpdfstring{Analog\_State\_t}{Analog\_State\_t}}
{\footnotesize\ttfamily \label{driver_analog_8h_a265ba346976a3893bb384d3e9f56bb78} 
enum \doxymbox{\hyperlink{driver_analog_8h_a265ba346976a3893bb384d3e9f56bb78}{Analog\+\_\+\+State\+\_\+t}}}

États internes de la machine d\textquotesingle{}état (FSM). 

\begin{DoxyNote}{Note}
À usage interne par \doxylink{driver_analog_8h_a9954dbb1a49b2e43a09dedc54a48d79c}{Analog\+\_\+\+Process()}. 
\end{DoxyNote}
\begin{DoxyEnumFields}[2]{Enumerator}
\raisebox{\heightof{T}}[0pt][0pt]{\index{ANALOG\_IDLE@{ANALOG\_IDLE}!driverAnalog.h@{driverAnalog.h}}
\index{driverAnalog.h@{driverAnalog.h}!ANALOG\_IDLE@{ANALOG\_IDLE}}
}\Hypertarget{driver_analog_8h_a265ba346976a3893bb384d3e9f56bb78afdd294605d2bf321eca2690912324dc1}\label{driver_analog_8h_a265ba346976a3893bb384d3e9f56bb78afdd294605d2bf321eca2690912324dc1} 
ANALOG\+\_\+\+IDLE&Repos, attente d\textquotesingle{}une commande Start \\
\hline

\raisebox{\heightof{T}}[0pt][0pt]{\index{ANALOG\_START\_CONVERSION@{ANALOG\_START\_CONVERSION}!driverAnalog.h@{driverAnalog.h}}
\index{driverAnalog.h@{driverAnalog.h}!ANALOG\_START\_CONVERSION@{ANALOG\_START\_CONVERSION}}
}\Hypertarget{driver_analog_8h_a265ba346976a3893bb384d3e9f56bb78a5b03926559a2e874c06cb683f09d651d}\label{driver_analog_8h_a265ba346976a3893bb384d3e9f56bb78a5b03926559a2e874c06cb683f09d651d} 
ANALOG\+\_\+\+START\+\_\+\+CONVERSION&Lancement matériel de la séquence DMA \\
\hline

\raisebox{\heightof{T}}[0pt][0pt]{\index{ANALOG\_WAIT\_CONVERSION@{ANALOG\_WAIT\_CONVERSION}!driverAnalog.h@{driverAnalog.h}}
\index{driverAnalog.h@{driverAnalog.h}!ANALOG\_WAIT\_CONVERSION@{ANALOG\_WAIT\_CONVERSION}}
}\Hypertarget{driver_analog_8h_a265ba346976a3893bb384d3e9f56bb78ac3bc92d03e3d0da3b6ca6c5fb7d1f50f}\label{driver_analog_8h_a265ba346976a3893bb384d3e9f56bb78ac3bc92d03e3d0da3b6ca6c5fb7d1f50f} 
ANALOG\+\_\+\+WAIT\+\_\+\+CONVERSION&Attente du flag de fin d\textquotesingle{}interruption DMA avec Timeout \\
\hline

\raisebox{\heightof{T}}[0pt][0pt]{\index{ANALOG\_PROCESS\_DATA@{ANALOG\_PROCESS\_DATA}!driverAnalog.h@{driverAnalog.h}}
\index{driverAnalog.h@{driverAnalog.h}!ANALOG\_PROCESS\_DATA@{ANALOG\_PROCESS\_DATA}}
}\Hypertarget{driver_analog_8h_a265ba346976a3893bb384d3e9f56bb78a01963c6df14ab6d04f7d154bf9aa6476}\label{driver_analog_8h_a265ba346976a3893bb384d3e9f56bb78a01963c6df14ab6d04f7d154bf9aa6476} 
ANALOG\+\_\+\+PROCESS\+\_\+\+DATA&Calculs de compensation et conversion bits vers valeurs physiques \\
\hline

\end{DoxyEnumFields}
\Hypertarget{driver_analog_8h_a67e4ace606a4946983ae18c7f7970cbf}\index{driverAnalog.h@{driverAnalog.h}!Analog\_Status\_t@{Analog\_Status\_t}}
\index{Analog\_Status\_t@{Analog\_Status\_t}!driverAnalog.h@{driverAnalog.h}}
\doxysubsubsection{\texorpdfstring{Analog\_Status\_t}{Analog\_Status\_t}}
{\footnotesize\ttfamily \label{driver_analog_8h_a67e4ace606a4946983ae18c7f7970cbf} 
enum \doxymbox{\hyperlink{driver_analog_8h_a67e4ace606a4946983ae18c7f7970cbf}{Analog\+\_\+\+Status\+\_\+t}}}

Statut opérationnel global du driver analogique. 

\begin{DoxyEnumFields}[2]{Enumerator}
\raisebox{\heightof{T}}[0pt][0pt]{\index{ANALOG\_STATUS\_READY@{ANALOG\_STATUS\_READY}!driverAnalog.h@{driverAnalog.h}}
\index{driverAnalog.h@{driverAnalog.h}!ANALOG\_STATUS\_READY@{ANALOG\_STATUS\_READY}}
}\Hypertarget{driver_analog_8h_a67e4ace606a4946983ae18c7f7970cbfad13798b1a3a04a689d20668d92f74206}\label{driver_analog_8h_a67e4ace606a4946983ae18c7f7970cbfad13798b1a3a04a689d20668d92f74206} 
ANALOG\+\_\+\+STATUS\+\_\+\+READY&Driver prêt à lancer une nouvelle séquence de conversion \\
\hline

\raisebox{\heightof{T}}[0pt][0pt]{\index{ANALOG\_STATUS\_BUSY@{ANALOG\_STATUS\_BUSY}!driverAnalog.h@{driverAnalog.h}}
\index{driverAnalog.h@{driverAnalog.h}!ANALOG\_STATUS\_BUSY@{ANALOG\_STATUS\_BUSY}}
}\Hypertarget{driver_analog_8h_a67e4ace606a4946983ae18c7f7970cbfad77efc015db0617891c3e4ca2f3e27c8}\label{driver_analog_8h_a67e4ace606a4946983ae18c7f7970cbfad77efc015db0617891c3e4ca2f3e27c8} 
ANALOG\+\_\+\+STATUS\+\_\+\+BUSY&Séquence de conversion DMA et traitement mathématique en cours \\
\hline

\raisebox{\heightof{T}}[0pt][0pt]{\index{ANALOG\_STATUS\_ERROR@{ANALOG\_STATUS\_ERROR}!driverAnalog.h@{driverAnalog.h}}
\index{driverAnalog.h@{driverAnalog.h}!ANALOG\_STATUS\_ERROR@{ANALOG\_STATUS\_ERROR}}
}\Hypertarget{driver_analog_8h_a67e4ace606a4946983ae18c7f7970cbfa20b1ce2712ac17b9da25f7960054e5f0}\label{driver_analog_8h_a67e4ace606a4946983ae18c7f7970cbfa20b1ce2712ac17b9da25f7960054e5f0} 
ANALOG\+\_\+\+STATUS\+\_\+\+ERROR&Erreur critique (ex:\+ Timeout DMA, échec de calibration) \\
\hline

\end{DoxyEnumFields}

\label{driver_analog_8h_doc-func-members}
\Hypertarget{driver_analog_8h_doc-func-members}
\doxysubsection{Function Documentation}
\Hypertarget{driver_analog_8h_ad22fd8d893a43f1ba2c0ba4aa171efe8}\index{driverAnalog.h@{driverAnalog.h}!Analog\_ConvCpltCallback@{Analog\_ConvCpltCallback}}
\index{Analog\_ConvCpltCallback@{Analog\_ConvCpltCallback}!driverAnalog.h@{driverAnalog.h}}
\doxysubsubsection{\texorpdfstring{Analog\_ConvCpltCallback()}{Analog\_ConvCpltCallback()}}
{\footnotesize\ttfamily \label{driver_analog_8h_ad22fd8d893a43f1ba2c0ba4aa171efe8} 
void Analog\+\_\+\+Conv\+Cplt\+Callback (\begin{DoxyParamCaption}\item[{\doxymbox{\hyperlink{struct_analog__t}{Analog\+\_\+t}} \texorpdfstring{$\ast$}{*}}]{hanalog}{}\end{DoxyParamCaption})}

Fonction de rappel (Callback) à insérer dans l\textquotesingle{}interruption HAL\+\_\+\+ADC\+\_\+\+Conv\+Cplt\+Callback. 

\begin{DoxyNote}{Note}
Lève le drapeau de fin de conversion pour débloquer la machine d\textquotesingle{}état. 
\end{DoxyNote}

\begin{DoxyParams}{Parameters}
{\em hanalog} & Pointeur vers l\textquotesingle{}instance du driver Analogique. \\
\hline
\end{DoxyParams}
Here is the caller graph for this function:\+
\nopagebreak
\begin{figure}[H]
\begin{center}
\leavevmode

\end{center}
\end{figure}
\Hypertarget{driver_analog_8h_a53c52728e5f98bce7ffb92ea1ac6c21e}\index{driverAnalog.h@{driverAnalog.h}!Analog\_GetStatus@{Analog\_GetStatus}}
\index{Analog\_GetStatus@{Analog\_GetStatus}!driverAnalog.h@{driverAnalog.h}}
\doxysubsubsection{\texorpdfstring{Analog\_GetStatus()}{Analog\_GetStatus()}}
{\footnotesize\ttfamily \label{driver_analog_8h_a53c52728e5f98bce7ffb92ea1ac6c21e} 
\doxymbox{\hyperlink{driver_analog_8h_a67e4ace606a4946983ae18c7f7970cbf}{Analog\+\_\+\+Status\+\_\+t}} Analog\+\_\+\+Get\+Status (\begin{DoxyParamCaption}\item[{\doxymbox{\hyperlink{struct_analog__t}{Analog\+\_\+t}} \texorpdfstring{$\ast$}{*}}]{hanalog}{}\end{DoxyParamCaption})}

Retourne le statut opérationnel actuel du driver. 

\begin{DoxyParams}{Parameters}
{\em hanalog} & Pointeur vers l\textquotesingle{}instance du driver Analogique. \\
\hline
\end{DoxyParams}

\begin{DoxyRetVals}{Return values}
{\em ANALOG\+\_\+\+STATUS\+\_\+\+READY,ANALOG\+\_\+\+STATUS\+\_\+\+BUSY} & ou ANALOG\+\_\+\+STATUS\+\_\+\+ERROR. \\
\hline
\end{DoxyRetVals}
Here is the caller graph for this function:\+
\nopagebreak
\begin{figure}[H]
\begin{center}
\leavevmode

\end{center}
\end{figure}
\Hypertarget{driver_analog_8h_a866228196e63804439b8618f3549c297}\index{driverAnalog.h@{driverAnalog.h}!Analog\_Init@{Analog\_Init}}
\index{Analog\_Init@{Analog\_Init}!driverAnalog.h@{driverAnalog.h}}
\doxysubsubsection{\texorpdfstring{Analog\_Init()}{Analog\_Init()}}
{\footnotesize\ttfamily \label{driver_analog_8h_a866228196e63804439b8618f3549c297} 
\doxymbox{\hyperlink{driver_analog_8h_af51dcdaed089c23aa51f7be006dc69c4}{Analog\+\_\+\+Result\+\_\+t}} Analog\+\_\+\+Init (\begin{DoxyParamCaption}\item[{\doxymbox{\hyperlink{struct_analog__t}{Analog\+\_\+t}} \texorpdfstring{$\ast$}{*}}]{hanalog}{, }\item[{ADC\+\_\+\+Handle\+Type\+Def \texorpdfstring{$\ast$}{*}}]{hadc}{}\end{DoxyParamCaption})}

Initialise le driver analogique et lance la calibration matérielle. 

\begin{DoxyNote}{Note}
Doit être appelée une seule fois au démarrage de l\textquotesingle{}application. 
\end{DoxyNote}

\begin{DoxyParams}{Parameters}
{\em hanalog} & Pointeur vers l\textquotesingle{}instance du driver Analogique. \\
\hline
{\em hadc} & Pointeur vers le handle HAL de l\textquotesingle{}ADC (déjà initialisé par Cube\+MX). \\
\hline
\end{DoxyParams}

\begin{DoxyRetVals}{Return values}
{\em ANALOG\+\_\+\+OK} & en cas de succès, ANALOG\+\_\+\+ERR\+\_\+\+HAL si la calibration échoue. \\
\hline
\end{DoxyRetVals}
Here is the caller graph for this function:\+
\nopagebreak
\begin{figure}[H]
\begin{center}
\leavevmode

\end{center}
\end{figure}
\Hypertarget{driver_analog_8h_a9954dbb1a49b2e43a09dedc54a48d79c}\index{driverAnalog.h@{driverAnalog.h}!Analog\_Process@{Analog\_Process}}
\index{Analog\_Process@{Analog\_Process}!driverAnalog.h@{driverAnalog.h}}
\doxysubsubsection{\texorpdfstring{Analog\_Process()}{Analog\_Process()}}
{\footnotesize\ttfamily \label{driver_analog_8h_a9954dbb1a49b2e43a09dedc54a48d79c} 
void Analog\+\_\+\+Process (\begin{DoxyParamCaption}\item[{\doxymbox{\hyperlink{struct_analog__t}{Analog\+\_\+t}} \texorpdfstring{$\ast$}{*}}]{hanalog}{}\end{DoxyParamCaption})}

Machine d\textquotesingle{}état (FSM) gérant la séquence DMA, les timeouts et les calculs physiques. 

\begin{DoxyNote}{Note}
Doit être appelée régulièrement dans la boucle principale (main/\+while(1)). 
\end{DoxyNote}

\begin{DoxyParams}{Parameters}
{\em hanalog} & Pointeur vers l\textquotesingle{}instance du driver Analogique. \\
\hline
\end{DoxyParams}
Here is the caller graph for this function:\+
\nopagebreak
\begin{figure}[H]
\begin{center}
\leavevmode

\end{center}
\end{figure}
\Hypertarget{driver_analog_8h_afee6bed3ae606eeebb59feda2dc2208b}\index{driverAnalog.h@{driverAnalog.h}!Analog\_Start@{Analog\_Start}}
\index{Analog\_Start@{Analog\_Start}!driverAnalog.h@{driverAnalog.h}}
\doxysubsubsection{\texorpdfstring{Analog\_Start()}{Analog\_Start()}}
{\footnotesize\ttfamily \label{driver_analog_8h_afee6bed3ae606eeebb59feda2dc2208b} 
\doxymbox{\hyperlink{driver_analog_8h_af51dcdaed089c23aa51f7be006dc69c4}{Analog\+\_\+\+Result\+\_\+t}} Analog\+\_\+\+Start (\begin{DoxyParamCaption}\item[{\doxymbox{\hyperlink{struct_analog__t}{Analog\+\_\+t}} \texorpdfstring{$\ast$}{*}}]{hanalog}{}\end{DoxyParamCaption})}

Demande le démarrage d\textquotesingle{}une nouvelle séquence de conversions. 

\begin{DoxyParams}{Parameters}
{\em hanalog} & Pointeur vers l\textquotesingle{}instance du driver Analogique. \\
\hline
\end{DoxyParams}

\begin{DoxyRetVals}{Return values}
{\em ANALOG\+\_\+\+OK} & si la demande est acceptée, ANALOG\+\_\+\+ERR\+\_\+\+BUSY si l\textquotesingle{}ADC est déjà occupé. \\
\hline
\end{DoxyRetVals}
Here is the caller graph for this function:\+
\nopagebreak
\begin{figure}[H]
\begin{center}
\leavevmode

\end{center}
\end{figure}

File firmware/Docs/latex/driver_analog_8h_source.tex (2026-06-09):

\doxysection{driver\+Analog.\+h}
\hypertarget{driver_analog_8h_source}{}\label{driver_analog_8h_source}\index{C:/Users/valen/Documents/BUT GEII/SAE601/station\_analyse\_qualite\_eau/firmware/station\_analyse\_qualite\_eau/Core/Inc/driverAnalog.h@{C:/Users/valen/Documents/BUT GEII/SAE601/station\_analyse\_qualite\_eau/firmware/station\_analyse\_qualite\_eau/Core/Inc/driverAnalog.h}}
\doxymbox{\hyperlink{driver_analog_8h}{Go to the documentation of this file.}}
\begin{DoxyCode}{0}
\DoxyCodeLine{00001\ }
\DoxyCodeLine{00023\ }
\DoxyCodeLine{00024\ \textcolor{preprocessor}{\#ifndef\ INC\_DRIVERANALOG\_H\_}}
\DoxyCodeLine{00025\ \textcolor{preprocessor}{\#define\ INC\_DRIVERANALOG\_H\_}}
\DoxyCodeLine{00026\ }
\DoxyCodeLine{00027\ \textcolor{preprocessor}{\#include\ "{}\doxymbox{\hyperlink{main_8h}{main.h}}"{}}}
\DoxyCodeLine{00028\ \textcolor{preprocessor}{\#include\ "{}stm32u0xx\_hal.h"{}}}
\DoxyCodeLine{00029\ \textcolor{preprocessor}{\#include\ <stdbool.h>}}
\DoxyCodeLine{00030\ }
\DoxyCodeLine{00031\ \textcolor{comment}{/*\ ==========================================================================}}
\DoxyCodeLine{00032\ \textcolor{comment}{\ *\ CONFIGURATION\ DU\ DRIVER}}
\DoxyCodeLine{00033\ \textcolor{comment}{\ *\ ==========================================================================\ */}}
\DoxyCodeLine{00034\ }
\DoxyCodeLine{00036\ \textcolor{preprocessor}{\#define\ NBR\_ANALOG\_SENSOR\ \ \ \ \ \ \ \ \ \ \ 4U}}
\DoxyCodeLine{00037\ }
\DoxyCodeLine{00039\ \textcolor{preprocessor}{\#define\ ATTENUATOR\_MULTIPLICATOR\ \ \ \ 2.0f}}
\DoxyCodeLine{00040\ }
\DoxyCodeLine{00042\ \textcolor{preprocessor}{\#define\ ADC\_MAX\_RESOLUTION\_12B\ \ \ \ \ \ 4095.0f}}
\DoxyCodeLine{00043\ }
\DoxyCodeLine{00044\ }
\DoxyCodeLine{00045\ \textcolor{comment}{/*\ ==========================================================================}}
\DoxyCodeLine{00046\ \textcolor{comment}{\ *\ ÉNUMÉRATIONS\ APPLICATIVES}}
\DoxyCodeLine{00047\ \textcolor{comment}{\ *\ ==========================================================================\ */}}
\DoxyCodeLine{00048\ }
\DoxyCodeLine{00052\ \textcolor{keyword}{typedef}\ \textcolor{keyword}{enum}\ \{}
\DoxyCodeLine{00053\ \ \ \ \ \doxymbox{\hyperlink{driver_analog_8h_af51dcdaed089c23aa51f7be006dc69c4ac393781bf1cc6966378f70ad49d2d401}{ANALOG\_OK}}\ =\ 0,\ \ \ \ \ \ \ \ \ \ }
\DoxyCodeLine{00054\ \ \ \ \ \doxymbox{\hyperlink{driver_analog_8h_af51dcdaed089c23aa51f7be006dc69c4ad2b216ef435441a04c9c311c2d78b2e5}{ANALOG\_ERR\_PARAM}},\ \ \ \ \ \ \ }
\DoxyCodeLine{00055\ \ \ \ \ \doxymbox{\hyperlink{driver_analog_8h_af51dcdaed089c23aa51f7be006dc69c4ac38d730ab0d0d0589b85858413cc7be5}{ANALOG\_ERR\_BUSY}},\ \ \ \ \ \ \ \ }
\DoxyCodeLine{00056\ \ \ \ \ \doxymbox{\hyperlink{driver_analog_8h_af51dcdaed089c23aa51f7be006dc69c4a4a876a3a82aa5dfc59a3a34a53afbeb5}{ANALOG\_ERR\_HAL}}\ \ \ \ \ \ \ \ \ \ }
\DoxyCodeLine{00057\ \}\ \doxymbox{\hyperlink{driver_analog_8h_af51dcdaed089c23aa51f7be006dc69c4}{Analog\_Result\_t}};}
\DoxyCodeLine{00058\ }
\DoxyCodeLine{00062\ \textcolor{keyword}{typedef}\ \textcolor{keyword}{enum}\ \{}
\DoxyCodeLine{00063\ \ \ \ \ \doxymbox{\hyperlink{driver_analog_8h_a67e4ace606a4946983ae18c7f7970cbfad13798b1a3a04a689d20668d92f74206}{ANALOG\_STATUS\_READY}}\ =\ 0,}
\DoxyCodeLine{00064\ \ \ \ \ \doxymbox{\hyperlink{driver_analog_8h_a67e4ace606a4946983ae18c7f7970cbfad77efc015db0617891c3e4ca2f3e27c8}{ANALOG\_STATUS\_BUSY}},\ \ \ \ \ }
\DoxyCodeLine{00065\ \ \ \ \ \doxymbox{\hyperlink{driver_analog_8h_a67e4ace606a4946983ae18c7f7970cbfa20b1ce2712ac17b9da25f7960054e5f0}{ANALOG\_STATUS\_ERROR}}\ \ \ \ \ }
\DoxyCodeLine{00066\ \}\ \doxymbox{\hyperlink{driver_analog_8h_a67e4ace606a4946983ae18c7f7970cbf}{Analog\_Status\_t}};}
\DoxyCodeLine{00067\ }
\DoxyCodeLine{00072\ \textcolor{keyword}{typedef}\ \textcolor{keyword}{enum}\ \{}
\DoxyCodeLine{00073\ \ \ \ \ \doxymbox{\hyperlink{driver_analog_8h_a265ba346976a3893bb384d3e9f56bb78afdd294605d2bf321eca2690912324dc1}{ANALOG\_IDLE}}\ =\ 0,\ \ \ \ \ \ \ \ \ \ }
\DoxyCodeLine{00074\ \ \ \ \ \doxymbox{\hyperlink{driver_analog_8h_a265ba346976a3893bb384d3e9f56bb78a5b03926559a2e874c06cb683f09d651d}{ANALOG\_START\_CONVERSION}},\ \ }
\DoxyCodeLine{00075\ \ \ \ \ \doxymbox{\hyperlink{driver_analog_8h_a265ba346976a3893bb384d3e9f56bb78ac3bc92d03e3d0da3b6ca6c5fb7d1f50f}{ANALOG\_WAIT\_CONVERSION}},\ \ \ }
\DoxyCodeLine{00076\ \ \ \ \ \doxymbox{\hyperlink{driver_analog_8h_a265ba346976a3893bb384d3e9f56bb78a01963c6df14ab6d04f7d154bf9aa6476}{ANALOG\_PROCESS\_DATA}}\ \ \ \ \ \ \ }
\DoxyCodeLine{00077\ \}\ \doxymbox{\hyperlink{driver_analog_8h_a265ba346976a3893bb384d3e9f56bb78}{Analog\_State\_t}};}
\DoxyCodeLine{00078\ }
\DoxyCodeLine{00079\ }
\DoxyCodeLine{00080\ \textcolor{comment}{/*\ ==========================================================================}}
\DoxyCodeLine{00081\ \textcolor{comment}{\ *\ STRUCTURES\ DE\ DONNÉES}}
\DoxyCodeLine{00082\ \textcolor{comment}{\ *\ ==========================================================================\ */}}
\DoxyCodeLine{00083\ }
\DoxyCodeLine{00087\ \textcolor{keyword}{typedef}\ \textcolor{keyword}{struct\ }\{}
\DoxyCodeLine{00088\ \ \ \ \ \textcolor{comment}{/*\ -\/-\/-\/\ Couche\ Matérielle\ et\ État\ -\/-\/-\/\ */}}
\DoxyCodeLine{00089\ \ \ \ \ ADC\_HandleTypeDef\ *\doxymbox{\hyperlink{struct_analog__t_af982c0fe5d77061049c468b599100134}{hadc}};\ \ \ \ \ \ \ \ \ \ \ \ }
\DoxyCodeLine{00090\ \ \ \ \ \textcolor{keyword}{volatile}\ \doxymbox{\hyperlink{driver_analog_8h_a265ba346976a3893bb384d3e9f56bb78}{Analog\_State\_t}}\ \doxymbox{\hyperlink{struct_analog__t_a9168897c62c6ad20dad6de05ff1bfad3}{state}};\ \ \ \ \ \ }
\DoxyCodeLine{00091\ \ \ \ \ \doxymbox{\hyperlink{driver_analog_8h_a67e4ace606a4946983ae18c7f7970cbf}{Analog\_Status\_t}}\ \doxymbox{\hyperlink{struct_analog__t_adb95f0fc178870b162fde817e7eb0947}{status}};\ \ \ \ \ \ \ \ \ \ \ \ \ }
\DoxyCodeLine{00092\ }
\DoxyCodeLine{00093\ \ \ \ \ \textcolor{comment}{/*\ -\/-\/-\/\ Buffers\ de\ Données\ Brutes\ -\/-\/-\/\ */}}
\DoxyCodeLine{00094\ \ \ \ \ uint16\_t\ \doxymbox{\hyperlink{struct_analog__t_a550fc51b115c81c3c36d0714c17bad93}{ADC\_values}}[\doxymbox{\hyperlink{driver_analog_8h_a2b253ff8dc858bafc4bb77978b98b521}{NBR\_ANALOG\_SENSOR}}];\ }
\DoxyCodeLine{00095\ }
\DoxyCodeLine{00096\ \ \ \ \ \textcolor{comment}{/*\ -\/-\/-\/\ Données\ Physiques\ Calculées\ -\/-\/-\/\ */}}
\DoxyCodeLine{00097\ \ \ \ \ \textcolor{keywordtype}{float}\ \ \ \ \doxymbox{\hyperlink{struct_analog__t_a0815995cdc6e2308a51a5566fa8e5920}{VOLT\_values}}[2];\ \ \ \ \ \ \ \ \ \ \ \ }
\DoxyCodeLine{00098\ }
\DoxyCodeLine{00099\ \ \ \ \ \textcolor{comment}{/*\ -\/-\/-\/\ Monitoring\ Système\ (Calculé\ via\ macros\ HAL)\ -\/-\/-\/\ */}}
\DoxyCodeLine{00100\ \ \ \ \ uint32\_t\ \doxymbox{\hyperlink{struct_analog__t_ae3d42f7c747889611d6f585bdbdd3b91}{true\_vdda\_mv}};\ \ \ \ \ \ \ \ \ \ \ \ \ \ }
\DoxyCodeLine{00101\ \ \ \ \ int32\_t\ \ \doxymbox{\hyperlink{struct_analog__t_ad23de665f0b15ab8c4b700129ea9a88f}{internal\_temp}};\ \ \ \ \ \ \ \ \ \ \ \ \ }
\DoxyCodeLine{00102\ \ \ \ \ uint32\_t\ \doxymbox{\hyperlink{struct_analog__t_a74548ddd872461c5b23d3bce7e83e741}{v\_battery}};\ \ \ \ \ \ \ \ \ \ \ \ \ \ \ \ \ }
\DoxyCodeLine{00103\ }
\DoxyCodeLine{00104\ \ \ \ \ \textcolor{comment}{/*\ -\/-\/-\/\ Contrôle\ et\ Sécurité\ -\/-\/-\/\ */}}
\DoxyCodeLine{00105\ \ \ \ \ uint32\_t\ \doxymbox{\hyperlink{struct_analog__t_a42ff89d25c12a3302f87202d760ac1df}{start\_time}};\ \ \ \ \ \ \ \ \ \ \ \ \ \ \ \ }
\DoxyCodeLine{00106\ \ \ \ \ uint8\_t\ \ \doxymbox{\hyperlink{struct_analog__t_a45998c0b4dd5717ced32282d45d4ef9b}{error\_code}};\ \ \ \ \ \ \ \ \ \ \ \ \ \ \ \ }
\DoxyCodeLine{00107\ \ \ \ \ \textcolor{keyword}{volatile}\ \textcolor{keywordtype}{bool}\ \doxymbox{\hyperlink{struct_analog__t_a051321afacdc18291508475df3033467}{event\_adc\_complete}};\ \ \ }
\DoxyCodeLine{00108\ \}\ \doxymbox{\hyperlink{struct_analog__t}{Analog\_t}};}
\DoxyCodeLine{00109\ }
\DoxyCodeLine{00110\ }
\DoxyCodeLine{00111\ \textcolor{comment}{/*\ ==========================================================================}}
\DoxyCodeLine{00112\ \textcolor{comment}{\ *\ PROTOTYPES\ DES\ FONCTIONS\ (API\ PUBLIQUE)}}
\DoxyCodeLine{00113\ \textcolor{comment}{\ *\ ==========================================================================\ */}}
\DoxyCodeLine{00114\ }
\DoxyCodeLine{00122\ \doxymbox{\hyperlink{driver_analog_8h_af51dcdaed089c23aa51f7be006dc69c4}{Analog\_Result\_t}}\ \doxymbox{\hyperlink{driver_analog_8h_a866228196e63804439b8618f3549c297}{Analog\_Init}}(\doxymbox{\hyperlink{struct_analog__t}{Analog\_t}}\ *hanalog,\ ADC\_HandleTypeDef\ *hadc);}
\DoxyCodeLine{00123\ }
\DoxyCodeLine{00129\ \doxymbox{\hyperlink{driver_analog_8h_af51dcdaed089c23aa51f7be006dc69c4}{Analog\_Result\_t}}\ \doxymbox{\hyperlink{driver_analog_8h_afee6bed3ae606eeebb59feda2dc2208b}{Analog\_Start}}(\doxymbox{\hyperlink{struct_analog__t}{Analog\_t}}\ *hanalog);}
\DoxyCodeLine{00130\ }
\DoxyCodeLine{00136\ \textcolor{keywordtype}{void}\ \doxymbox{\hyperlink{driver_analog_8h_a9954dbb1a49b2e43a09dedc54a48d79c}{Analog\_Process}}(\doxymbox{\hyperlink{struct_analog__t}{Analog\_t}}\ *hanalog);}
\DoxyCodeLine{00137\ }
\DoxyCodeLine{00143\ \doxymbox{\hyperlink{driver_analog_8h_a67e4ace606a4946983ae18c7f7970cbf}{Analog\_Status\_t}}\ \doxymbox{\hyperlink{driver_analog_8h_a53c52728e5f98bce7ffb92ea1ac6c21e}{Analog\_GetStatus}}(\doxymbox{\hyperlink{struct_analog__t}{Analog\_t}}\ *hanalog);}
\DoxyCodeLine{00144\ }
\DoxyCodeLine{00150\ \textcolor{keywordtype}{void}\ \doxymbox{\hyperlink{driver_analog_8h_ad22fd8d893a43f1ba2c0ba4aa171efe8}{Analog\_ConvCpltCallback}}(\doxymbox{\hyperlink{struct_analog__t}{Analog\_t}}\ *hanalog);}
\DoxyCodeLine{00151\ }
\DoxyCodeLine{00152\ \textcolor{preprocessor}{\#endif\ }\textcolor{comment}{/*\ INC\_DRIVERANALOG\_H\_\ */}\textcolor{preprocessor}{}}

\end{DoxyCode}

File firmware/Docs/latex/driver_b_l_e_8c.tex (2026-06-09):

\doxysection{C:\+/\+\+Users/\+valen/\+\+Documents/\+\+BUT GEII/\+\+SAE601/\+station\+\_\+analyse\+\_\+qualite\+\_\+eau/\+firmware/\+station\+\_\+analyse\+\_\+qualite\+\_\+eau/\+\+Core/\+\+Src/\+driver\+BLE.c File Reference}
\hypertarget{driver_b_l_e_8c}{}\label{driver_b_l_e_8c}\index{C:/Users/valen/Documents/BUT GEII/SAE601/station\_analyse\_qualite\_eau/firmware/station\_analyse\_qualite\_eau/Core/Src/driverBLE.c@{C:/Users/valen/Documents/BUT GEII/SAE601/station\_analyse\_qualite\_eau/firmware/station\_analyse\_qualite\_eau/Core/Src/driverBLE.c}}
{\ttfamily \+\#include "{}driver\+BLE.\+h"{}}\newline
{\ttfamily \+\#include $<$string.\+h$>$}\newline
Include dependency graph for driver\+BLE.\+c:\+
\nopagebreak
\begin{figure}[H]
\begin{center}
\leavevmode
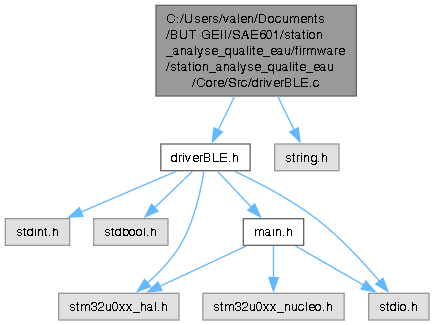
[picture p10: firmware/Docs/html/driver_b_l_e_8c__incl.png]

\end{center}
\end{figure}
\doxysubsubsection*{Data Structures}
\begin{DoxyCompactItemize}
\item 
struct \doxymbox{\hyperlink{struct_b_l_e___a_t___cmd__t}{BLE\+\_\+\+AT\+\_\+\+Cmd\+\_\+t}}
\end{DoxyCompactItemize}
\doxysubsubsection*{Macros}
\begin{DoxyCompactItemize}
\item 
\+\#define \doxymbox{\hyperlink{driver_b_l_e_8c_af50eff62b2bc8a092e0a7b313e82c772}{BLE\+\_\+\+TIMEOUT\+\_\+\+CONNEXION}}~60000
\item 
\+\#define \doxymbox{\hyperlink{driver_b_l_e_8c_a544c0bb720a0b50756d8ebc0bd4e85a6}{BLE\+\_\+\+TIMEOUT\+\_\+\+ACK}}~60000
\item 
\+\#define \doxymbox{\hyperlink{driver_b_l_e_8c_aa108bd1122268a4c426c9300919e79dd}{BLE\+\_\+\+BOOT\+\_\+\+TIME}}~500
\item 
\+\#define \doxymbox{\hyperlink{driver_b_l_e_8c_a9eb1190235d88611003a98091535a3a2}{TO\+\_\+\+CMD}}~500
\item 
\+\#define \doxymbox{\hyperlink{driver_b_l_e_8c_a98fa7cec908c1fce506c113867b3c357}{CONFIG\+\_\+\+STEPS}}~(sizeof(config\+\_\+sequence) /\+ sizeof(config\+\_\+sequence\+[0]\+))
\end{DoxyCompactItemize}
\doxysubsubsection*{Functions}
\begin{DoxyCompactItemize}
\item 
void \doxymbox{\hyperlink{driver_b_l_e_8c_adcc02e9775fb1ca89c4ff9a48fab2f15}{BLE\+\_\+\+Init}} (\doxymbox{\hyperlink{struct_b_l_e__t}{BLE\+\_\+t}} \texorpdfstring{$\ast$}{*}hble, UART\+\_\+\+Handle\+Type\+Def \texorpdfstring{$\ast$}{*}huart)
\item 
\doxymbox{\hyperlink{driver_b_l_e_8h_a37e620b324f2abc38332289578ecd436}{BLE\+\_\+\+Result\+\_\+t}} \doxymbox{\hyperlink{driver_b_l_e_8c_a3b49725295cf330ed7d6e10e5450e5c3}{BLE\+\_\+\+Configure}} (\doxymbox{\hyperlink{struct_b_l_e__t}{BLE\+\_\+t}} \texorpdfstring{$\ast$}{*}hble)
\item 
\doxymbox{\hyperlink{driver_b_l_e_8h_a37e620b324f2abc38332289578ecd436}{BLE\+\_\+\+Result\+\_\+t}} \doxymbox{\hyperlink{driver_b_l_e_8c_a8440dde80c9752cd14be912d3dba5e8a}{BLE\+\_\+\+Start}} (\doxymbox{\hyperlink{struct_b_l_e__t}{BLE\+\_\+t}} \texorpdfstring{$\ast$}{*}hble)
\item 
void \doxymbox{\hyperlink{driver_b_l_e_8c_a29d82dad342f9f8873d0c5e08445b391}{BLE\+\_\+\+Process}} (\doxymbox{\hyperlink{struct_b_l_e__t}{BLE\+\_\+t}} \texorpdfstring{$\ast$}{*}hble)
\item 
\doxymbox{\hyperlink{driver_b_l_e_8h_a0a5f739506b3b4a7433cf25653dd13d9}{BLE\+\_\+\+Status\+\_\+t}} \doxymbox{\hyperlink{driver_b_l_e_8c_a15bb69158c0890ecad21435e56606cc0}{BLE\+\_\+\+Get\+Status}} (\doxymbox{\hyperlink{struct_b_l_e__t}{BLE\+\_\+t}} \texorpdfstring{$\ast$}{*}hble)
\item 
void \doxymbox{\hyperlink{driver_b_l_e_8c_aeb8061ddfd0086a34b0c490bb3a4cbfb}{BLE\+\_\+\+Rx\+Event\+Callback}} (\doxymbox{\hyperlink{struct_b_l_e__t}{BLE\+\_\+t}} \texorpdfstring{$\ast$}{*}hble, uint16\+\_\+t Size)
\item 
void \doxymbox{\hyperlink{driver_b_l_e_8c_a66346fdb01ea454e6a556daf21ce485a}{BLE\+\_\+\+Tx\+Cplt\+Callback}} (\doxymbox{\hyperlink{struct_b_l_e__t}{BLE\+\_\+t}} \texorpdfstring{$\ast$}{*}hble)
\item 
\doxymbox{\hyperlink{driver_b_l_e_8h_a37e620b324f2abc38332289578ecd436}{BLE\+\_\+\+Result\+\_\+t}} \doxymbox{\hyperlink{driver_b_l_e_8c_a751707830902340a013a0c52f3f922a7}{BLE\+\_\+\+Send\+Chunk}} (\doxymbox{\hyperlink{struct_b_l_e__t}{BLE\+\_\+t}} \texorpdfstring{$\ast$}{*}hble, const char \texorpdfstring{$\ast$}{*}chunk)
\item 
\doxymbox{\hyperlink{driver_b_l_e_8h_a37e620b324f2abc38332289578ecd436}{BLE\+\_\+\+Result\+\_\+t}} \doxymbox{\hyperlink{driver_b_l_e_8c_a0607798e4e9620ec9f1977d494dd07bb}{BLE\+\_\+\+End\+Stream}} (\doxymbox{\hyperlink{struct_b_l_e__t}{BLE\+\_\+t}} \texorpdfstring{$\ast$}{*}hble)
\item 
void \doxymbox{\hyperlink{driver_b_l_e_8c_a437f086232132d04d711525328efbcad}{BLE\+\_\+\+Sleep}} (\doxymbox{\hyperlink{struct_b_l_e__t}{BLE\+\_\+t}} \texorpdfstring{$\ast$}{*}hble)
\item 
void \doxymbox{\hyperlink{driver_b_l_e_8c_ab64aed1aa182dd86b71698728ad3cf14}{BLE\+\_\+\+Wake\+Up}} (\doxymbox{\hyperlink{struct_b_l_e__t}{BLE\+\_\+t}} \texorpdfstring{$\ast$}{*}hble)
\end{DoxyCompactItemize}

\label{driver_b_l_e_8c_doc-define-members}
\Hypertarget{driver_b_l_e_8c_doc-define-members}
\doxysubsection{Macro Definition Documentation}
\Hypertarget{driver_b_l_e_8c_aa108bd1122268a4c426c9300919e79dd}\index{driverBLE.c@{driverBLE.c}!BLE\_BOOT\_TIME@{BLE\_BOOT\_TIME}}
\index{BLE\_BOOT\_TIME@{BLE\_BOOT\_TIME}!driverBLE.c@{driverBLE.c}}
\doxysubsubsection{\texorpdfstring{BLE\_BOOT\_TIME}{BLE\_BOOT\_TIME}}
{\footnotesize\ttfamily \label{driver_b_l_e_8c_aa108bd1122268a4c426c9300919e79dd} 
\+\#define BLE\+\_\+\+BOOT\+\_\+\+TIME~500}

\Hypertarget{driver_b_l_e_8c_a544c0bb720a0b50756d8ebc0bd4e85a6}\index{driverBLE.c@{driverBLE.c}!BLE\_TIMEOUT\_ACK@{BLE\_TIMEOUT\_ACK}}
\index{BLE\_TIMEOUT\_ACK@{BLE\_TIMEOUT\_ACK}!driverBLE.c@{driverBLE.c}}
\doxysubsubsection{\texorpdfstring{BLE\_TIMEOUT\_ACK}{BLE\_TIMEOUT\_ACK}}
{\footnotesize\ttfamily \label{driver_b_l_e_8c_a544c0bb720a0b50756d8ebc0bd4e85a6} 
\+\#define BLE\+\_\+\+TIMEOUT\+\_\+\+ACK~60000}

\Hypertarget{driver_b_l_e_8c_af50eff62b2bc8a092e0a7b313e82c772}\index{driverBLE.c@{driverBLE.c}!BLE\_TIMEOUT\_CONNEXION@{BLE\_TIMEOUT\_CONNEXION}}
\index{BLE\_TIMEOUT\_CONNEXION@{BLE\_TIMEOUT\_CONNEXION}!driverBLE.c@{driverBLE.c}}
\doxysubsubsection{\texorpdfstring{BLE\_TIMEOUT\_CONNEXION}{BLE\_TIMEOUT\_CONNEXION}}
{\footnotesize\ttfamily \label{driver_b_l_e_8c_af50eff62b2bc8a092e0a7b313e82c772} 
\+\#define BLE\+\_\+\+TIMEOUT\+\_\+\+CONNEXION~60000}

\Hypertarget{driver_b_l_e_8c_a98fa7cec908c1fce506c113867b3c357}\index{driverBLE.c@{driverBLE.c}!CONFIG\_STEPS@{CONFIG\_STEPS}}
\index{CONFIG\_STEPS@{CONFIG\_STEPS}!driverBLE.c@{driverBLE.c}}
\doxysubsubsection{\texorpdfstring{CONFIG\_STEPS}{CONFIG\_STEPS}}
{\footnotesize\ttfamily \label{driver_b_l_e_8c_a98fa7cec908c1fce506c113867b3c357} 
\+\#define CONFIG\+\_\+\+STEPS~(sizeof(config\+\_\+sequence) /\+ sizeof(config\+\_\+sequence\+[0]\+))}

\Hypertarget{driver_b_l_e_8c_a9eb1190235d88611003a98091535a3a2}\index{driverBLE.c@{driverBLE.c}!TO\_CMD@{TO\_CMD}}
\index{TO\_CMD@{TO\_CMD}!driverBLE.c@{driverBLE.c}}
\doxysubsubsection{\texorpdfstring{TO\_CMD}{TO\_CMD}}
{\footnotesize\ttfamily \label{driver_b_l_e_8c_a9eb1190235d88611003a98091535a3a2} 
\+\#define TO\+\_\+\+CMD~500}

\label{driver_b_l_e_8c_doc-func-members}
\Hypertarget{driver_b_l_e_8c_doc-func-members}
\doxysubsection{Function Documentation}
\Hypertarget{driver_b_l_e_8c_a3b49725295cf330ed7d6e10e5450e5c3}\index{driverBLE.c@{driverBLE.c}!BLE\_Configure@{BLE\_Configure}}
\index{BLE\_Configure@{BLE\_Configure}!driverBLE.c@{driverBLE.c}}
\doxysubsubsection{\texorpdfstring{BLE\_Configure()}{BLE\_Configure()}}
{\footnotesize\ttfamily \label{driver_b_l_e_8c_a3b49725295cf330ed7d6e10e5450e5c3} 
\doxymbox{\hyperlink{driver_b_l_e_8h_a37e620b324f2abc38332289578ecd436}{BLE\+\_\+\+Result\+\_\+t}} BLE\+\_\+\+Configure (\begin{DoxyParamCaption}\item[{\doxymbox{\hyperlink{struct_b_l_e__t}{BLE\+\_\+t}} \texorpdfstring{$\ast$}{*}}]{hble}{}\end{DoxyParamCaption})}

Here is the caller graph for this function:\+
\nopagebreak
\begin{figure}[H]
\begin{center}
\leavevmode

\end{center}
\end{figure}
\Hypertarget{driver_b_l_e_8c_a0607798e4e9620ec9f1977d494dd07bb}\index{driverBLE.c@{driverBLE.c}!BLE\_EndStream@{BLE\_EndStream}}
\index{BLE\_EndStream@{BLE\_EndStream}!driverBLE.c@{driverBLE.c}}
\doxysubsubsection{\texorpdfstring{BLE\_EndStream()}{BLE\_EndStream()}}
{\footnotesize\ttfamily \label{driver_b_l_e_8c_a0607798e4e9620ec9f1977d494dd07bb} 
\doxymbox{\hyperlink{driver_b_l_e_8h_a37e620b324f2abc38332289578ecd436}{BLE\+\_\+\+Result\+\_\+t}} BLE\+\_\+\+End\+Stream (\begin{DoxyParamCaption}\item[{\doxymbox{\hyperlink{struct_b_l_e__t}{BLE\+\_\+t}} \texorpdfstring{$\ast$}{*}}]{hble}{}\end{DoxyParamCaption})}

Here is the caller graph for this function:\+
\nopagebreak
\begin{figure}[H]
\begin{center}
\leavevmode

\end{center}
\end{figure}
\Hypertarget{driver_b_l_e_8c_a15bb69158c0890ecad21435e56606cc0}\index{driverBLE.c@{driverBLE.c}!BLE\_GetStatus@{BLE\_GetStatus}}
\index{BLE\_GetStatus@{BLE\_GetStatus}!driverBLE.c@{driverBLE.c}}
\doxysubsubsection{\texorpdfstring{BLE\_GetStatus()}{BLE\_GetStatus()}}
{\footnotesize\ttfamily \label{driver_b_l_e_8c_a15bb69158c0890ecad21435e56606cc0} 
\doxymbox{\hyperlink{driver_b_l_e_8h_a0a5f739506b3b4a7433cf25653dd13d9}{BLE\+\_\+\+Status\+\_\+t}} BLE\+\_\+\+Get\+Status (\begin{DoxyParamCaption}\item[{\doxymbox{\hyperlink{struct_b_l_e__t}{BLE\+\_\+t}} \texorpdfstring{$\ast$}{*}}]{hble}{}\end{DoxyParamCaption})}

Here is the caller graph for this function:\+
\nopagebreak
\begin{figure}[H]
\begin{center}
\leavevmode

\end{center}
\end{figure}
\Hypertarget{driver_b_l_e_8c_adcc02e9775fb1ca89c4ff9a48fab2f15}\index{driverBLE.c@{driverBLE.c}!BLE\_Init@{BLE\_Init}}
\index{BLE\_Init@{BLE\_Init}!driverBLE.c@{driverBLE.c}}
\doxysubsubsection{\texorpdfstring{BLE\_Init()}{BLE\_Init()}}
{\footnotesize\ttfamily \label{driver_b_l_e_8c_adcc02e9775fb1ca89c4ff9a48fab2f15} 
void BLE\+\_\+\+Init (\begin{DoxyParamCaption}\item[{\doxymbox{\hyperlink{struct_b_l_e__t}{BLE\+\_\+t}} \texorpdfstring{$\ast$}{*}}]{hble}{, }\item[{UART\+\_\+\+Handle\+Type\+Def \texorpdfstring{$\ast$}{*}}]{huart}{}\end{DoxyParamCaption})}

Here is the caller graph for this function:\+
\nopagebreak
\begin{figure}[H]
\begin{center}
\leavevmode

\end{center}
\end{figure}
\Hypertarget{driver_b_l_e_8c_a29d82dad342f9f8873d0c5e08445b391}\index{driverBLE.c@{driverBLE.c}!BLE\_Process@{BLE\_Process}}
\index{BLE\_Process@{BLE\_Process}!driverBLE.c@{driverBLE.c}}
\doxysubsubsection{\texorpdfstring{BLE\_Process()}{BLE\_Process()}}
{\footnotesize\ttfamily \label{driver_b_l_e_8c_a29d82dad342f9f8873d0c5e08445b391} 
void BLE\+\_\+\+Process (\begin{DoxyParamCaption}\item[{\doxymbox{\hyperlink{struct_b_l_e__t}{BLE\+\_\+t}} \texorpdfstring{$\ast$}{*}}]{hble}{}\end{DoxyParamCaption})}

Here is the caller graph for this function:\+
\nopagebreak
\begin{figure}[H]
\begin{center}
\leavevmode

\end{center}
\end{figure}
\Hypertarget{driver_b_l_e_8c_aeb8061ddfd0086a34b0c490bb3a4cbfb}\index{driverBLE.c@{driverBLE.c}!BLE\_RxEventCallback@{BLE\_RxEventCallback}}
\index{BLE\_RxEventCallback@{BLE\_RxEventCallback}!driverBLE.c@{driverBLE.c}}
\doxysubsubsection{\texorpdfstring{BLE\_RxEventCallback()}{BLE\_RxEventCallback()}}
{\footnotesize\ttfamily \label{driver_b_l_e_8c_aeb8061ddfd0086a34b0c490bb3a4cbfb} 
void BLE\+\_\+\+Rx\+Event\+Callback (\begin{DoxyParamCaption}\item[{\doxymbox{\hyperlink{struct_b_l_e__t}{BLE\+\_\+t}} \texorpdfstring{$\ast$}{*}}]{hble}{, }\item[{uint16\+\_\+t}]{Size}{}\end{DoxyParamCaption})}

Here is the caller graph for this function:\+
\nopagebreak
\begin{figure}[H]
\begin{center}
\leavevmode

\end{center}
\end{figure}
\Hypertarget{driver_b_l_e_8c_a751707830902340a013a0c52f3f922a7}\index{driverBLE.c@{driverBLE.c}!BLE\_SendChunk@{BLE\_SendChunk}}
\index{BLE\_SendChunk@{BLE\_SendChunk}!driverBLE.c@{driverBLE.c}}
\doxysubsubsection{\texorpdfstring{BLE\_SendChunk()}{BLE\_SendChunk()}}
{\footnotesize\ttfamily \label{driver_b_l_e_8c_a751707830902340a013a0c52f3f922a7} 
\doxymbox{\hyperlink{driver_b_l_e_8h_a37e620b324f2abc38332289578ecd436}{BLE\+\_\+\+Result\+\_\+t}} BLE\+\_\+\+Send\+Chunk (\begin{DoxyParamCaption}\item[{\doxymbox{\hyperlink{struct_b_l_e__t}{BLE\+\_\+t}} \texorpdfstring{$\ast$}{*}}]{hble}{, }\item[{const char \texorpdfstring{$\ast$}{*}}]{chunk}{}\end{DoxyParamCaption})}

Here is the caller graph for this function:\+
\nopagebreak
\begin{figure}[H]
\begin{center}
\leavevmode

\end{center}
\end{figure}
\Hypertarget{driver_b_l_e_8c_a437f086232132d04d711525328efbcad}\index{driverBLE.c@{driverBLE.c}!BLE\_Sleep@{BLE\_Sleep}}
\index{BLE\_Sleep@{BLE\_Sleep}!driverBLE.c@{driverBLE.c}}
\doxysubsubsection{\texorpdfstring{BLE\_Sleep()}{BLE\_Sleep()}}
{\footnotesize\ttfamily \label{driver_b_l_e_8c_a437f086232132d04d711525328efbcad} 
void BLE\+\_\+\+Sleep (\begin{DoxyParamCaption}\item[{\doxymbox{\hyperlink{struct_b_l_e__t}{BLE\+\_\+t}} \texorpdfstring{$\ast$}{*}}]{hble}{}\end{DoxyParamCaption})}

\Hypertarget{driver_b_l_e_8c_a8440dde80c9752cd14be912d3dba5e8a}\index{driverBLE.c@{driverBLE.c}!BLE\_Start@{BLE\_Start}}
\index{BLE\_Start@{BLE\_Start}!driverBLE.c@{driverBLE.c}}
\doxysubsubsection{\texorpdfstring{BLE\_Start()}{BLE\_Start()}}
{\footnotesize\ttfamily \label{driver_b_l_e_8c_a8440dde80c9752cd14be912d3dba5e8a} 
\doxymbox{\hyperlink{driver_b_l_e_8h_a37e620b324f2abc38332289578ecd436}{BLE\+\_\+\+Result\+\_\+t}} BLE\+\_\+\+Start (\begin{DoxyParamCaption}\item[{\doxymbox{\hyperlink{struct_b_l_e__t}{BLE\+\_\+t}} \texorpdfstring{$\ast$}{*}}]{hble}{}\end{DoxyParamCaption})}

Here is the caller graph for this function:\+
\nopagebreak
\begin{figure}[H]
\begin{center}
\leavevmode

\end{center}
\end{figure}
\Hypertarget{driver_b_l_e_8c_a66346fdb01ea454e6a556daf21ce485a}\index{driverBLE.c@{driverBLE.c}!BLE\_TxCpltCallback@{BLE\_TxCpltCallback}}
\index{BLE\_TxCpltCallback@{BLE\_TxCpltCallback}!driverBLE.c@{driverBLE.c}}
\doxysubsubsection{\texorpdfstring{BLE\_TxCpltCallback()}{BLE\_TxCpltCallback()}}
{\footnotesize\ttfamily \label{driver_b_l_e_8c_a66346fdb01ea454e6a556daf21ce485a} 
void BLE\+\_\+\+Tx\+Cplt\+Callback (\begin{DoxyParamCaption}\item[{\doxymbox{\hyperlink{struct_b_l_e__t}{BLE\+\_\+t}} \texorpdfstring{$\ast$}{*}}]{hble}{}\end{DoxyParamCaption})}

Here is the caller graph for this function:\+
\nopagebreak
\begin{figure}[H]
\begin{center}
\leavevmode

\end{center}
\end{figure}
\Hypertarget{driver_b_l_e_8c_ab64aed1aa182dd86b71698728ad3cf14}\index{driverBLE.c@{driverBLE.c}!BLE\_WakeUp@{BLE\_WakeUp}}
\index{BLE\_WakeUp@{BLE\_WakeUp}!driverBLE.c@{driverBLE.c}}
\doxysubsubsection{\texorpdfstring{BLE\_WakeUp()}{BLE\_WakeUp()}}
{\footnotesize\ttfamily \label{driver_b_l_e_8c_ab64aed1aa182dd86b71698728ad3cf14} 
void BLE\+\_\+\+Wake\+Up (\begin{DoxyParamCaption}\item[{\doxymbox{\hyperlink{struct_b_l_e__t}{BLE\+\_\+t}} \texorpdfstring{$\ast$}{*}}]{hble}{}\end{DoxyParamCaption})}

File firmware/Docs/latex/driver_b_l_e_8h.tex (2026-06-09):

\doxysection{C:\+/\+\+Users/\+valen/\+\+Documents/\+\+BUT GEII/\+\+SAE601/\+station\+\_\+analyse\+\_\+qualite\+\_\+eau/\+firmware/\+station\+\_\+analyse\+\_\+qualite\+\_\+eau/\+\+Core/\+\+Inc/\+driver\+BLE.h File Reference}
\hypertarget{driver_b_l_e_8h}{}\label{driver_b_l_e_8h}\index{C:/Users/valen/Documents/BUT GEII/SAE601/station\_analyse\_qualite\_eau/firmware/station\_analyse\_qualite\_eau/Core/Inc/driverBLE.h@{C:/Users/valen/Documents/BUT GEII/SAE601/station\_analyse\_qualite\_eau/firmware/station\_analyse\_qualite\_eau/Core/Inc/driverBLE.h}}
{\ttfamily \+\#include $<$stdint.\+h$>$}\newline
{\ttfamily \+\#include $<$stdbool.\+h$>$}\newline
{\ttfamily \+\#include "{}stm32u0xx\+\_\+hal.\+h"{}}\newline
{\ttfamily \+\#include "{}main.\+h"{}}\newline
{\ttfamily \+\#include $<$stdio.\+h$>$}\newline
Include dependency graph for driver\+BLE.\+h:\+
\nopagebreak
\begin{figure}[H]
\begin{center}
\leavevmode
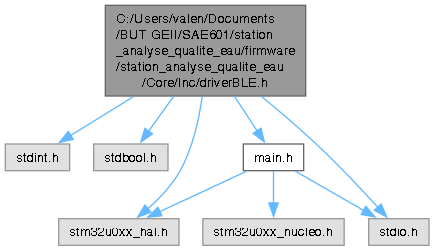
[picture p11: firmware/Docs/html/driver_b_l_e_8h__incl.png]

\end{center}
\end{figure}
This graph shows which files directly or indirectly include this file:\+
\nopagebreak
\begin{figure}[H]
\begin{center}
\leavevmode
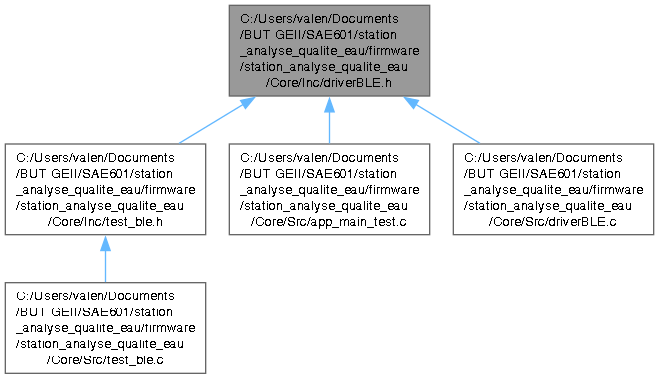
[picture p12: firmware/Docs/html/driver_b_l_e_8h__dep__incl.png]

\end{center}
\end{figure}
\doxysubsubsection*{Data Structures}
\begin{DoxyCompactItemize}
\item 
struct \doxymbox{\hyperlink{struct_b_l_e__t}{BLE\+\_\+t}}
\end{DoxyCompactItemize}
\doxysubsubsection*{Macros}
\begin{DoxyCompactItemize}
\item 
\+\#define \doxymbox{\hyperlink{driver_b_l_e_8h_a905e5dee878f046206bf5b9fa4c2feb4}{BLE\+\_\+\+DEBUG\+\_\+\+ENABLE}}~1
\item 
\+\#define \doxymbox{\hyperlink{driver_b_l_e_8h_a6abb06cd96fff88fc7007b8dc45697ae}{BLE\+\_\+\+PRINT}}(...)
\end{DoxyCompactItemize}
\doxysubsubsection*{Enumerations}
\begin{DoxyCompactItemize}
\item 
enum \doxymbox{\hyperlink{driver_b_l_e_8h_a8ae80233ab9e24ac2c6058954b3566b6}{BLE\+\_\+\+State\+\_\+t}} \{ \newline
\doxymbox{\hyperlink{driver_b_l_e_8h_a8ae80233ab9e24ac2c6058954b3566b6adbd207a6313c19a7e4bfbb92922866ba}{BLE\+\_\+\+STATE\+\_\+\+IDLE}}
, \doxymbox{\hyperlink{driver_b_l_e_8h_a8ae80233ab9e24ac2c6058954b3566b6a8fa26fa56e4c869d4658e1e9d544906b}{BLE\+\_\+\+STATE\+\_\+\+START}}
, \doxymbox{\hyperlink{driver_b_l_e_8h_a8ae80233ab9e24ac2c6058954b3566b6a833fc67add8cfb11463aa2cb2ebf0c2f}{BLE\+\_\+\+STATE\+\_\+\+CONFIGURING}}
, \doxymbox{\hyperlink{driver_b_l_e_8h_a8ae80233ab9e24ac2c6058954b3566b6a9de0e937a530b3cfb7486d08e84c5c07}{BLE\+\_\+\+STATE\+\_\+\+CONFIGURING\+\_\+\+WAIT}}
, \newline
\doxymbox{\hyperlink{driver_b_l_e_8h_a8ae80233ab9e24ac2c6058954b3566b6a4d8d871f03f3c64cf23d00c70c432cbb}{BLE\+\_\+\+STATE\+\_\+\+WAIT\+\_\+\+CMD}}
, \doxymbox{\hyperlink{driver_b_l_e_8h_a8ae80233ab9e24ac2c6058954b3566b6ab5be5eef71457e751816fca8f7de192d}{BLE\+\_\+\+STATE\+\_\+\+STREAMING}}
, \doxymbox{\hyperlink{driver_b_l_e_8h_a8ae80233ab9e24ac2c6058954b3566b6add09d50a13bcf1b43d727660b68b5399}{BLE\+\_\+\+STATE\+\_\+\+STREAMING\+\_\+\+WAIT}}
, \doxymbox{\hyperlink{driver_b_l_e_8h_a8ae80233ab9e24ac2c6058954b3566b6a80659bebfb018d3a85307c14a57ce6bc}{BLE\+\_\+\+STATE\+\_\+\+WAIT\+\_\+\+ACK}}
, \newline
\doxymbox{\hyperlink{driver_b_l_e_8h_a8ae80233ab9e24ac2c6058954b3566b6a027434e401758bef0534dcf5778e4d29}{BLE\+\_\+\+STATE\+\_\+\+STOP}}
, \doxymbox{\hyperlink{driver_b_l_e_8h_a8ae80233ab9e24ac2c6058954b3566b6a70bc9c026782ad74df51abf09aa2891b}{BLE\+\_\+\+STATE\+\_\+\+ERROR}}
 \}
\item 
enum \doxymbox{\hyperlink{driver_b_l_e_8h_a0a5f739506b3b4a7433cf25653dd13d9}{BLE\+\_\+\+Status\+\_\+t}} \{ \newline
\doxymbox{\hyperlink{driver_b_l_e_8h_a0a5f739506b3b4a7433cf25653dd13d9ae604c8c149199eef5d9d955892fa2ce7}{BLE\+\_\+\+STATUS\+\_\+\+READY}}
, \doxymbox{\hyperlink{driver_b_l_e_8h_a0a5f739506b3b4a7433cf25653dd13d9a40dc89b3a7d9731e4cbea4c73d8b8ba5}{BLE\+\_\+\+STATUS\+\_\+\+BUSY}}
, \doxymbox{\hyperlink{driver_b_l_e_8h_a0a5f739506b3b4a7433cf25653dd13d9ae1d6f218486fe99be9061587a0323f5e}{BLE\+\_\+\+STATUS\+\_\+\+ERROR}}
, \doxymbox{\hyperlink{driver_b_l_e_8h_a0a5f739506b3b4a7433cf25653dd13d9a0d9db2de80c53539b993037b7077394a}{BLE\+\_\+\+STATUS\+\_\+\+CONNECTED}}
, \newline
\doxymbox{\hyperlink{driver_b_l_e_8h_a0a5f739506b3b4a7433cf25653dd13d9abc0cf7123d07f4bf3943bf13cc1d2554}{BLE\+\_\+\+STATUS\+\_\+\+STREAMING}}
, \doxymbox{\hyperlink{driver_b_l_e_8h_a0a5f739506b3b4a7433cf25653dd13d9ad0c0389ddfcc0b8180ac771638f95611}{BLE\+\_\+\+STATUS\+\_\+\+CONFIGURING}}
 \}
\item 
enum \doxymbox{\hyperlink{driver_b_l_e_8h_a37e620b324f2abc38332289578ecd436}{BLE\+\_\+\+Result\+\_\+t}} \{ \doxymbox{\hyperlink{driver_b_l_e_8h_a37e620b324f2abc38332289578ecd436af7fe6c49d6a223452e68e5a49d82d2e7}{BLE\+\_\+\+OK}}
, \doxymbox{\hyperlink{driver_b_l_e_8h_a37e620b324f2abc38332289578ecd436abd700217effbeed3a10c5ef91f849361}{BLE\+\_\+\+ERR\+\_\+\+PARAM}}
, \doxymbox{\hyperlink{driver_b_l_e_8h_a37e620b324f2abc38332289578ecd436aaa0c52ac5b1905e8035c78aeed3d1db4}{BLE\+\_\+\+ERR\+\_\+\+HW}}
, \doxymbox{\hyperlink{driver_b_l_e_8h_a37e620b324f2abc38332289578ecd436a31fdb76b15acd9f647cceef1c33934c2}{BLE\+\_\+\+BUSY}}
 \}
\end{DoxyCompactItemize}
\doxysubsubsection*{Functions}
\begin{DoxyCompactItemize}
\item 
void \doxymbox{\hyperlink{driver_b_l_e_8h_adcc02e9775fb1ca89c4ff9a48fab2f15}{BLE\+\_\+\+Init}} (\doxymbox{\hyperlink{struct_b_l_e__t}{BLE\+\_\+t}} \texorpdfstring{$\ast$}{*}hble, UART\+\_\+\+Handle\+Type\+Def \texorpdfstring{$\ast$}{*}huart)
\item 
\doxymbox{\hyperlink{driver_b_l_e_8h_a37e620b324f2abc38332289578ecd436}{BLE\+\_\+\+Result\+\_\+t}} \doxymbox{\hyperlink{driver_b_l_e_8h_a3b49725295cf330ed7d6e10e5450e5c3}{BLE\+\_\+\+Configure}} (\doxymbox{\hyperlink{struct_b_l_e__t}{BLE\+\_\+t}} \texorpdfstring{$\ast$}{*}hble)
\item 
\doxymbox{\hyperlink{driver_b_l_e_8h_a37e620b324f2abc38332289578ecd436}{BLE\+\_\+\+Result\+\_\+t}} \doxymbox{\hyperlink{driver_b_l_e_8h_a8440dde80c9752cd14be912d3dba5e8a}{BLE\+\_\+\+Start}} (\doxymbox{\hyperlink{struct_b_l_e__t}{BLE\+\_\+t}} \texorpdfstring{$\ast$}{*}hble)
\item 
void \doxymbox{\hyperlink{driver_b_l_e_8h_a29d82dad342f9f8873d0c5e08445b391}{BLE\+\_\+\+Process}} (\doxymbox{\hyperlink{struct_b_l_e__t}{BLE\+\_\+t}} \texorpdfstring{$\ast$}{*}hble)
\item 
void \doxymbox{\hyperlink{driver_b_l_e_8h_a620ed719c4beb69463563378b72b9c3f}{BLE\+\_\+\+Rx\+Callback}} (\doxymbox{\hyperlink{struct_b_l_e__t}{BLE\+\_\+t}} \texorpdfstring{$\ast$}{*}hble)
\item 
\doxymbox{\hyperlink{driver_b_l_e_8h_a37e620b324f2abc38332289578ecd436}{BLE\+\_\+\+Result\+\_\+t}} \doxymbox{\hyperlink{driver_b_l_e_8h_a751707830902340a013a0c52f3f922a7}{BLE\+\_\+\+Send\+Chunk}} (\doxymbox{\hyperlink{struct_b_l_e__t}{BLE\+\_\+t}} \texorpdfstring{$\ast$}{*}hble, const char \texorpdfstring{$\ast$}{*}chunk)
\item 
\doxymbox{\hyperlink{driver_b_l_e_8h_a37e620b324f2abc38332289578ecd436}{BLE\+\_\+\+Result\+\_\+t}} \doxymbox{\hyperlink{driver_b_l_e_8h_a0607798e4e9620ec9f1977d494dd07bb}{BLE\+\_\+\+End\+Stream}} (\doxymbox{\hyperlink{struct_b_l_e__t}{BLE\+\_\+t}} \texorpdfstring{$\ast$}{*}hble)
\item 
\doxymbox{\hyperlink{driver_b_l_e_8h_a0a5f739506b3b4a7433cf25653dd13d9}{BLE\+\_\+\+Status\+\_\+t}} \doxymbox{\hyperlink{driver_b_l_e_8h_a15bb69158c0890ecad21435e56606cc0}{BLE\+\_\+\+Get\+Status}} (\doxymbox{\hyperlink{struct_b_l_e__t}{BLE\+\_\+t}} \texorpdfstring{$\ast$}{*}hble)
\item 
void \doxymbox{\hyperlink{driver_b_l_e_8h_a437f086232132d04d711525328efbcad}{BLE\+\_\+\+Sleep}} (\doxymbox{\hyperlink{struct_b_l_e__t}{BLE\+\_\+t}} \texorpdfstring{$\ast$}{*}hble)
\item 
void \doxymbox{\hyperlink{driver_b_l_e_8h_ab64aed1aa182dd86b71698728ad3cf14}{BLE\+\_\+\+Wake\+Up}} (\doxymbox{\hyperlink{struct_b_l_e__t}{BLE\+\_\+t}} \texorpdfstring{$\ast$}{*}hble)
\item 
void \doxymbox{\hyperlink{driver_b_l_e_8h_aeb8061ddfd0086a34b0c490bb3a4cbfb}{BLE\+\_\+\+Rx\+Event\+Callback}} (\doxymbox{\hyperlink{struct_b_l_e__t}{BLE\+\_\+t}} \texorpdfstring{$\ast$}{*}hble, uint16\+\_\+t Size)
\item 
void \doxymbox{\hyperlink{driver_b_l_e_8h_a66346fdb01ea454e6a556daf21ce485a}{BLE\+\_\+\+Tx\+Cplt\+Callback}} (\doxymbox{\hyperlink{struct_b_l_e__t}{BLE\+\_\+t}} \texorpdfstring{$\ast$}{*}hble)
\end{DoxyCompactItemize}

\label{driver_b_l_e_8h_doc-define-members}
\Hypertarget{driver_b_l_e_8h_doc-define-members}
\doxysubsection{Macro Definition Documentation}
\Hypertarget{driver_b_l_e_8h_a905e5dee878f046206bf5b9fa4c2feb4}\index{driverBLE.h@{driverBLE.h}!BLE\_DEBUG\_ENABLE@{BLE\_DEBUG\_ENABLE}}
\index{BLE\_DEBUG\_ENABLE@{BLE\_DEBUG\_ENABLE}!driverBLE.h@{driverBLE.h}}
\doxysubsubsection{\texorpdfstring{BLE\_DEBUG\_ENABLE}{BLE\_DEBUG\_ENABLE}}
{\footnotesize\ttfamily \label{driver_b_l_e_8h_a905e5dee878f046206bf5b9fa4c2feb4} 
\+\#define BLE\+\_\+\+DEBUG\+\_\+\+ENABLE~1}

\Hypertarget{driver_b_l_e_8h_a6abb06cd96fff88fc7007b8dc45697ae}\index{driverBLE.h@{driverBLE.h}!BLE\_PRINT@{BLE\_PRINT}}
\index{BLE\_PRINT@{BLE\_PRINT}!driverBLE.h@{driverBLE.h}}
\doxysubsubsection{\texorpdfstring{BLE\_PRINT}{BLE\_PRINT}}
{\footnotesize\ttfamily \label{driver_b_l_e_8h_a6abb06cd96fff88fc7007b8dc45697ae} 
\+\#define BLE\+\_\+\+PRINT(\begin{DoxyParamCaption}\item[{}]{}...{}\end{DoxyParamCaption})}

{\bfseries Value:\+}
\begin{DoxyCode}{0}
\DoxyCodeLine{printf(\textcolor{stringliteral}{"{}[BLE]\ "{}}\ \_\_VA\_ARGS\_\_)}

\end{DoxyCode}

\label{driver_b_l_e_8h_doc-enum-members}
\Hypertarget{driver_b_l_e_8h_doc-enum-members}
\doxysubsection{Enumeration Type Documentation}
\Hypertarget{driver_b_l_e_8h_a37e620b324f2abc38332289578ecd436}\index{driverBLE.h@{driverBLE.h}!BLE\_Result\_t@{BLE\_Result\_t}}
\index{BLE\_Result\_t@{BLE\_Result\_t}!driverBLE.h@{driverBLE.h}}
\doxysubsubsection{\texorpdfstring{BLE\_Result\_t}{BLE\_Result\_t}}
{\footnotesize\ttfamily \label{driver_b_l_e_8h_a37e620b324f2abc38332289578ecd436} 
enum \doxymbox{\hyperlink{driver_b_l_e_8h_a37e620b324f2abc38332289578ecd436}{BLE\+\_\+\+Result\+\_\+t}}}

\begin{DoxyEnumFields}[2]{Enumerator}
\raisebox{\heightof{T}}[0pt][0pt]{\index{BLE\_OK@{BLE\_OK}!driverBLE.h@{driverBLE.h}}
\index{driverBLE.h@{driverBLE.h}!BLE\_OK@{BLE\_OK}}
}\Hypertarget{driver_b_l_e_8h_a37e620b324f2abc38332289578ecd436af7fe6c49d6a223452e68e5a49d82d2e7}\label{driver_b_l_e_8h_a37e620b324f2abc38332289578ecd436af7fe6c49d6a223452e68e5a49d82d2e7} 
BLE\+\_\+\+OK&\\
\hline

\raisebox{\heightof{T}}[0pt][0pt]{\index{BLE\_ERR\_PARAM@{BLE\_ERR\_PARAM}!driverBLE.h@{driverBLE.h}}
\index{driverBLE.h@{driverBLE.h}!BLE\_ERR\_PARAM@{BLE\_ERR\_PARAM}}
}\Hypertarget{driver_b_l_e_8h_a37e620b324f2abc38332289578ecd436abd700217effbeed3a10c5ef91f849361}\label{driver_b_l_e_8h_a37e620b324f2abc38332289578ecd436abd700217effbeed3a10c5ef91f849361} 
BLE\+\_\+\+ERR\+\_\+\+PARAM&\\
\hline

\raisebox{\heightof{T}}[0pt][0pt]{\index{BLE\_ERR\_HW@{BLE\_ERR\_HW}!driverBLE.h@{driverBLE.h}}
\index{driverBLE.h@{driverBLE.h}!BLE\_ERR\_HW@{BLE\_ERR\_HW}}
}\Hypertarget{driver_b_l_e_8h_a37e620b324f2abc38332289578ecd436aaa0c52ac5b1905e8035c78aeed3d1db4}\label{driver_b_l_e_8h_a37e620b324f2abc38332289578ecd436aaa0c52ac5b1905e8035c78aeed3d1db4} 
BLE\+\_\+\+ERR\+\_\+\+HW&\\
\hline
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

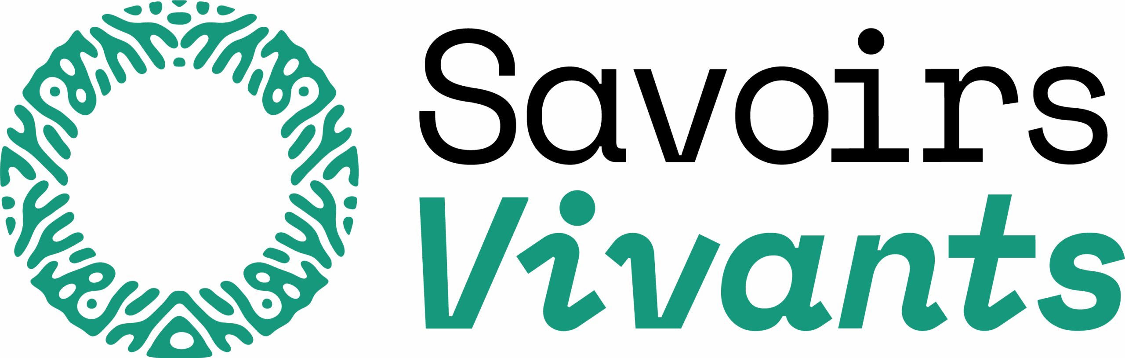
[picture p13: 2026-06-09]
firmware/Docs/latex/cropped-cropped-Savoirsvivants-scaled-1.png

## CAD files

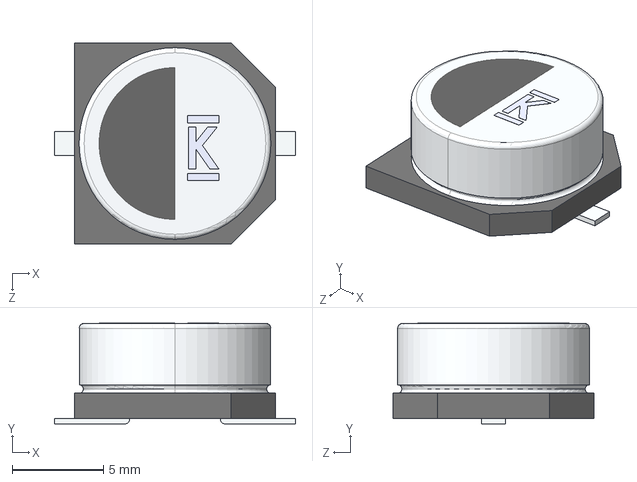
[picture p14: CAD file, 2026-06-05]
hardware/3D_Models/FC0H104ZFTBR24.stp
13.2 x 5.50 x 11.0 mm

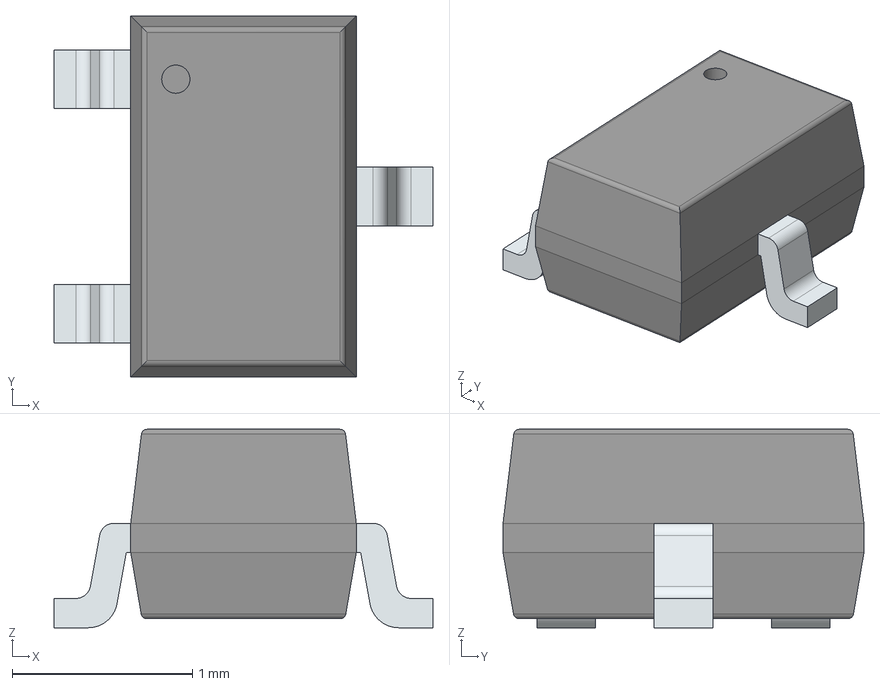
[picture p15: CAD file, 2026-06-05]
hardware/3D_Models/BAV199W-7.stp
2.10 x 2.00 x 1.10 mm
PinsArrayL
FilletPinR

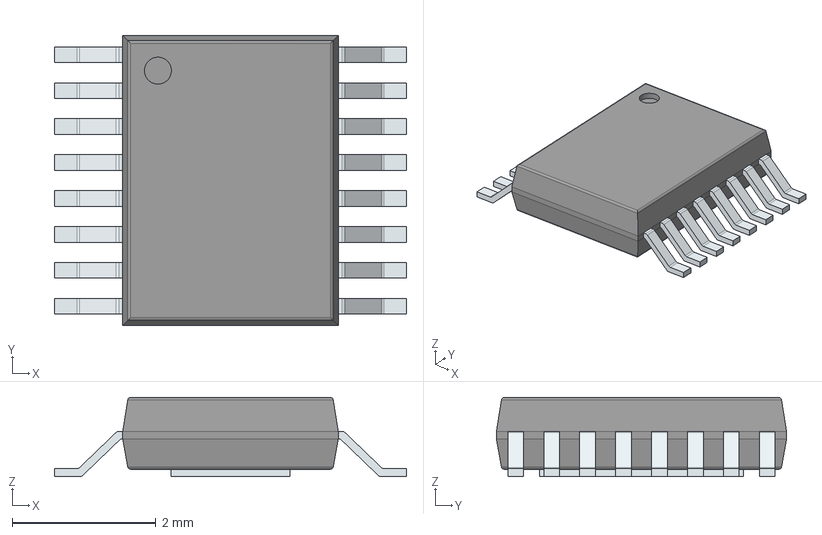
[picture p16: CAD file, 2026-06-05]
hardware/3D_Models/LTC3129IMSE-1#PBF.stp
4.90 x 4.04 x 1.10 mm
PinsArrayLR
ThermalPad

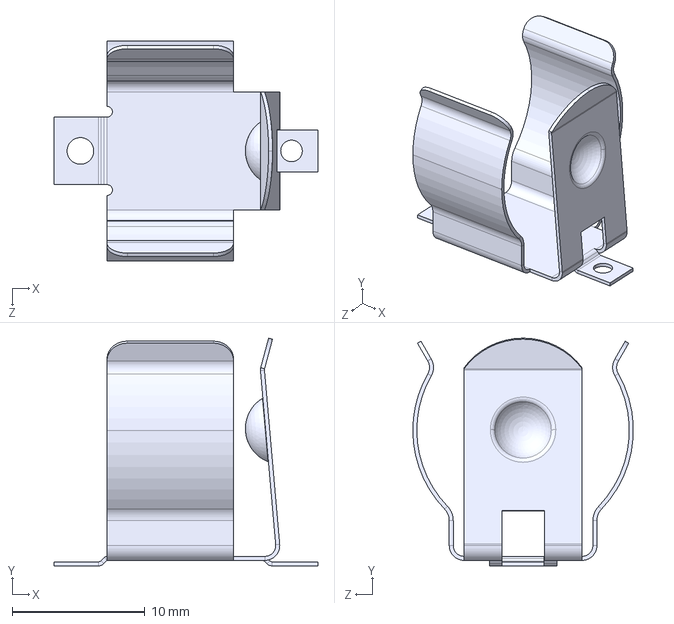
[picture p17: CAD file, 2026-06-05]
hardware/3D_Models/254.step
19.9 x 17.2 x 16.6 mm

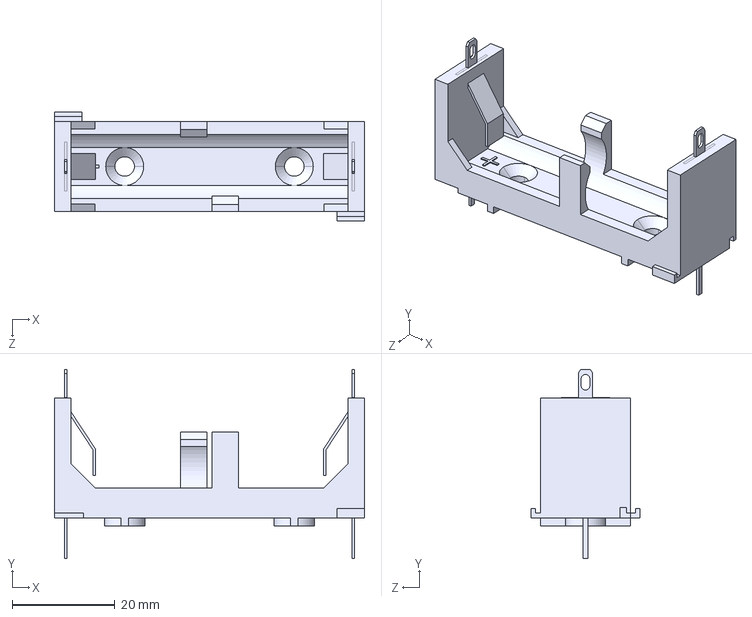
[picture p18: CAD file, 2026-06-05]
hardware/3D_Models/BX0035.stp
60.3 x 36.8 x 21.3 mm

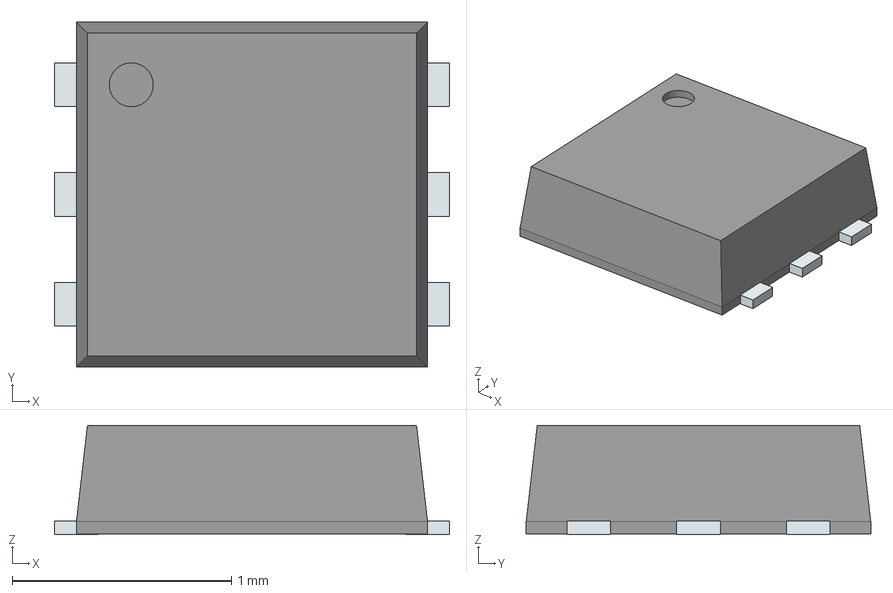
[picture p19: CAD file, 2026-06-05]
hardware/3D_Models/S-82B1AAB-I6T1U.stp
1.80 x 1.57 x 0.498 mm
PinsArrayL
PinsArrayR

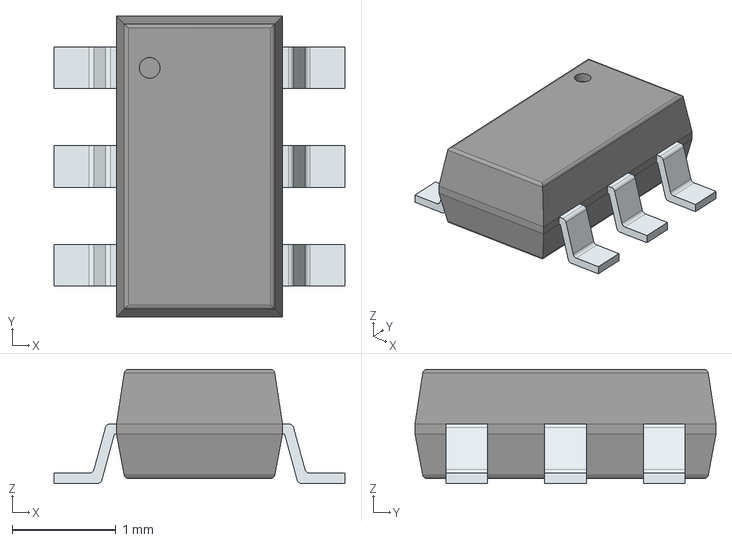
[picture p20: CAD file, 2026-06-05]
hardware/3D_Models/FDC6561AN.stp
2.80 x 2.90 x 1.10 mm
PinsArrayLR

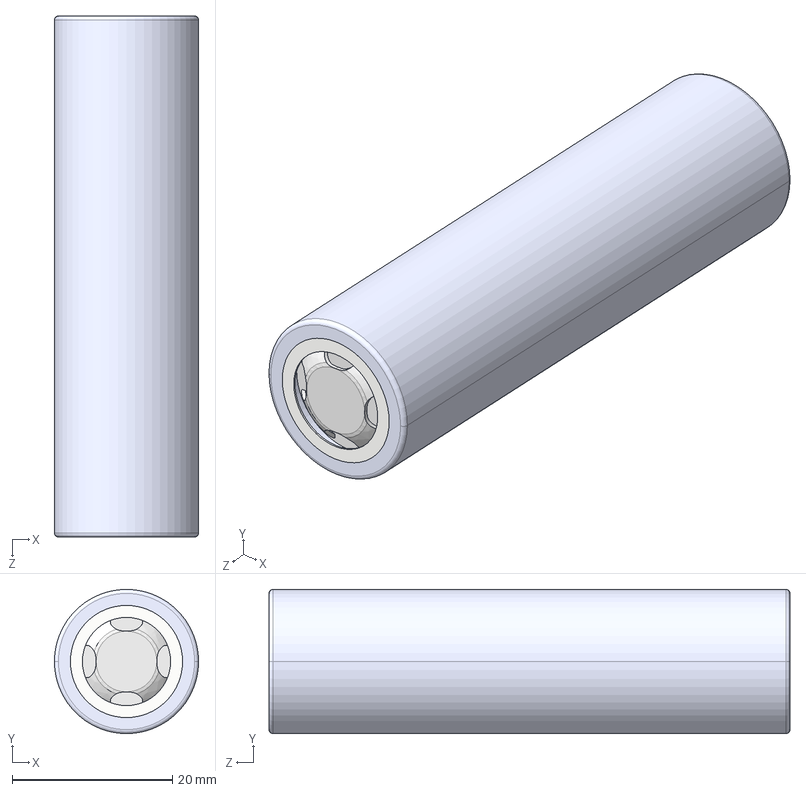
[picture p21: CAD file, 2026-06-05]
hardware/3D_Models/Cell 18650.STEP
18.0 x 18.0 x 65.0 mm
battery 186501^battery 18650(2)_battery 18650
battery 186502^battery 18650(2)_battery 18650
battery 186503^battery 18650(2)_battery 18650
battery 186504^battery 18650(2)_battery 18650

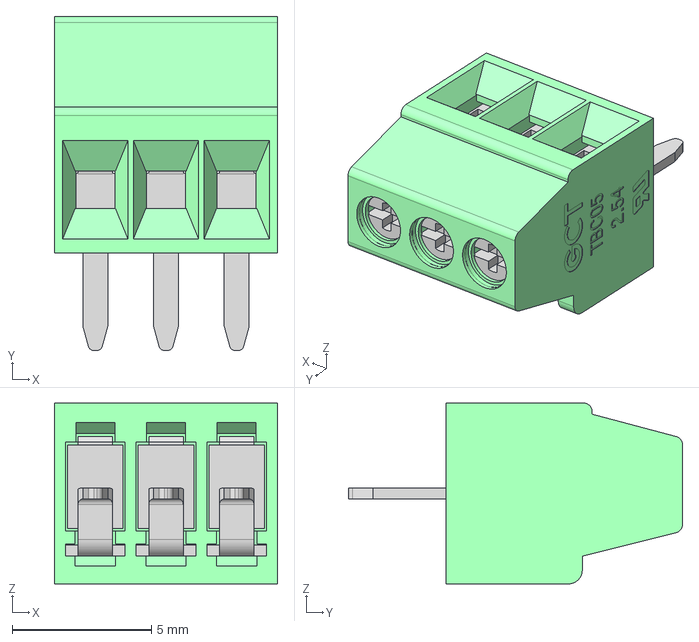
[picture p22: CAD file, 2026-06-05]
hardware/3D_Models/TBC05-03-1-G-G.stp
8.02 x 12.0 x 6.50 mm
TBC05-03-1-G-G_H
TBC05-03-1-G-G_P x 3

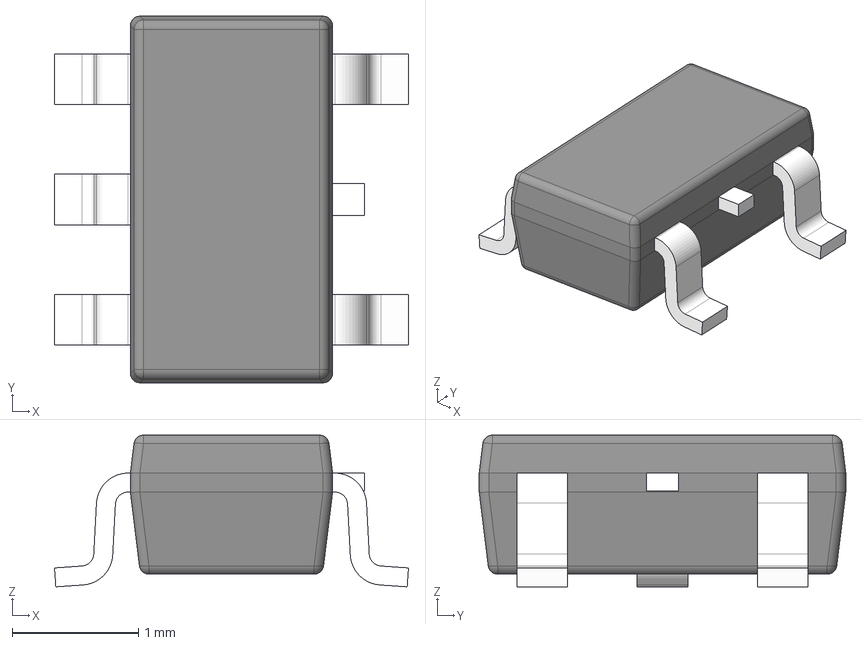
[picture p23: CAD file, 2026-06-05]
hardware/3D_Models/TPS7A0215PDBVR.stp
2.80 x 2.90 x 1.20 mm
BODY-SOT
LEAD-SOT x 5
LEAD-DUMMY

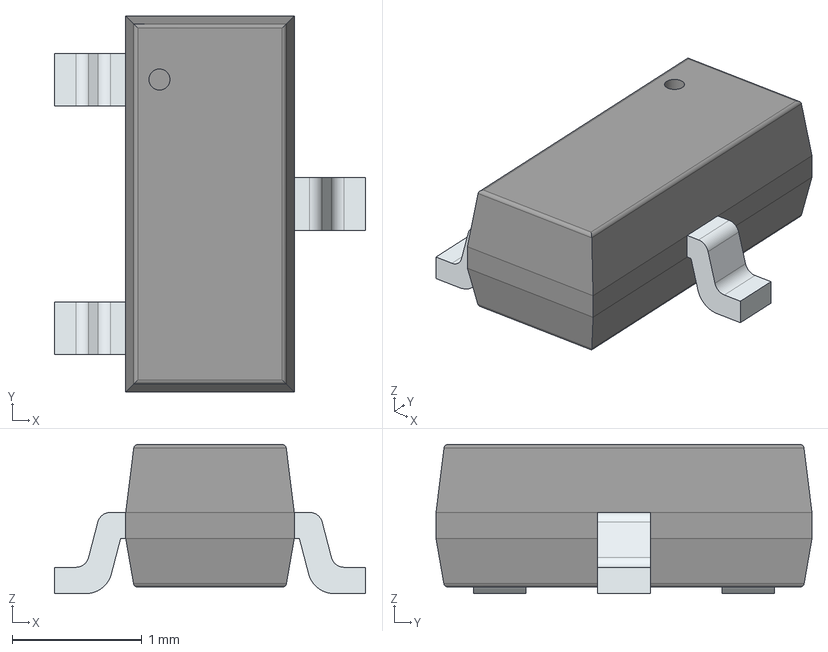
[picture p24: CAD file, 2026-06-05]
hardware/3D_Models/DMG2305UX-7.stp
2.40 x 2.90 x 1.15 mm
PinsArrayL
FilletPinR

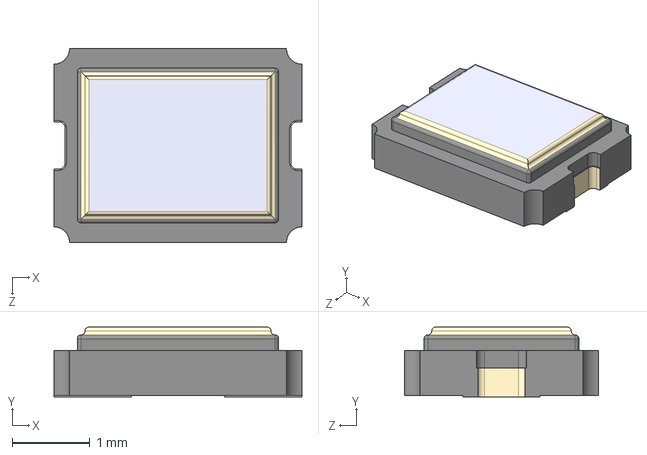
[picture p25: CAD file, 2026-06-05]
hardware/3D_Models/CPH3225A.stp
3.20 x 0.9 x 2.50 mm

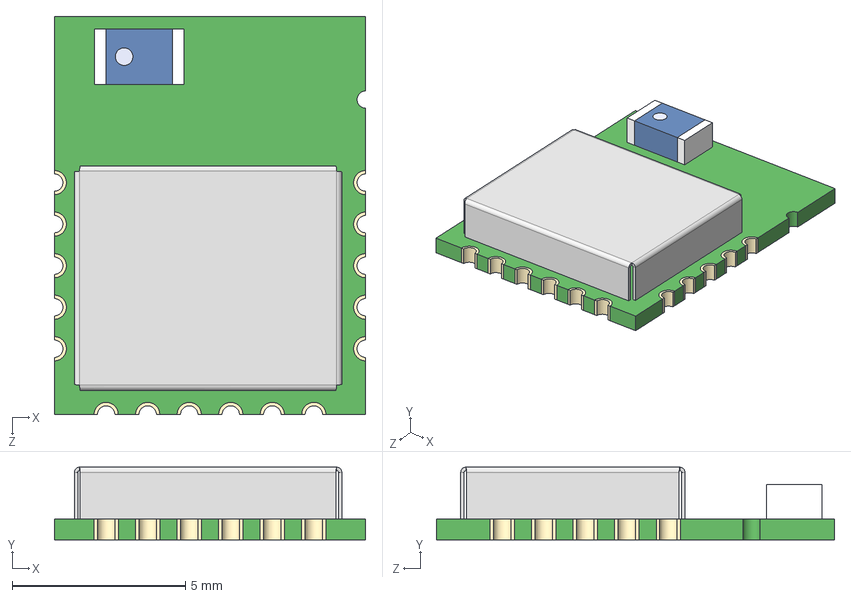
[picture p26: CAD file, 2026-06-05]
hardware/3D_Models/RN4871-V_RM118.STEP
9.00 x 2.10 x 11.5 mm

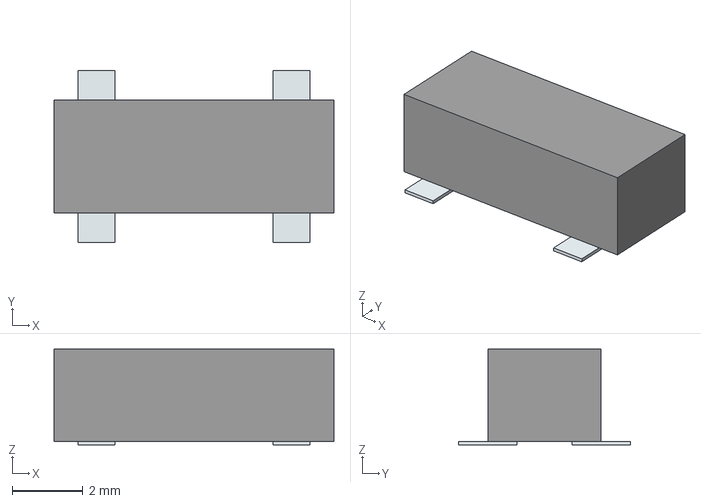
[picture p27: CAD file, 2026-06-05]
hardware/3D_Models/G43270018.stp
7.90 x 4.84 x 2.70 mm
Pins

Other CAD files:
hardware/3D_Models/744031004.stp

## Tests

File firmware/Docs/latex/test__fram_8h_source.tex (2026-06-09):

\doxysection{test\+\_\+fram.\+h}
\hypertarget{test__fram_8h_source}{}\label{test__fram_8h_source}\index{C:/Users/valen/Documents/BUT GEII/SAE601/station\_analyse\_qualite\_eau/firmware/station\_analyse\_qualite\_eau/Core/Inc/test\_fram.h@{C:/Users/valen/Documents/BUT GEII/SAE601/station\_analyse\_qualite\_eau/firmware/station\_analyse\_qualite\_eau/Core/Inc/test\_fram.h}}
\doxymbox{\hyperlink{test__fram_8h}{Go to the documentation of this file.}}
\begin{DoxyCode}{0}
\DoxyCodeLine{00001\ \textcolor{comment}{/*}}
\DoxyCodeLine{00002\ \textcolor{comment}{\ *\ test\_fram.h}}
\DoxyCodeLine{00003\ \textcolor{comment}{\ *\ Batterie\ de\ tests\ pour\ le\ driver\ FRAM\ SPI/DMA}}
\DoxyCodeLine{00004\ \textcolor{comment}{\ */}}
\DoxyCodeLine{00005\ }
\DoxyCodeLine{00006\ \textcolor{preprocessor}{\#ifndef\ INC\_TEST\_FRAM\_H\_}}
\DoxyCodeLine{00007\ \textcolor{preprocessor}{\#define\ INC\_TEST\_FRAM\_H\_}}
\DoxyCodeLine{00008\ }
\DoxyCodeLine{00009\ \textcolor{preprocessor}{\#include\ <stdbool.h>}}
\DoxyCodeLine{00010\ \textcolor{preprocessor}{\#include\ "{}\doxymbox{\hyperlink{driver_f_r_a_m_8h}{driverFRAM.h}}"{}}}
\DoxyCodeLine{00011\ }
\DoxyCodeLine{00017\ \textcolor{keywordtype}{bool}\ \doxymbox{\hyperlink{test__fram_8h_ae5fb778889b60b9f94b1ec5c71727c81}{TestFRAM\_RunAll}}(\doxymbox{\hyperlink{struct_f_r_a_m__t}{FRAM\_t}}\ *hfram);}
\DoxyCodeLine{00018\ }
\DoxyCodeLine{00019\ \textcolor{preprocessor}{\#endif\ }\textcolor{comment}{/*\ INC\_TEST\_FRAM\_H\_\ */}\textcolor{preprocessor}{}}

\end{DoxyCode}

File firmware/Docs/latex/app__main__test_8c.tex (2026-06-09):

\doxysection{C:\+/\+\+Users/\+valen/\+\+Documents/\+\+BUT GEII/\+\+SAE601/\+station\+\_\+analyse\+\_\+qualite\+\_\+eau/\+firmware/\+station\+\_\+analyse\+\_\+qualite\+\_\+eau/\+\+Core/\+\+Src/\+app\+\_\+main\+\_\+test.c File Reference}
\hypertarget{app__main__test_8c}{}\label{app__main__test_8c}\index{C:/Users/valen/Documents/BUT GEII/SAE601/station\_analyse\_qualite\_eau/firmware/station\_analyse\_qualite\_eau/Core/Src/app\_main\_test.c@{C:/Users/valen/Documents/BUT GEII/SAE601/station\_analyse\_qualite\_eau/firmware/station\_analyse\_qualite\_eau/Core/Src/app\_main\_test.c}}
{\ttfamily \+\#include $<$stdio.\+h$>$}\newline
{\ttfamily \+\#include $<$string.\+h$>$}\newline
{\ttfamily \+\#include $<$time.\+h$>$}\newline
{\ttfamily \+\#include "{}app\+\_\+main\+\_\+test.\+h"{}}\newline
{\ttfamily \+\#include "{}usart.\+h"{}}\newline
{\ttfamily \+\#include "{}main.\+h"{}}\newline
{\ttfamily \+\#include "{}rtc.\+h"{}}\newline
{\ttfamily \+\#include "{}adc.\+h"{}}\newline
{\ttfamily \+\#include "{}spi.\+h"{}}\newline
{\ttfamily \+\#include "{}lptim.\+h"{}}\newline
{\ttfamily \+\#include "{}dma.\+h"{}}\newline
{\ttfamily \+\#include "{}driver\+DS18\+B20.\+h"{}}\newline
{\ttfamily \+\#include "{}driver\+LPPCayenne.\+h"{}}\newline
{\ttfamily \+\#include "{}driver\+Analog.\+h"{}}\newline
{\ttfamily \+\#include "{}driver\+BLE.\+h"{}}\newline
{\ttfamily \+\#include "{}driver\+FRAM.\+h"{}}\newline
{\ttfamily \+\#include "{}driver\+Data\+Log.\+h"{}}\newline
{\ttfamily \+\#include "{}driver\+Lo\+Ra\+WAN.\+h"{}}\newline
{\ttfamily \+\#include "{}driver\+RTC.\+h"{}}\newline
Include dependency graph for app\+\_\+main\+\_\+test.\+c:\+
\nopagebreak
\begin{figure}[H]
\begin{center}
\leavevmode
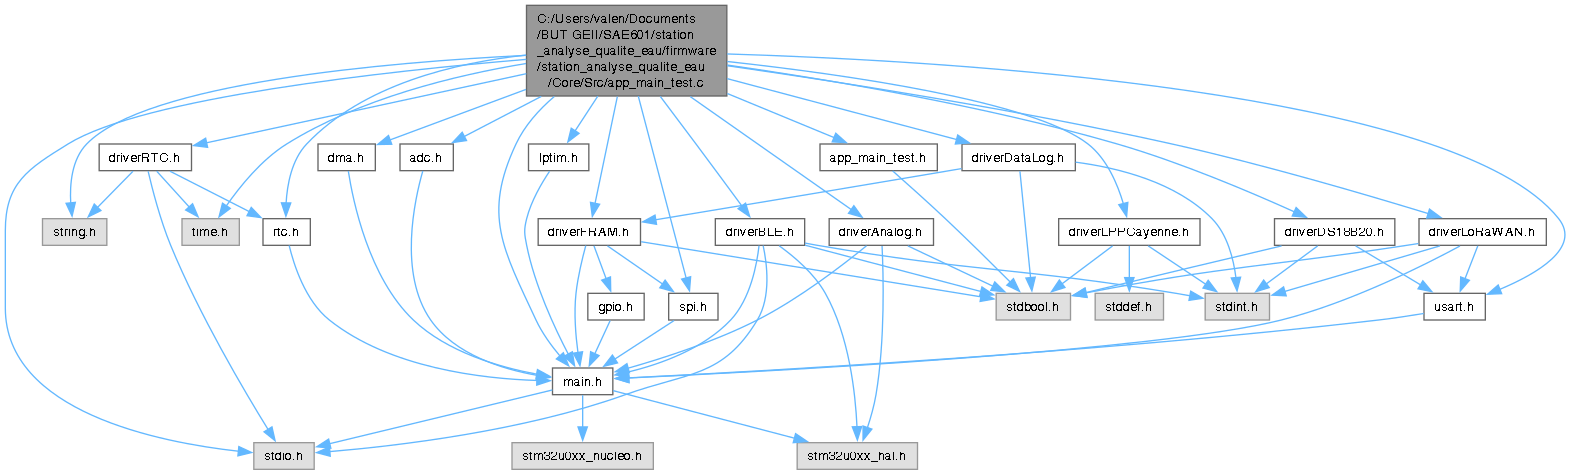
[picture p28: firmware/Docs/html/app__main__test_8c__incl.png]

\end{center}
\end{figure}
\doxysubsubsection*{Macros}
\begin{DoxyCompactItemize}
\item 
\+\#define \doxymbox{\hyperlink{app__main__test_8c_a251f3809a0715a52895f901847b28ec3}{ENABLE\+\_\+\+DATALOG\+\_\+\+TESTS}}~0
\item 
\+\#define \doxymbox{\hyperlink{app__main__test_8c_adff80ac59d9346ed44f00c4b927e6fd0}{ENABLE\+\_\+\+LORAWAN\+\_\+\+TESTS}}~0
\item 
\+\#define \doxymbox{\hyperlink{app__main__test_8c_a6e84fd3ddadd283f5c329e977964ca8d}{ENABLE\+\_\+\+DS18\+B20\+\_\+\+TESTS}}~0
\item 
\+\#define \doxymbox{\hyperlink{app__main__test_8c_a6982a0459ab84fb3f9c6b6b5f27cbd9a}{ENABLE\+\_\+\+FRAM\+\_\+\+TESTS}}~0
\item 
\+\#define \doxymbox{\hyperlink{app__main__test_8c_a8c51fec63a4ab2daa27315bf9597aed7}{ENABLE\+\_\+\+ANALOG\+\_\+\+TESTS}}~0
\item 
\+\#define \doxymbox{\hyperlink{app__main__test_8c_a36e156bd8846a33cfb53d1cf3f3cc038}{ENABLE\+\_\+\+LPP\+\_\+\+TESTS}}~0
\item 
\+\#define \doxymbox{\hyperlink{app__main__test_8c_a4e459df6ec0ce374717a51518bfa4336}{ENABLE\+\_\+\+BLE\+\_\+\+TESTS}}~0
\item 
\+\#define \doxymbox{\hyperlink{app__main__test_8c_af793d3343d4edebf2faac919e5756901}{BLE\+\_\+\+PARSING\+\_\+\+TIMER}}~25
\end{DoxyCompactItemize}
\doxysubsubsection*{Enumerations}
\begin{DoxyCompactItemize}
\item 
enum \doxymbox{\hyperlink{app__main__test_8c_a51eb73cd19803fc310a1817bedc66722}{Main\+App\+\_\+\+State\+\_\+t}} \{ \newline
\doxymbox{\hyperlink{app__main__test_8c_a51eb73cd19803fc310a1817bedc66722a7bed2cbf33a9fd2c8dab28b984509b2d}{APP\+\_\+\+STATE\+\_\+\+INIT\+\_\+\+LORA}}
, \doxymbox{\hyperlink{app__main__test_8c_a51eb73cd19803fc310a1817bedc66722afce2db10ab1359fbaa7aed9839b9b7d3}{APP\+\_\+\+STATE\+\_\+\+WAIT\+\_\+\+MEASURE}}
, \doxymbox{\hyperlink{app__main__test_8c_a51eb73cd19803fc310a1817bedc66722a8bab74073fca34c806e9c63cf2b4fa5c}{APP\+\_\+\+STATE\+\_\+\+SAVE\+\_\+\+RECORD}}
, \doxymbox{\hyperlink{app__main__test_8c_a51eb73cd19803fc310a1817bedc66722a5b645e7af891597e657cd22766f91b3c}{APP\+\_\+\+STATE\+\_\+\+WAIT\+\_\+\+SAVE}}
, \newline
\doxymbox{\hyperlink{app__main__test_8c_a51eb73cd19803fc310a1817bedc66722abf64b3f50e4bd0c831783127693508ed}{APP\+\_\+\+STATE\+\_\+\+SEND\+\_\+\+LORA}}
, \doxymbox{\hyperlink{app__main__test_8c_a51eb73cd19803fc310a1817bedc66722af653c7450b549886625e73447f12f1f0}{APP\+\_\+\+STATE\+\_\+\+WAIT\+\_\+\+TX}}
, \doxymbox{\hyperlink{app__main__test_8c_a51eb73cd19803fc310a1817bedc66722a70a990acc81602a40e8babdb5d606b06}{APP\+\_\+\+STATE\+\_\+\+WAIT\+\_\+\+LORA\+\_\+\+SLEEP}}
, \doxymbox{\hyperlink{app__main__test_8c_a51eb73cd19803fc310a1817bedc66722af8aeb5a9c3fdd9dfc888f09d7df9fe8d}{APP\+\_\+\+STATE\+\_\+\+SLEEP}}
, \newline
\doxymbox{\hyperlink{app__main__test_8c_a51eb73cd19803fc310a1817bedc66722a1ba3f22c125d192f1880c4706902e94f}{APP\+\_\+\+STATE\+\_\+\+BLE\+\_\+\+ACTIVE}}
 \}
\end{DoxyCompactItemize}
\doxysubsubsection*{Functions}
\begin{DoxyCompactItemize}
\item 
void \doxymbox{\hyperlink{app__main__test_8c_a70af21c671abfcc773614a9a4f63d920}{System\+Clock\+\_\+\+Config}} (void)
\begin{DoxyCompactList}\small\item\em System Clock Configuration. \end{DoxyCompactList}\item 
struct \doxymbox{\hyperlink{app__main__test_8c_ab898071398b359603a35c202e9c65f3b}{\+\_\+\+\_\+attribute\+\_\+\+\_\+}} ((packed))
\item 
void \doxymbox{\hyperlink{app__main__test_8c_a4ee62d16935757fc638ff8b1b0c31188}{start\+Measures}} (void)
\item 
void \doxymbox{\hyperlink{app__main__test_8c_a7dfd9b79bc5a37d7df40207afbc5431f}{setup}} (void)
\item 
void \doxymbox{\hyperlink{app__main__test_8c_a0b33edabd7f1c4e4a0bf32c67269be2f}{loop}} (void)
\item 
void \doxymbox{\hyperlink{app__main__test_8c_a0b334860563f4a109443e0a604af2300}{HAL\+\_\+\+GPIO\+\_\+\+EXTI\+\_\+\+Falling\+\_\+\+Callback}} (uint16\+\_\+t GPIO\+\_\+\+Pin)
\item 
void \doxymbox{\hyperlink{app__main__test_8c_ac1dd7334499ef88df8187a45c0d28ee8}{HAL\+\_\+\+LPTIM\+\_\+\+Auto\+Reload\+Match\+Callback}} (LPTIM\+\_\+\+Handle\+Type\+Def \texorpdfstring{$\ast$}{*}hlptim)
\item 
void \doxymbox{\hyperlink{app__main__test_8c_af20a88180db1113be1e89266917d148b}{HAL\+\_\+\+ADC\+\_\+\+Conv\+Cplt\+Callback}} (ADC\+\_\+\+Handle\+Type\+Def \texorpdfstring{$\ast$}{*}hadc)
\item 
void \doxymbox{\hyperlink{app__main__test_8c_ae494a9643f29b87d6d81e5264e60e57b}{HAL\+\_\+\+UART\+\_\+\+Rx\+Cplt\+Callback}} (UART\+\_\+\+Handle\+Type\+Def \texorpdfstring{$\ast$}{*}huart)
\item 
void \doxymbox{\hyperlink{app__main__test_8c_a925534fb8bf7ca464fd05c982fe4bfa0}{HAL\+\_\+\+UARTEx\+\_\+\+Rx\+Event\+Callback}} (UART\+\_\+\+Handle\+Type\+Def \texorpdfstring{$\ast$}{*}huart, uint16\+\_\+t Size)
\item 
void \doxymbox{\hyperlink{app__main__test_8c_abcdf9b59049eccbc87d54042f9235b1a}{HAL\+\_\+\+UART\+\_\+\+Tx\+Cplt\+Callback}} (UART\+\_\+\+Handle\+Type\+Def \texorpdfstring{$\ast$}{*}huart)
\item 
void \doxymbox{\hyperlink{app__main__test_8c_a0a99ab4f6aa6ee7dc2abca5483910dde}{HAL\+\_\+\+SPI\+\_\+\+Tx\+Cplt\+Callback}} (SPI\+\_\+\+Handle\+Type\+Def \texorpdfstring{$\ast$}{*}hspi)
\item 
void \doxymbox{\hyperlink{app__main__test_8c_a3df7021fe24cf874f8b1eec5bd5f4cb3}{HAL\+\_\+\+SPI\+\_\+\+Rx\+Cplt\+Callback}} (SPI\+\_\+\+Handle\+Type\+Def \texorpdfstring{$\ast$}{*}hspi)
\item 
void \doxymbox{\hyperlink{app__main__test_8c_a04e63f382f172164c8e7cae4ff5d883c}{HAL\+\_\+\+SPI\+\_\+\+Tx\+Rx\+Cplt\+Callback}} (SPI\+\_\+\+Handle\+Type\+Def \texorpdfstring{$\ast$}{*}hspi)
\end{DoxyCompactItemize}
\doxysubsubsection*{Variables}
\begin{DoxyCompactItemize}
\item 
COM\+\_\+\+Init\+Type\+Def \doxymbox{\hyperlink{app__main__test_8c_acb96369fe128d70225ea05b727002522}{Bsp\+COMInit}}
\item 
\doxymbox{\hyperlink{app__main__test_8c_a89564acbd65a405bb1c578039bf875d5}{My\+Record\+\_\+t}}
\item 
RTC\+\_\+\+Time\+Type\+Def \doxymbox{\hyperlink{app__main__test_8c_afed4f29eda0f2d0900a0b347e29a8c91}{s\+Time}} = \{0\}
\item 
RTC\+\_\+\+Date\+Type\+Def \doxymbox{\hyperlink{app__main__test_8c_aa805acf5185e2a95f250a2da91bf84e0}{s\+Date}} = \{0\}
\item 
RTC\+\_\+\+Time\+Type\+Def \doxymbox{\hyperlink{app__main__test_8c_a0e1f2fa4a2707c513e5b7c21e01a9503}{s\+Time\+\_\+read}}
\item 
RTC\+\_\+\+Date\+Type\+Def \doxymbox{\hyperlink{app__main__test_8c_a764de331aa6fda8bf1e3c6715d56d63a}{s\+Date\+\_\+read}}
\end{DoxyCompactItemize}

\label{app__main__test_8c_doc-define-members}
\Hypertarget{app__main__test_8c_doc-define-members}
\doxysubsection{Macro Definition Documentation}
\Hypertarget{app__main__test_8c_af793d3343d4edebf2faac919e5756901}\index{app\_main\_test.c@{app\_main\_test.c}!BLE\_PARSING\_TIMER@{BLE\_PARSING\_TIMER}}
\index{BLE\_PARSING\_TIMER@{BLE\_PARSING\_TIMER}!app\_main\_test.c@{app\_main\_test.c}}
\doxysubsubsection{\texorpdfstring{BLE\_PARSING\_TIMER}{BLE\_PARSING\_TIMER}}
{\footnotesize\ttfamily \label{app__main__test_8c_af793d3343d4edebf2faac919e5756901} 
\+\#define BLE\+\_\+\+PARSING\+\_\+\+TIMER~25}

\Hypertarget{app__main__test_8c_a8c51fec63a4ab2daa27315bf9597aed7}\index{app\_main\_test.c@{app\_main\_test.c}!ENABLE\_ANALOG\_TESTS@{ENABLE\_ANALOG\_TESTS}}
\index{ENABLE\_ANALOG\_TESTS@{ENABLE\_ANALOG\_TESTS}!app\_main\_test.c@{app\_main\_test.c}}
\doxysubsubsection{\texorpdfstring{ENABLE\_ANALOG\_TESTS}{ENABLE\_ANALOG\_TESTS}}
{\footnotesize\ttfamily \label{app__main__test_8c_a8c51fec63a4ab2daa27315bf9597aed7} 
\+\#define ENABLE\+\_\+\+ANALOG\+\_\+\+TESTS~0}

\Hypertarget{app__main__test_8c_a4e459df6ec0ce374717a51518bfa4336}\index{app\_main\_test.c@{app\_main\_test.c}!ENABLE\_BLE\_TESTS@{ENABLE\_BLE\_TESTS}}
\index{ENABLE\_BLE\_TESTS@{ENABLE\_BLE\_TESTS}!app\_main\_test.c@{app\_main\_test.c}}
\doxysubsubsection{\texorpdfstring{ENABLE\_BLE\_TESTS}{ENABLE\_BLE\_TESTS}}
{\footnotesize\ttfamily \label{app__main__test_8c_a4e459df6ec0ce374717a51518bfa4336} 
\+\#define ENABLE\+\_\+\+BLE\+\_\+\+TESTS~0}

\Hypertarget{app__main__test_8c_a251f3809a0715a52895f901847b28ec3}\index{app\_main\_test.c@{app\_main\_test.c}!ENABLE\_DATALOG\_TESTS@{ENABLE\_DATALOG\_TESTS}}
\index{ENABLE\_DATALOG\_TESTS@{ENABLE\_DATALOG\_TESTS}!app\_main\_test.c@{app\_main\_test.c}}
\doxysubsubsection{\texorpdfstring{ENABLE\_DATALOG\_TESTS}{ENABLE\_DATALOG\_TESTS}}
{\footnotesize\ttfamily \label{app__main__test_8c_a251f3809a0715a52895f901847b28ec3} 
\+\#define ENABLE\+\_\+\+DATALOG\+\_\+\+TESTS~0}

\Hypertarget{app__main__test_8c_a6e84fd3ddadd283f5c329e977964ca8d}\index{app\_main\_test.c@{app\_main\_test.c}!ENABLE\_DS18B20\_TESTS@{ENABLE\_DS18B20\_TESTS}}
\index{ENABLE\_DS18B20\_TESTS@{ENABLE\_DS18B20\_TESTS}!app\_main\_test.c@{app\_main\_test.c}}
\doxysubsubsection{\texorpdfstring{ENABLE\_DS18B20\_TESTS}{ENABLE\_DS18B20\_TESTS}}
{\footnotesize\ttfamily \label{app__main__test_8c_a6e84fd3ddadd283f5c329e977964ca8d} 
\+\#define ENABLE\+\_\+\+DS18\+B20\+\_\+\+TESTS~0}

\Hypertarget{app__main__test_8c_a6982a0459ab84fb3f9c6b6b5f27cbd9a}\index{app\_main\_test.c@{app\_main\_test.c}!ENABLE\_FRAM\_TESTS@{ENABLE\_FRAM\_TESTS}}
\index{ENABLE\_FRAM\_TESTS@{ENABLE\_FRAM\_TESTS}!app\_main\_test.c@{app\_main\_test.c}}
\doxysubsubsection{\texorpdfstring{ENABLE\_FRAM\_TESTS}{ENABLE\_FRAM\_TESTS}}
{\footnotesize\ttfamily \label{app__main__test_8c_a6982a0459ab84fb3f9c6b6b5f27cbd9a} 
\+\#define ENABLE\+\_\+\+FRAM\+\_\+\+TESTS~0}

\Hypertarget{app__main__test_8c_adff80ac59d9346ed44f00c4b927e6fd0}\index{app\_main\_test.c@{app\_main\_test.c}!ENABLE\_LORAWAN\_TESTS@{ENABLE\_LORAWAN\_TESTS}}
\index{ENABLE\_LORAWAN\_TESTS@{ENABLE\_LORAWAN\_TESTS}!app\_main\_test.c@{app\_main\_test.c}}
\doxysubsubsection{\texorpdfstring{ENABLE\_LORAWAN\_TESTS}{ENABLE\_LORAWAN\_TESTS}}
{\footnotesize\ttfamily \label{app__main__test_8c_adff80ac59d9346ed44f00c4b927e6fd0} 
\+\#define ENABLE\+\_\+\+LORAWAN\+\_\+\+TESTS~0}

\Hypertarget{app__main__test_8c_a36e156bd8846a33cfb53d1cf3f3cc038}\index{app\_main\_test.c@{app\_main\_test.c}!ENABLE\_LPP\_TESTS@{ENABLE\_LPP\_TESTS}}
\index{ENABLE\_LPP\_TESTS@{ENABLE\_LPP\_TESTS}!app\_main\_test.c@{app\_main\_test.c}}
\doxysubsubsection{\texorpdfstring{ENABLE\_LPP\_TESTS}{ENABLE\_LPP\_TESTS}}
{\footnotesize\ttfamily \label{app__main__test_8c_a36e156bd8846a33cfb53d1cf3f3cc038} 
\+\#define ENABLE\+\_\+\+LPP\+\_\+\+TESTS~0}

\label{app__main__test_8c_doc-enum-members}
\Hypertarget{app__main__test_8c_doc-enum-members}
\doxysubsection{Enumeration Type Documentation}
\Hypertarget{app__main__test_8c_a51eb73cd19803fc310a1817bedc66722}\index{app\_main\_test.c@{app\_main\_test.c}!MainApp\_State\_t@{MainApp\_State\_t}}
\index{MainApp\_State\_t@{MainApp\_State\_t}!app\_main\_test.c@{app\_main\_test.c}}
\doxysubsubsection{\texorpdfstring{MainApp\_State\_t}{MainApp\_State\_t}}
{\footnotesize\ttfamily \label{app__main__test_8c_a51eb73cd19803fc310a1817bedc66722} 
enum \doxymbox{\hyperlink{app__main__test_8c_a51eb73cd19803fc310a1817bedc66722}{Main\+App\+\_\+\+State\+\_\+t}}}

\begin{DoxyEnumFields}[2]{Enumerator}
\raisebox{\heightof{T}}[0pt][0pt]{\index{APP\_STATE\_INIT\_LORA@{APP\_STATE\_INIT\_LORA}!app\_main\_test.c@{app\_main\_test.c}}
\index{app\_main\_test.c@{app\_main\_test.c}!APP\_STATE\_INIT\_LORA@{APP\_STATE\_INIT\_LORA}}
}\Hypertarget{app__main__test_8c_a51eb73cd19803fc310a1817bedc66722a7bed2cbf33a9fd2c8dab28b984509b2d}\label{app__main__test_8c_a51eb73cd19803fc310a1817bedc66722a7bed2cbf33a9fd2c8dab28b984509b2d} 
APP\+\_\+\+STATE\+\_\+\+INIT\+\_\+\+LORA&\\
\hline

\raisebox{\heightof{T}}[0pt][0pt]{\index{APP\_STATE\_WAIT\_MEASURE@{APP\_STATE\_WAIT\_MEASURE}!app\_main\_test.c@{app\_main\_test.c}}
\index{app\_main\_test.c@{app\_main\_test.c}!APP\_STATE\_WAIT\_MEASURE@{APP\_STATE\_WAIT\_MEASURE}}
}\Hypertarget{app__main__test_8c_a51eb73cd19803fc310a1817bedc66722afce2db10ab1359fbaa7aed9839b9b7d3}\label{app__main__test_8c_a51eb73cd19803fc310a1817bedc66722afce2db10ab1359fbaa7aed9839b9b7d3} 
APP\+\_\+\+STATE\+\_\+\+WAIT\+\_\+\+MEASURE&\\
\hline

\raisebox{\heightof{T}}[0pt][0pt]{\index{APP\_STATE\_SAVE\_RECORD@{APP\_STATE\_SAVE\_RECORD}!app\_main\_test.c@{app\_main\_test.c}}
\index{app\_main\_test.c@{app\_main\_test.c}!APP\_STATE\_SAVE\_RECORD@{APP\_STATE\_SAVE\_RECORD}}
}\Hypertarget{app__main__test_8c_a51eb73cd19803fc310a1817bedc66722a8bab74073fca34c806e9c63cf2b4fa5c}\label{app__main__test_8c_a51eb73cd19803fc310a1817bedc66722a8bab74073fca34c806e9c63cf2b4fa5c} 
APP\+\_\+\+STATE\+\_\+\+SAVE\+\_\+\+RECORD&\\
\hline

\raisebox{\heightof{T}}[0pt][0pt]{\index{APP\_STATE\_WAIT\_SAVE@{APP\_STATE\_WAIT\_SAVE}!app\_main\_test.c@{app\_main\_test.c}}
\index{app\_main\_test.c@{app\_main\_test.c}!APP\_STATE\_WAIT\_SAVE@{APP\_STATE\_WAIT\_SAVE}}
}\Hypertarget{app__main__test_8c_a51eb73cd19803fc310a1817bedc66722a5b645e7af891597e657cd22766f91b3c}\label{app__main__test_8c_a51eb73cd19803fc310a1817bedc66722a5b645e7af891597e657cd22766f91b3c} 
APP\+\_\+\+STATE\+\_\+\+WAIT\+\_\+\+SAVE&\\
\hline

\raisebox{\heightof{T}}[0pt][0pt]{\index{APP\_STATE\_SEND\_LORA@{APP\_STATE\_SEND\_LORA}!app\_main\_test.c@{app\_main\_test.c}}
\index{app\_main\_test.c@{app\_main\_test.c}!APP\_STATE\_SEND\_LORA@{APP\_STATE\_SEND\_LORA}}
}\Hypertarget{app__main__test_8c_a51eb73cd19803fc310a1817bedc66722abf64b3f50e4bd0c831783127693508ed}\label{app__main__test_8c_a51eb73cd19803fc310a1817bedc66722abf64b3f50e4bd0c831783127693508ed} 
APP\+\_\+\+STATE\+\_\+\+SEND\+\_\+\+LORA&\\
\hline

\raisebox{\heightof{T}}[0pt][0pt]{\index{APP\_STATE\_WAIT\_TX@{APP\_STATE\_WAIT\_TX}!app\_main\_test.c@{app\_main\_test.c}}
\index{app\_main\_test.c@{app\_main\_test.c}!APP\_STATE\_WAIT\_TX@{APP\_STATE\_WAIT\_TX}}
}\Hypertarget{app__main__test_8c_a51eb73cd19803fc310a1817bedc66722af653c7450b549886625e73447f12f1f0}\label{app__main__test_8c_a51eb73cd19803fc310a1817bedc66722af653c7450b549886625e73447f12f1f0} 
APP\+\_\+\+STATE\+\_\+\+WAIT\+\_\+\+TX&\\
\hline

\raisebox{\heightof{T}}[0pt][0pt]{\index{APP\_STATE\_WAIT\_LORA\_SLEEP@{APP\_STATE\_WAIT\_LORA\_SLEEP}!app\_main\_test.c@{app\_main\_test.c}}
\index{app\_main\_test.c@{app\_main\_test.c}!APP\_STATE\_WAIT\_LORA\_SLEEP@{APP\_STATE\_WAIT\_LORA\_SLEEP}}
}\Hypertarget{app__main__test_8c_a51eb73cd19803fc310a1817bedc66722a70a990acc81602a40e8babdb5d606b06}\label{app__main__test_8c_a51eb73cd19803fc310a1817bedc66722a70a990acc81602a40e8babdb5d606b06} 
APP\+\_\+\+STATE\+\_\+\+WAIT\+\_\+\+LORA\+\_\+\+SLEEP&\\
\hline

\raisebox{\heightof{T}}[0pt][0pt]{\index{APP\_STATE\_SLEEP@{APP\_STATE\_SLEEP}!app\_main\_test.c@{app\_main\_test.c}}
\index{app\_main\_test.c@{app\_main\_test.c}!APP\_STATE\_SLEEP@{APP\_STATE\_SLEEP}}
}\Hypertarget{app__main__test_8c_a51eb73cd19803fc310a1817bedc66722af8aeb5a9c3fdd9dfc888f09d7df9fe8d}\label{app__main__test_8c_a51eb73cd19803fc310a1817bedc66722af8aeb5a9c3fdd9dfc888f09d7df9fe8d} 
APP\+\_\+\+STATE\+\_\+\+SLEEP&\\
\hline

\raisebox{\heightof{T}}[0pt][0pt]{\index{APP\_STATE\_BLE\_ACTIVE@{APP\_STATE\_BLE\_ACTIVE}!app\_main\_test.c@{app\_main\_test.c}}
\index{app\_main\_test.c@{app\_main\_test.c}!APP\_STATE\_BLE\_ACTIVE@{APP\_STATE\_BLE\_ACTIVE}}
}\Hypertarget{app__main__test_8c_a51eb73cd19803fc310a1817bedc66722a1ba3f22c125d192f1880c4706902e94f}\label{app__main__test_8c_a51eb73cd19803fc310a1817bedc66722a1ba3f22c125d192f1880c4706902e94f} 
APP\+\_\+\+STATE\+\_\+\+BLE\+\_\+\+ACTIVE&\\
\hline

\end{DoxyEnumFields}

\label{app__main__test_8c_doc-func-members}
\Hypertarget{app__main__test_8c_doc-func-members}
\doxysubsection{Function Documentation}
\Hypertarget{app__main__test_8c_ab898071398b359603a35c202e9c65f3b}\index{app\_main\_test.c@{app\_main\_test.c}!\_\_attribute\_\_@{\_\_attribute\_\_}}
\index{\_\_attribute\_\_@{\_\_attribute\_\_}!app\_main\_test.c@{app\_main\_test.c}}
\doxysubsubsection{\texorpdfstring{\_\_attribute\_\_()}{\_\_attribute\_\_()}}
{\footnotesize\ttfamily \label{app__main__test_8c_ab898071398b359603a35c202e9c65f3b} 
struct \+\_\+\+\_\+attribute\+\_\+\+\_\+ (\begin{DoxyParamCaption}\item[{(packed)}]{}{}\end{DoxyParamCaption})}

Here is the caller graph for this function:\+
\nopagebreak
\begin{figure}[H]
\begin{center}
\leavevmode

\end{center}
\end{figure}
\Hypertarget{app__main__test_8c_af20a88180db1113be1e89266917d148b}\index{app\_main\_test.c@{app\_main\_test.c}!HAL\_ADC\_ConvCpltCallback@{HAL\_ADC\_ConvCpltCallback}}
\index{HAL\_ADC\_ConvCpltCallback@{HAL\_ADC\_ConvCpltCallback}!app\_main\_test.c@{app\_main\_test.c}}
\doxysubsubsection{\texorpdfstring{HAL\_ADC\_ConvCpltCallback()}{HAL\_ADC\_ConvCpltCallback()}}
{\footnotesize\ttfamily \label{app__main__test_8c_af20a88180db1113be1e89266917d148b} 
void HAL\+\_\+\+ADC\+\_\+\+Conv\+Cplt\+Callback (\begin{DoxyParamCaption}\item[{ADC\+\_\+\+Handle\+Type\+Def \texorpdfstring{$\ast$}{*}}]{hadc}{}\end{DoxyParamCaption})}

Here is the call graph for this function:\+
\nopagebreak
\begin{figure}[H]
\begin{center}
\leavevmode

\end{center}
\end{figure}
\Hypertarget{app__main__test_8c_a0b334860563f4a109443e0a604af2300}\index{app\_main\_test.c@{app\_main\_test.c}!HAL\_GPIO\_EXTI\_Falling\_Callback@{HAL\_GPIO\_EXTI\_Falling\_Callback}}
\index{HAL\_GPIO\_EXTI\_Falling\_Callback@{HAL\_GPIO\_EXTI\_Falling\_Callback}!app\_main\_test.c@{app\_main\_test.c}}
\doxysubsubsection{\texorpdfstring{HAL\_GPIO\_EXTI\_Falling\_Callback()}{HAL\_GPIO\_EXTI\_Falling\_Callback()}}
{\footnotesize\ttfamily \label{app__main__test_8c_a0b334860563f4a109443e0a604af2300} 
void HAL\+\_\+\+GPIO\+\_\+\+EXTI\+\_\+\+Falling\+\_\+\+Callback (\begin{DoxyParamCaption}\item[{uint16\+\_\+t}]{GPIO\+\_\+\+Pin}{}\end{DoxyParamCaption})}

\Hypertarget{app__main__test_8c_ac1dd7334499ef88df8187a45c0d28ee8}\index{app\_main\_test.c@{app\_main\_test.c}!HAL\_LPTIM\_AutoReloadMatchCallback@{HAL\_LPTIM\_AutoReloadMatchCallback}}
\index{HAL\_LPTIM\_AutoReloadMatchCallback@{HAL\_LPTIM\_AutoReloadMatchCallback}!app\_main\_test.c@{app\_main\_test.c}}
\doxysubsubsection{\texorpdfstring{HAL\_LPTIM\_AutoReloadMatchCallback()}{HAL\_LPTIM\_AutoReloadMatchCallback()}}
{\footnotesize\ttfamily \label{app__main__test_8c_ac1dd7334499ef88df8187a45c0d28ee8} 
void HAL\+\_\+\+LPTIM\+\_\+\+Auto\+Reload\+Match\+Callback (\begin{DoxyParamCaption}\item[{LPTIM\+\_\+\+Handle\+Type\+Def \texorpdfstring{$\ast$}{*}}]{hlptim}{}\end{DoxyParamCaption})}

\Hypertarget{app__main__test_8c_a3df7021fe24cf874f8b1eec5bd5f4cb3}\index{app\_main\_test.c@{app\_main\_test.c}!HAL\_SPI\_RxCpltCallback@{HAL\_SPI\_RxCpltCallback}}
\index{HAL\_SPI\_RxCpltCallback@{HAL\_SPI\_RxCpltCallback}!app\_main\_test.c@{app\_main\_test.c}}
\doxysubsubsection{\texorpdfstring{HAL\_SPI\_RxCpltCallback()}{HAL\_SPI\_RxCpltCallback()}}
{\footnotesize\ttfamily \label{app__main__test_8c_a3df7021fe24cf874f8b1eec5bd5f4cb3} 
void HAL\+\_\+\+SPI\+\_\+\+Rx\+Cplt\+Callback (\begin{DoxyParamCaption}\item[{SPI\+\_\+\+Handle\+Type\+Def \texorpdfstring{$\ast$}{*}}]{hspi}{}\end{DoxyParamCaption})}

Here is the call graph for this function:\+
\nopagebreak
\begin{figure}[H]
\begin{center}
\leavevmode

\end{center}
\end{figure}
\Hypertarget{app__main__test_8c_a0a99ab4f6aa6ee7dc2abca5483910dde}\index{app\_main\_test.c@{app\_main\_test.c}!HAL\_SPI\_TxCpltCallback@{HAL\_SPI\_TxCpltCallback}}
\index{HAL\_SPI\_TxCpltCallback@{HAL\_SPI\_TxCpltCallback}!app\_main\_test.c@{app\_main\_test.c}}
\doxysubsubsection{\texorpdfstring{HAL\_SPI\_TxCpltCallback()}{HAL\_SPI\_TxCpltCallback()}}
{\footnotesize\ttfamily \label{app__main__test_8c_a0a99ab4f6aa6ee7dc2abca5483910dde} 
void HAL\+\_\+\+SPI\+\_\+\+Tx\+Cplt\+Callback (\begin{DoxyParamCaption}\item[{SPI\+\_\+\+Handle\+Type\+Def \texorpdfstring{$\ast$}{*}}]{hspi}{}\end{DoxyParamCaption})}

Here is the call graph for this function:\+
\nopagebreak
\begin{figure}[H]
\begin{center}
\leavevmode

\end{center}
\end{figure}
\Hypertarget{app__main__test_8c_a04e63f382f172164c8e7cae4ff5d883c}\index{app\_main\_test.c@{app\_main\_test.c}!HAL\_SPI\_TxRxCpltCallback@{HAL\_SPI\_TxRxCpltCallback}}
\index{HAL\_SPI\_TxRxCpltCallback@{HAL\_SPI\_TxRxCpltCallback}!app\_main\_test.c@{app\_main\_test.c}}
\doxysubsubsection{\texorpdfstring{HAL\_SPI\_TxRxCpltCallback()}{HAL\_SPI\_TxRxCpltCallback()}}
{\footnotesize\ttfamily \label{app__main__test_8c_a04e63f382f172164c8e7cae4ff5d883c} 
void HAL\+\_\+\+SPI\+\_\+\+Tx\+Rx\+Cplt\+Callback (\begin{DoxyParamCaption}\item[{SPI\+\_\+\+Handle\+Type\+Def \texorpdfstring{$\ast$}{*}}]{hspi}{}\end{DoxyParamCaption})}

Here is the call graph for this function:\+
\nopagebreak
\begin{figure}[H]
\begin{center}
\leavevmode

\end{center}
\end{figure}
\Hypertarget{app__main__test_8c_ae494a9643f29b87d6d81e5264e60e57b}\index{app\_main\_test.c@{app\_main\_test.c}!HAL\_UART\_RxCpltCallback@{HAL\_UART\_RxCpltCallback}}
\index{HAL\_UART\_RxCpltCallback@{HAL\_UART\_RxCpltCallback}!app\_main\_test.c@{app\_main\_test.c}}
\doxysubsubsection{\texorpdfstring{HAL\_UART\_RxCpltCallback()}{HAL\_UART\_RxCpltCallback()}}
{\footnotesize\ttfamily \label{app__main__test_8c_ae494a9643f29b87d6d81e5264e60e57b} 
void HAL\+\_\+\+UART\+\_\+\+Rx\+Cplt\+Callback (\begin{DoxyParamCaption}\item[{UART\+\_\+\+Handle\+Type\+Def \texorpdfstring{$\ast$}{*}}]{huart}{}\end{DoxyParamCaption})}

Here is the call graph for this function:\+
\nopagebreak
\begin{figure}[H]
\begin{center}
\leavevmode

\end{center}
\end{figure}
\Hypertarget{app__main__test_8c_abcdf9b59049eccbc87d54042f9235b1a}\index{app\_main\_test.c@{app\_main\_test.c}!HAL\_UART\_TxCpltCallback@{HAL\_UART\_TxCpltCallback}}
\index{HAL\_UART\_TxCpltCallback@{HAL\_UART\_TxCpltCallback}!app\_main\_test.c@{app\_main\_test.c}}
\doxysubsubsection{\texorpdfstring{HAL\_UART\_TxCpltCallback()}{HAL\_UART\_TxCpltCallback()}}
{\footnotesize\ttfamily \label{app__main__test_8c_abcdf9b59049eccbc87d54042f9235b1a} 
void HAL\+\_\+\+UART\+\_\+\+Tx\+Cplt\+Callback (\begin{DoxyParamCaption}\item[{UART\+\_\+\+Handle\+Type\+Def \texorpdfstring{$\ast$}{*}}]{huart}{}\end{DoxyParamCaption})}
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

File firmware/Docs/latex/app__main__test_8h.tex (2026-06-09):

\doxysection{C:\+/\+\+Users/\+valen/\+\+Documents/\+\+BUT GEII/\+\+SAE601/\+station\+\_\+analyse\+\_\+qualite\+\_\+eau/\+firmware/\+station\+\_\+analyse\+\_\+qualite\+\_\+eau/\+\+Core/\+\+Inc/\+app\+\_\+main\+\_\+test.h File Reference}
\hypertarget{app__main__test_8h}{}\label{app__main__test_8h}\index{C:/Users/valen/Documents/BUT GEII/SAE601/station\_analyse\_qualite\_eau/firmware/station\_analyse\_qualite\_eau/Core/Inc/app\_main\_test.h@{C:/Users/valen/Documents/BUT GEII/SAE601/station\_analyse\_qualite\_eau/firmware/station\_analyse\_qualite\_eau/Core/Inc/app\_main\_test.h}}
{\ttfamily \+\#include $<$stdbool.\+h$>$}\newline
Include dependency graph for app\+\_\+main\+\_\+test.\+h:\+
\nopagebreak
\begin{figure}[H]
\begin{center}
\leavevmode
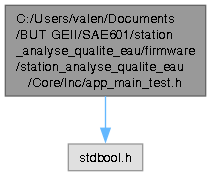
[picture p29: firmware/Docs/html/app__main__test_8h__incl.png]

\end{center}
\end{figure}
This graph shows which files directly or indirectly include this file:\+
\nopagebreak
\begin{figure}[H]
\begin{center}
\leavevmode
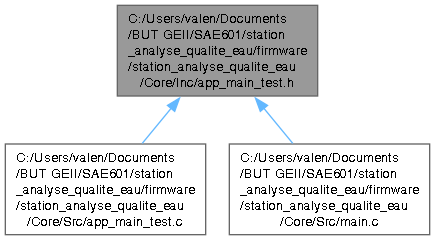
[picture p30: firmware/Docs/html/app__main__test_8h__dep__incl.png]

\end{center}
\end{figure}
\doxysubsubsection*{Functions}
\begin{DoxyCompactItemize}
\item 
void \doxymbox{\hyperlink{app__main__test_8h_a7dfd9b79bc5a37d7df40207afbc5431f}{setup}} (void)
\item 
void \doxymbox{\hyperlink{app__main__test_8h_a0b33edabd7f1c4e4a0bf32c67269be2f}{loop}} (void)
\end{DoxyCompactItemize}

\label{app__main__test_8h_doc-func-members}
\Hypertarget{app__main__test_8h_doc-func-members}
\doxysubsection{Function Documentation}
\Hypertarget{app__main__test_8h_a0b33edabd7f1c4e4a0bf32c67269be2f}\index{app\_main\_test.h@{app\_main\_test.h}!loop@{loop}}
\index{loop@{loop}!app\_main\_test.h@{app\_main\_test.h}}
\doxysubsubsection{\texorpdfstring{loop()}{loop()}}
{\footnotesize\ttfamily \label{app__main__test_8h_a0b33edabd7f1c4e4a0bf32c67269be2f} 
void loop (\begin{DoxyParamCaption}\item[{void}]{}{}\end{DoxyParamCaption})}

Here is the call graph for this function:\+
\nopagebreak
\begin{figure}[H]
\begin{center}
\leavevmode
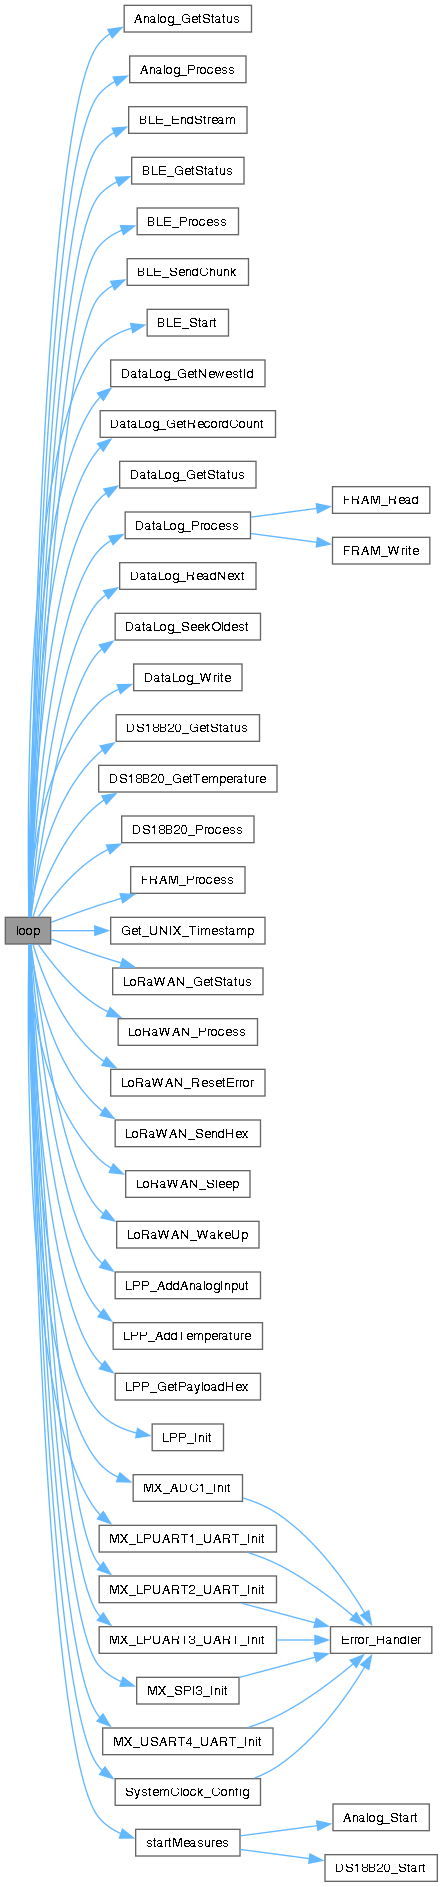
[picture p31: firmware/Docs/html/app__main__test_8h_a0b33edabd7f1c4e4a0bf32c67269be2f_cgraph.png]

\end{center}
\end{figure}
Here is the caller graph for this function:\+
\nopagebreak
\begin{figure}[H]
\begin{center}
\leavevmode

\end{center}
\end{figure}
\Hypertarget{app__main__test_8h_a7dfd9b79bc5a37d7df40207afbc5431f}\index{app\_main\_test.h@{app\_main\_test.h}!setup@{setup}}
\index{setup@{setup}!app\_main\_test.h@{app\_main\_test.h}}
\doxysubsubsection{\texorpdfstring{setup()}{setup()}}
{\footnotesize\ttfamily \label{app__main__test_8h_a7dfd9b79bc5a37d7df40207afbc5431f} 
void setup (\begin{DoxyParamCaption}\item[{void}]{}{}\end{DoxyParamCaption})}

Here is the call graph for this function:\+
\nopagebreak
\begin{figure}[H]
\begin{center}
\leavevmode
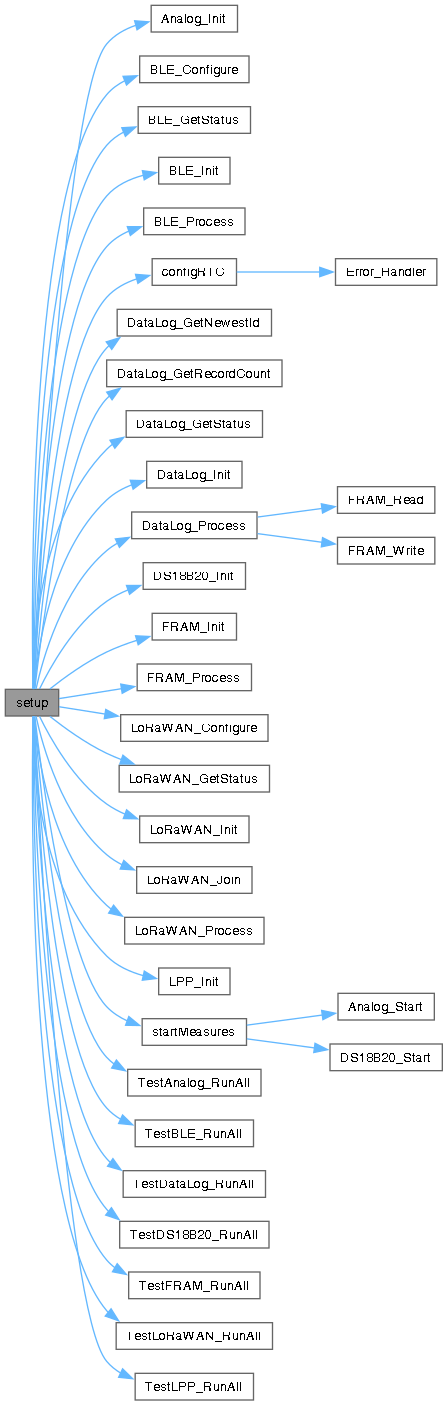
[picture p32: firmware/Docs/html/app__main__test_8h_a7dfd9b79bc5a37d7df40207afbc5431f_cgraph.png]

\end{center}
\end{figure}
Here is the caller graph for this function:\+
\nopagebreak
\begin{figure}[H]
\begin{center}
\leavevmode

\end{center}
\end{figure}

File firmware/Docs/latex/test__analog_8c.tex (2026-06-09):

\doxysection{C:\+/\+\+Users/\+valen/\+\+Documents/\+\+BUT GEII/\+\+SAE601/\+station\+\_\+analyse\+\_\+qualite\+\_\+eau/\+firmware/\+station\+\_\+analyse\+\_\+qualite\+\_\+eau/\+\+Core/\+\+Src/\+test\+\_\+analog.c File Reference}
\hypertarget{test__analog_8c}{}\label{test__analog_8c}\index{C:/Users/valen/Documents/BUT GEII/SAE601/station\_analyse\_qualite\_eau/firmware/station\_analyse\_qualite\_eau/Core/Src/test\_analog.c@{C:/Users/valen/Documents/BUT GEII/SAE601/station\_analyse\_qualite\_eau/firmware/station\_analyse\_qualite\_eau/Core/Src/test\_analog.c}}

Implémentation des tests de robustesse analogique.  

{\ttfamily \+\#include "{}test\+\_\+analog.\+h"{}}\newline
{\ttfamily \+\#include $<$stdio.\+h$>$}\newline
Include dependency graph for test\+\_\+analog.\+c:\+
\nopagebreak
\begin{figure}[H]
\begin{center}
\leavevmode
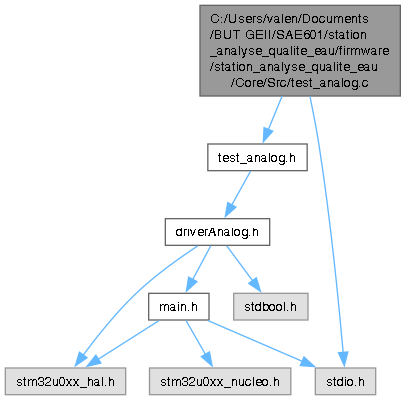
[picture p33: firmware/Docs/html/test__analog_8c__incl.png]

\end{center}
\end{figure}
\doxysubsubsection*{Macros}
\begin{DoxyCompactItemize}
\item 
\+\#define \doxymbox{\hyperlink{test__analog_8c_a2ddacbe405fe687f6fb48cdcbebf2f3b}{EXPECT}}(cond,  msg)
\item 
\+\#define \doxymbox{\hyperlink{test__analog_8c_a6ffea8cdf1ef4b07935b62dc59d009db}{EXPECT\+\_\+\+EQ}}(actual,  expected,  msg)
\end{DoxyCompactItemize}
\doxysubsubsection*{Functions}
\begin{DoxyCompactItemize}
\item 
bool \doxymbox{\hyperlink{test__analog_8c_a0c311f10c4e675eccb5ba0e2d64557bc}{Test\+Analog\+\_\+\+Run\+All}} (\doxymbox{\hyperlink{struct_analog__t}{Analog\+\_\+t}} \texorpdfstring{$\ast$}{*}hanalog)
\begin{DoxyCompactList}\small\item\em Lance tous les tests de la couche analogique. \end{DoxyCompactList}\end{DoxyCompactItemize}

\doxysubsection{Detailed Description}
Implémentation des tests de robustesse analogique. 

\label{test__analog_8c_doc-define-members}
\Hypertarget{test__analog_8c_doc-define-members}
\doxysubsection{Macro Definition Documentation}
\Hypertarget{test__analog_8c_a2ddacbe405fe687f6fb48cdcbebf2f3b}\index{test\_analog.c@{test\_analog.c}!EXPECT@{EXPECT}}
\index{EXPECT@{EXPECT}!test\_analog.c@{test\_analog.c}}
\doxysubsubsection{\texorpdfstring{EXPECT}{EXPECT}}
{\footnotesize\ttfamily \label{test__analog_8c_a2ddacbe405fe687f6fb48cdcbebf2f3b} 
\+\#define EXPECT(\begin{DoxyParamCaption}\item[{}]{cond}{, }\item[{}]{msg}{}\end{DoxyParamCaption})}

{\bfseries Value:\+}
\begin{DoxyCode}{0}
\DoxyCodeLine{\textcolor{keywordflow}{do}\ \{\ \ \ \ \ \ \ \ \ \ \ \ \ \ \ \ \ \ \ \ \ \ \ \ \ \ \ \ \ \ \ \ \ \ \ \ \ \ \ \ \ \ \ \ \ \ \ \ \ \ \ \ \ \ \ \ \ \ \ \ \(\backslash\)}
\DoxyCodeLine{\ \ \ \ if\ (!(cond))\ \{\ \ \ \ \ \ \ \ \ \ \ \ \ \ \ \ \ \ \ \ \ \ \ \ \ \ \ \ \ \ \ \ \ \ \ \ \ \ \ \ \ \ \ \ \ \ \(\backslash\)}
\DoxyCodeLine{\ \ \ \ \ \ \ \ printf(\textcolor{stringliteral}{"{}\ \ [FAIL]\ \%s\ (ligne\ \%d)\(\backslash\)r\(\backslash\)n"{}},\ msg,\ \_\_LINE\_\_);\ \ \ \ \(\backslash\)}
\DoxyCodeLine{\ \ \ \ \ \ \ \ \textcolor{keywordflow}{return}\ \textcolor{keyword}{false};\ \ \ \ \ \ \ \ \ \ \ \ \ \ \ \ \ \ \ \ \ \ \ \ \ \ \ \ \ \ \ \ \ \ \ \ \ \ \ \ \ \ \ \(\backslash\)}
\DoxyCodeLine{\ \ \ \ \}\ \textcolor{keywordflow}{else}\ \{\ \ \ \ \ \ \ \ \ \ \ \ \ \ \ \ \ \ \ \ \ \ \ \ \ \ \ \ \ \ \ \ \ \ \ \ \ \ \ \ \ \ \ \ \ \ \ \ \ \ \ \ \(\backslash\)}
\DoxyCodeLine{\ \ \ \ \ \ \ \ printf(\textcolor{stringliteral}{"{}\ \ [\ OK\ ]\ \%s\(\backslash\)r\(\backslash\)n"{}},\ msg);\ \ \ \ \ \ \ \ \ \ \ \ \ \ \ \ \ \ \ \ \ \ \ \ \ \(\backslash\)}
\DoxyCodeLine{\ \ \ \ \}\ \ \ \ \ \ \ \ \ \ \ \ \ \ \ \ \ \ \ \ \ \ \ \ \ \ \ \ \ \ \ \ \ \ \ \ \ \ \ \ \ \ \ \ \ \ \ \ \ \ \ \ \ \ \ \ \ \ \ \(\backslash\)}
\DoxyCodeLine{\}\ \textcolor{keywordflow}{while}\ (0)}

\end{DoxyCode}
\Hypertarget{test__analog_8c_a6ffea8cdf1ef4b07935b62dc59d009db}\index{test\_analog.c@{test\_analog.c}!EXPECT\_EQ@{EXPECT\_EQ}}
\index{EXPECT\_EQ@{EXPECT\_EQ}!test\_analog.c@{test\_analog.c}}
\doxysubsubsection{\texorpdfstring{EXPECT\_EQ}{EXPECT\_EQ}}
{\footnotesize\ttfamily \label{test__analog_8c_a6ffea8cdf1ef4b07935b62dc59d009db} 
\+\#define EXPECT\+\_\+\+EQ(\begin{DoxyParamCaption}\item[{}]{actual}{, }\item[{}]{expected}{, }\item[{}]{msg}{}\end{DoxyParamCaption})}

{\bfseries Value:\+}
\begin{DoxyCode}{0}
\DoxyCodeLine{\textcolor{keywordflow}{do}\ \{\ \ \ \ \ \ \ \ \ \ \ \ \ \ \ \ \ \ \ \ \ \ \ \ \ \ \ \ \ \ \ \ \ \ \ \ \ \ \ \ \ \ \ \ \ \ \ \ \ \ \ \ \ \ \ \ \ \ \ \ \ \ \ \ \ \ \ \ \(\backslash\)}
\DoxyCodeLine{\ \ \ \ if\ ((actual)\ !=\ (expected))\ \{\ \ \ \ \ \ \ \ \ \ \ \ \ \ \ \ \ \ \ \ \ \ \ \ \ \ \ \ \ \ \ \ \ \ \ \ \ \ \ \(\backslash\)}
\DoxyCodeLine{\ \ \ \ \ \ \ \ printf(\textcolor{stringliteral}{"{}\ \ [FAIL]\ \%s\ -\/\ Recu:\ \%d,\ Attendu:\ \%d\ (ligne\ \%d)\(\backslash\)r\(\backslash\)n"{}},\ \ \ \ \(\backslash\)}
\DoxyCodeLine{\ \ \ \ \ \ \ \ \ \ \ \ \ \ \ msg,\ (\textcolor{keywordtype}{int})actual,\ (\textcolor{keywordtype}{int})expected,\ \_\_LINE\_\_);\ \ \ \ \ \ \ \ \ \ \ \ \ \ \(\backslash\)}
\DoxyCodeLine{\ \ \ \ \ \ \ \ \textcolor{keywordflow}{return}\ \textcolor{keyword}{false};\ \ \ \ \ \ \ \ \ \ \ \ \ \ \ \ \ \ \ \ \ \ \ \ \ \ \ \ \ \ \ \ \ \ \ \ \ \ \ \ \ \ \ \ \ \ \ \ \ \ \ \(\backslash\)}
\DoxyCodeLine{\ \ \ \ \}\ \textcolor{keywordflow}{else}\ \{\ \ \ \ \ \ \ \ \ \ \ \ \ \ \ \ \ \ \ \ \ \ \ \ \ \ \ \ \ \ \ \ \ \ \ \ \ \ \ \ \ \ \ \ \ \ \ \ \ \ \ \ \ \ \ \ \ \ \ \ \(\backslash\)}
\DoxyCodeLine{\ \ \ \ \ \ \ \ printf(\textcolor{stringliteral}{"{}\ \ [\ OK\ ]\ \%s\(\backslash\)r\(\backslash\)n"{}},\ msg);\ \ \ \ \ \ \ \ \ \ \ \ \ \ \ \ \ \ \ \ \ \ \ \ \ \ \ \ \ \ \ \ \ \(\backslash\)}
\DoxyCodeLine{\ \ \ \ \}\ \ \ \ \ \ \ \ \ \ \ \ \ \ \ \ \ \ \ \ \ \ \ \ \ \ \ \ \ \ \ \ \ \ \ \ \ \ \ \ \ \ \ \ \ \ \ \ \ \ \ \ \ \ \ \ \ \ \ \ \ \ \ \ \ \ \ \(\backslash\)}
\DoxyCodeLine{\}\ \textcolor{keywordflow}{while}\ (0)}

\end{DoxyCode}

\label{test__analog_8c_doc-func-members}
\Hypertarget{test__analog_8c_doc-func-members}
\doxysubsection{Function Documentation}
\Hypertarget{test__analog_8c_a0c311f10c4e675eccb5ba0e2d64557bc}\index{test\_analog.c@{test\_analog.c}!TestAnalog\_RunAll@{TestAnalog\_RunAll}}
\index{TestAnalog\_RunAll@{TestAnalog\_RunAll}!test\_analog.c@{test\_analog.c}}
\doxysubsubsection{\texorpdfstring{TestAnalog\_RunAll()}{TestAnalog\_RunAll()}}
{\footnotesize\ttfamily \label{test__analog_8c_a0c311f10c4e675eccb5ba0e2d64557bc} 
bool Test\+Analog\+\_\+\+Run\+All (\begin{DoxyParamCaption}\item[{\doxymbox{\hyperlink{struct_analog__t}{Analog\+\_\+t}} \texorpdfstring{$\ast$}{*}}]{hanalog}{}\end{DoxyParamCaption})}

Lance tous les tests de la couche analogique. 

\begin{DoxyParams}{Parameters}
{\em hanalog} & Pointeur vers le handle analogique de l\textquotesingle{}application. \\
\hline
\end{DoxyParams}
\begin{DoxyReturn}{Returns}
true si succès, false si une erreur critique est détectée. 
\end{DoxyReturn}
Here is the caller graph for this function:\+
\nopagebreak
\begin{figure}[H]
\begin{center}
\leavevmode

\end{center}
\end{figure}

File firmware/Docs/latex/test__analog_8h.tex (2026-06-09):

\doxysection{C:\+/\+\+Users/\+valen/\+\+Documents/\+\+BUT GEII/\+\+SAE601/\+station\+\_\+analyse\+\_\+qualite\+\_\+eau/\+firmware/\+station\+\_\+analyse\+\_\+qualite\+\_\+eau/\+\+Core/\+\+Inc/\+test\+\_\+analog.h File Reference}
\hypertarget{test__analog_8h}{}\label{test__analog_8h}\index{C:/Users/valen/Documents/BUT GEII/SAE601/station\_analyse\_qualite\_eau/firmware/station\_analyse\_qualite\_eau/Core/Inc/test\_analog.h@{C:/Users/valen/Documents/BUT GEII/SAE601/station\_analyse\_qualite\_eau/firmware/station\_analyse\_qualite\_eau/Core/Inc/test\_analog.h}}

Batterie de tests unitaires pour le driver Analogique.  

{\ttfamily \+\#include "{}driver\+Analog.\+h"{}}\newline
Include dependency graph for test\+\_\+analog.\+h:\+
\nopagebreak
\begin{figure}[H]
\begin{center}
\leavevmode
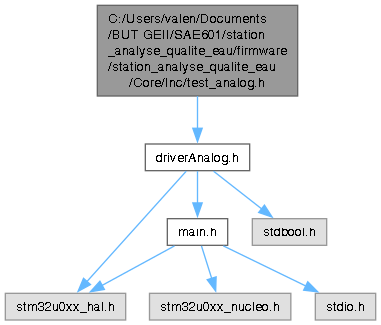
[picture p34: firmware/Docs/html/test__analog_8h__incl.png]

\end{center}
\end{figure}
This graph shows which files directly or indirectly include this file:\+
\nopagebreak
\begin{figure}[H]
\begin{center}
\leavevmode
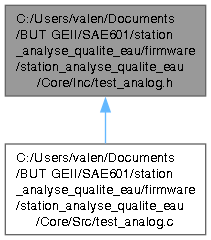
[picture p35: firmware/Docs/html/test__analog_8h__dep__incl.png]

\end{center}
\end{figure}
\doxysubsubsection*{Functions}
\begin{DoxyCompactItemize}
\item 
bool \doxymbox{\hyperlink{test__analog_8h_a0c311f10c4e675eccb5ba0e2d64557bc}{Test\+Analog\+\_\+\+Run\+All}} (\doxymbox{\hyperlink{struct_analog__t}{Analog\+\_\+t}} \texorpdfstring{$\ast$}{*}hanalog)
\begin{DoxyCompactList}\small\item\em Lance tous les tests de la couche analogique. \end{DoxyCompactList}\end{DoxyCompactItemize}

\doxysubsection{Detailed Description}
Batterie de tests unitaires pour le driver Analogique. 

\label{test__analog_8h_doc-func-members}
\Hypertarget{test__analog_8h_doc-func-members}
\doxysubsection{Function Documentation}
\Hypertarget{test__analog_8h_a0c311f10c4e675eccb5ba0e2d64557bc}\index{test\_analog.h@{test\_analog.h}!TestAnalog\_RunAll@{TestAnalog\_RunAll}}
\index{TestAnalog\_RunAll@{TestAnalog\_RunAll}!test\_analog.h@{test\_analog.h}}
\doxysubsubsection{\texorpdfstring{TestAnalog\_RunAll()}{TestAnalog\_RunAll()}}
{\footnotesize\ttfamily \label{test__analog_8h_a0c311f10c4e675eccb5ba0e2d64557bc} 
bool Test\+Analog\+\_\+\+Run\+All (\begin{DoxyParamCaption}\item[{\doxymbox{\hyperlink{struct_analog__t}{Analog\+\_\+t}} \texorpdfstring{$\ast$}{*}}]{hanalog}{}\end{DoxyParamCaption})}

Lance tous les tests de la couche analogique. 

\begin{DoxyParams}{Parameters}
{\em hanalog} & Pointeur vers le handle analogique de l\textquotesingle{}application. \\
\hline
\end{DoxyParams}
\begin{DoxyReturn}{Returns}
true si succès, false si une erreur critique est détectée. 
\end{DoxyReturn}
Here is the caller graph for this function:\+
\nopagebreak
\begin{figure}[H]
\begin{center}
\leavevmode

\end{center}
\end{figure}

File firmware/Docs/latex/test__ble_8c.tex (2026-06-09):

\doxysection{C:\+/\+\+Users/\+valen/\+\+Documents/\+\+BUT GEII/\+\+SAE601/\+station\+\_\+analyse\+\_\+qualite\+\_\+eau/\+firmware/\+station\+\_\+analyse\+\_\+qualite\+\_\+eau/\+\+Core/\+\+Src/\+test\+\_\+ble.c File Reference}
\hypertarget{test__ble_8c}{}\label{test__ble_8c}\index{C:/Users/valen/Documents/BUT GEII/SAE601/station\_analyse\_qualite\_eau/firmware/station\_analyse\_qualite\_eau/Core/Src/test\_ble.c@{C:/Users/valen/Documents/BUT GEII/SAE601/station\_analyse\_qualite\_eau/firmware/station\_analyse\_qualite\_eau/Core/Src/test\_ble.c}}

Implémentation des tests de robustesse BLE.  

{\ttfamily \+\#include "{}test\+\_\+ble.\+h"{}}\newline
{\ttfamily \+\#include $<$stdio.\+h$>$}\newline
{\ttfamily \+\#include $<$string.\+h$>$}\newline
{\ttfamily \+\#include "{}main.\+h"{}}\newline
Include dependency graph for test\+\_\+ble.\+c:\+
\nopagebreak
\begin{figure}[H]
\begin{center}
\leavevmode
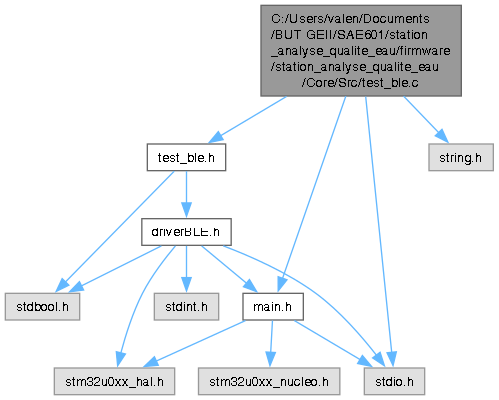
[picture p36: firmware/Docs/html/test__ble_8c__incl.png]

\end{center}
\end{figure}
\doxysubsubsection*{Macros}
\begin{DoxyCompactItemize}
\item 
\+\#define \doxymbox{\hyperlink{test__ble_8c_a2ddacbe405fe687f6fb48cdcbebf2f3b}{EXPECT}}(cond,  msg)
\item 
\+\#define \doxymbox{\hyperlink{test__ble_8c_a6ffea8cdf1ef4b07935b62dc59d009db}{EXPECT\+\_\+\+EQ}}(actual,  expected,  msg)
\end{DoxyCompactItemize}
\doxysubsubsection*{Functions}
\begin{DoxyCompactItemize}
\item 
bool \doxymbox{\hyperlink{test__ble_8c_a24bbc8e479f3772288b340a50478401b}{Test\+BLE\+\_\+\+Run\+All}} (\doxymbox{\hyperlink{struct_b_l_e__t}{BLE\+\_\+t}} \texorpdfstring{$\ast$}{*}hble)
\begin{DoxyCompactList}\small\item\em Lance tous les tests de la couche BLE. \end{DoxyCompactList}\end{DoxyCompactItemize}

\doxysubsection{Detailed Description}
Implémentation des tests de robustesse BLE. 

\label{test__ble_8c_doc-define-members}
\Hypertarget{test__ble_8c_doc-define-members}
\doxysubsection{Macro Definition Documentation}
\Hypertarget{test__ble_8c_a2ddacbe405fe687f6fb48cdcbebf2f3b}\index{test\_ble.c@{test\_ble.c}!EXPECT@{EXPECT}}
\index{EXPECT@{EXPECT}!test\_ble.c@{test\_ble.c}}
\doxysubsubsection{\texorpdfstring{EXPECT}{EXPECT}}
{\footnotesize\ttfamily \label{test__ble_8c_a2ddacbe405fe687f6fb48cdcbebf2f3b} 
\+\#define EXPECT(\begin{DoxyParamCaption}\item[{}]{cond}{, }\item[{}]{msg}{}\end{DoxyParamCaption})}
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

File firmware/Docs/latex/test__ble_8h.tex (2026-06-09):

\doxysection{C:\+/\+\+Users/\+valen/\+\+Documents/\+\+BUT GEII/\+\+SAE601/\+station\+\_\+analyse\+\_\+qualite\+\_\+eau/\+firmware/\+station\+\_\+analyse\+\_\+qualite\+\_\+eau/\+\+Core/\+\+Inc/\+test\+\_\+ble.h File Reference}
\hypertarget{test__ble_8h}{}\label{test__ble_8h}\index{C:/Users/valen/Documents/BUT GEII/SAE601/station\_analyse\_qualite\_eau/firmware/station\_analyse\_qualite\_eau/Core/Inc/test\_ble.h@{C:/Users/valen/Documents/BUT GEII/SAE601/station\_analyse\_qualite\_eau/firmware/station\_analyse\_qualite\_eau/Core/Inc/test\_ble.h}}

Batterie de tests unitaires pour le driver BLE.
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

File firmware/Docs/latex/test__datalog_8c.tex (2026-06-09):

\doxysection{C:\+/\+\+Users/\+valen/\+\+Documents/\+\+BUT GEII/\+\+SAE601/\+station\+\_\+analyse\+\_\+qualite\+\_\+eau/\+firmware/\+station\+\_\+analyse\+\_\+qualite\+\_\+eau/\+\+Core/\+\+Src/\+test\+\_\+datalog.c File Reference}
\hypertarget{test__datalog_8c}{}\label{test__datalog_8c}\index{C:/Users/valen/Documents/BUT GEII/SAE601/station\_analyse\_qualite\_eau/firmware/station\_analyse\_qualite\_eau/Core/Src/test\_datalog.c@{C:/Users/valen/Documents/BUT
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

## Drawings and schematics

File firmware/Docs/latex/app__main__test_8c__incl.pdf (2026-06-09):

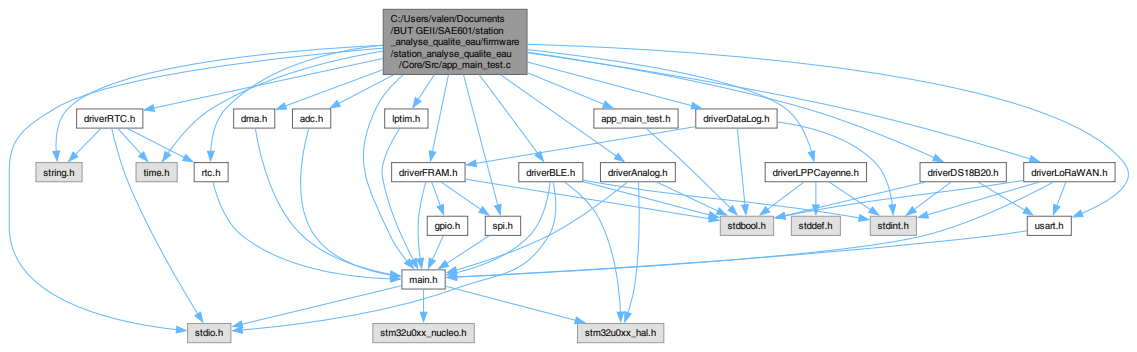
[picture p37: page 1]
stdio.h; string.h; time.h; app_main_test.h; usart.h; main.h; rtc.h; adc.h; spi.h; dma.h; lptim.h; driverFRAM.h; driverBLE.h; driverAnalog.h; driverLPPCayenne.h; driverDS18B20.h; driverDataLog.h; driverLoRaWAN.h; driverRTC.h; stdbool.h; stm32u0xx_nucleo.h; stm32u0xx_hal.h; gpio.h; stddef.h; stdint.h

C:/Users/valen/Documents
/BUT GEII/SAE601/station
_analyse_qualite_eau/firmware
/station_analyse_qualite_eau
/Core/Src/app_main_test.c

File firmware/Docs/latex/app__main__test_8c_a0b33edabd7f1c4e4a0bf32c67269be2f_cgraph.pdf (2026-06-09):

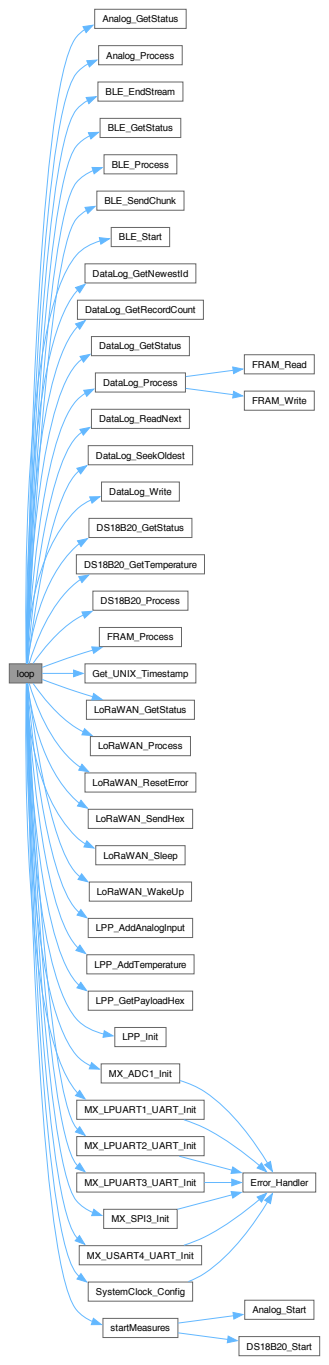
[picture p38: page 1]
loop; Analog_GetStatus; Analog_Process; BLE_EndStream; BLE_GetStatus; BLE_Process; BLE_SendChunk; BLE_Start; DataLog_GetNewestId; DataLog_GetRecordCount; DataLog_GetStatus; DataLog_Process; DataLog_ReadNext; DataLog_SeekOldest; DataLog_Write; DS18B20_GetStatus; DS18B20_GetTemperature; DS18B20_Process; FRAM_Process; Get_UNIX_Timestamp; LoRaWAN_GetStatus; LoRaWAN_Process; LoRaWAN_ResetError; LoRaWAN_SendHex; LoRaWAN_Sleep; LoRaWAN_WakeUp; LPP_AddAnalogInput; LPP_AddTemperature; LPP_GetPayloadHex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

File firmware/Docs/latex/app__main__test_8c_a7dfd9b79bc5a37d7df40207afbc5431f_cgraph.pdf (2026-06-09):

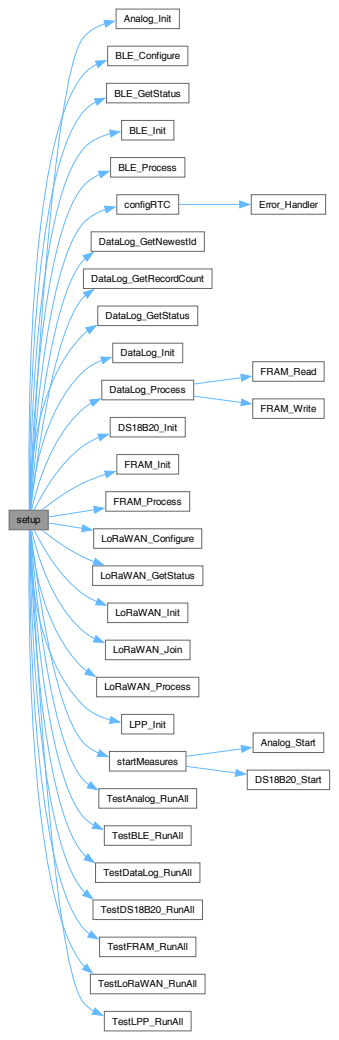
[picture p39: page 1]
setup; Analog_Init; BLE_Configure; BLE_GetStatus; BLE_Init; BLE_Process; configRTC; DataLog_GetNewestId; DataLog_GetRecordCount; DataLog_GetStatus; DataLog_Init; DataLog_Process; DS18B20_Init; FRAM_Init; FRAM_Process; LoRaWAN_Configure; LoRaWAN_GetStatus; LoRaWAN_Init; LoRaWAN_Join; LoRaWAN_Process; LPP_Init; startMeasures; TestAnalog_RunAll; TestBLE_RunAll; TestDataLog_RunAll; TestDS18B20_RunAll; TestFRAM_RunAll; TestLoRaWAN_RunAll; TestLPP_RunAll; Error_Handler; FRAM_Read; FRAM_Write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

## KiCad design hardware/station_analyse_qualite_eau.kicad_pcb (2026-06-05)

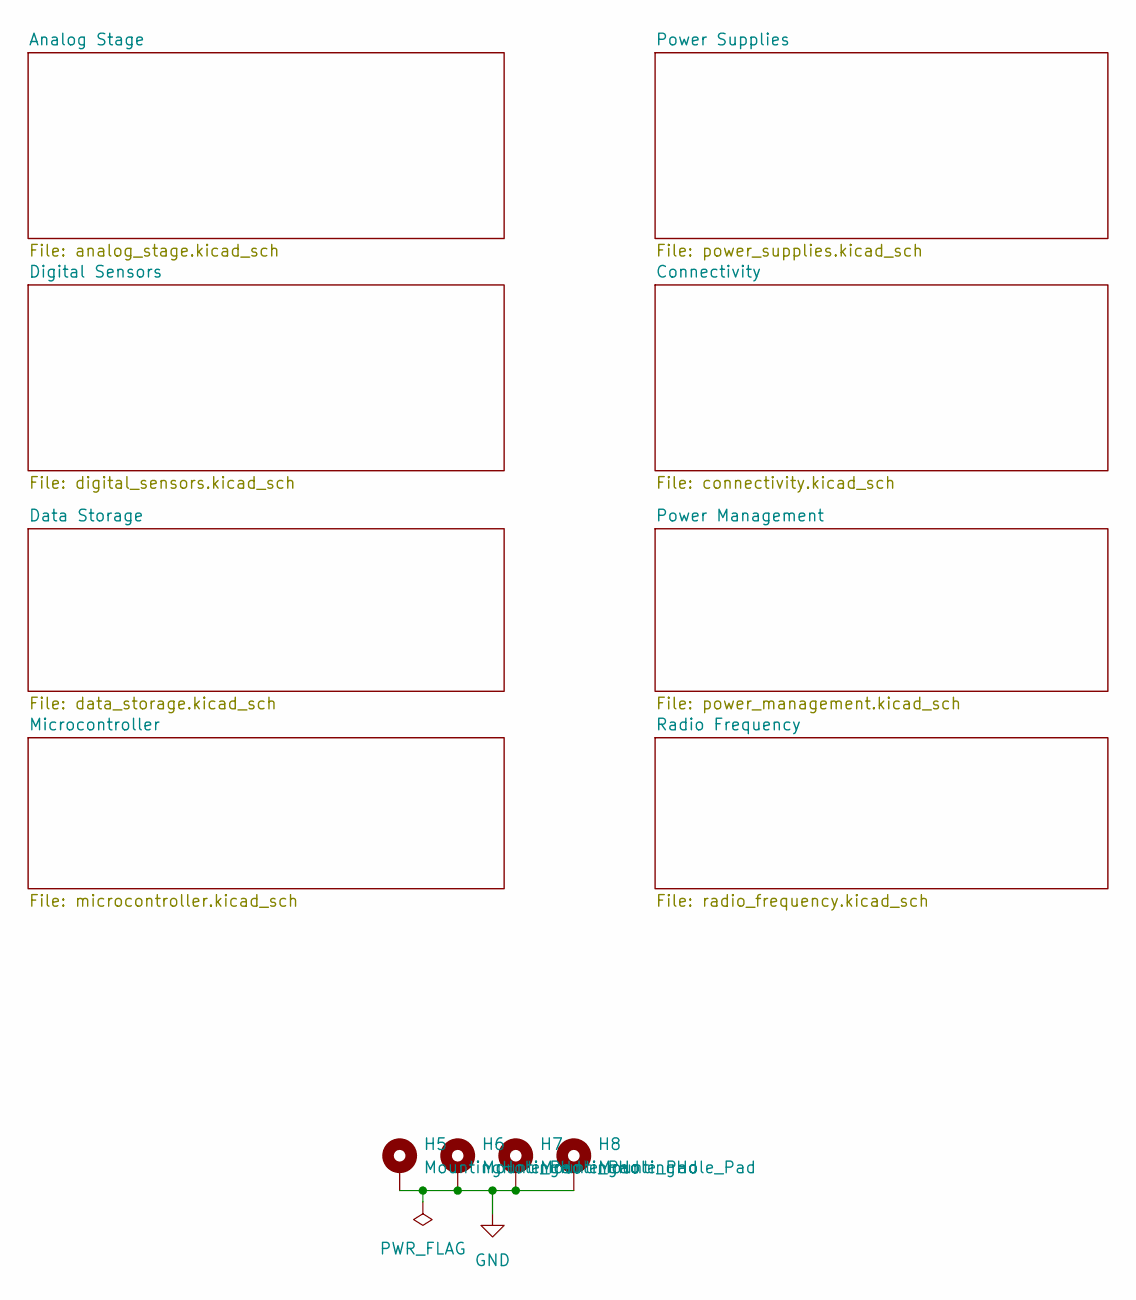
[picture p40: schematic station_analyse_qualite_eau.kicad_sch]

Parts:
H5, H6, H7, H8: MountingHole_Pad; MountingHole_3.2mm_M3_DIN965_Pad_TopBottom

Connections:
GND: H5.1 (1_1), H6.1 (1_1), H7.1 (1_1), H8.1 (1_1); also elsewhere on the board

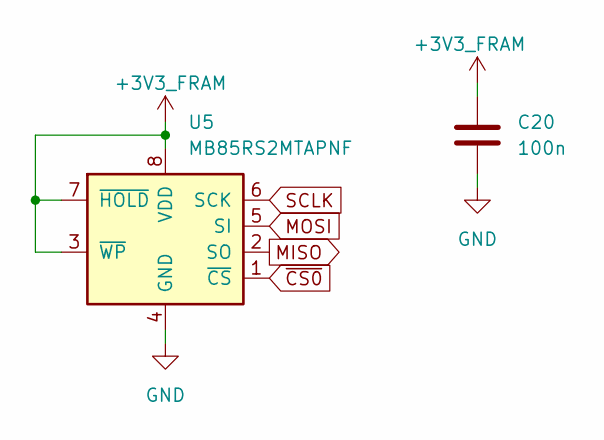
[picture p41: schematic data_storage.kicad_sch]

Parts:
C20: 100n; C_0805_2012Metric_Pad1.18x1.45mm_HandSolder; MPN KAM21BR71H104JM
U5: MB85RS2MTAPNF; SOIC-8_3.9x4.9mm_P1.27mm; MPN MB85RS2MTAPNF-G-BDERE1

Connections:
+3V3_FRAM: C20.1, U5.3 (~WP), U5.7 (~HOLD), U5.8 (VDD); also elsewhere on the board
GND: C20.2, U5.4 (GND); also elsewhere on the board
MISO: U5.2 (SO); also elsewhere on the board
MOSI: U5.5 (SI); also elsewhere on the board
SCLK: U5.6 (SCK); also elsewhere on the board
~CS0: U5.1 (~CS); also elsewhere on the board

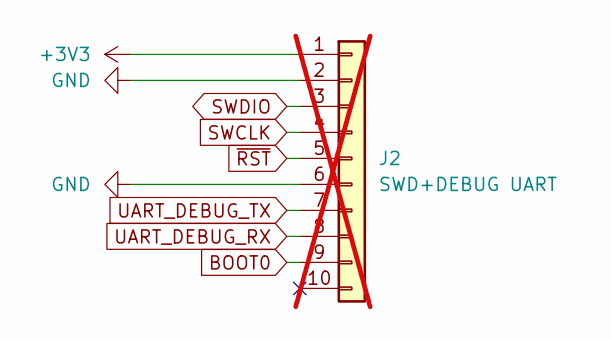
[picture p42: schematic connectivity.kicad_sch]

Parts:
J2: SWD+DEBUG UART; StaggeredHeader_1x10_P2.54mm_Vertical; not fitted

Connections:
+3V3: J2.1; also elsewhere on the board
BOOT0: J2.9; also elsewhere on the board
GND: J2.2, J2.6; also elsewhere on the board
SWCLK: J2.4; also elsewhere on the board
SWDIO: J2.3; also elsewhere on the board
UART_DEBUG_RX: J2.8; also elsewhere on the board
UART_DEBUG_TX: J2.7; also elsewhere on the board
~RST: J2.5; also elsewhere on the board

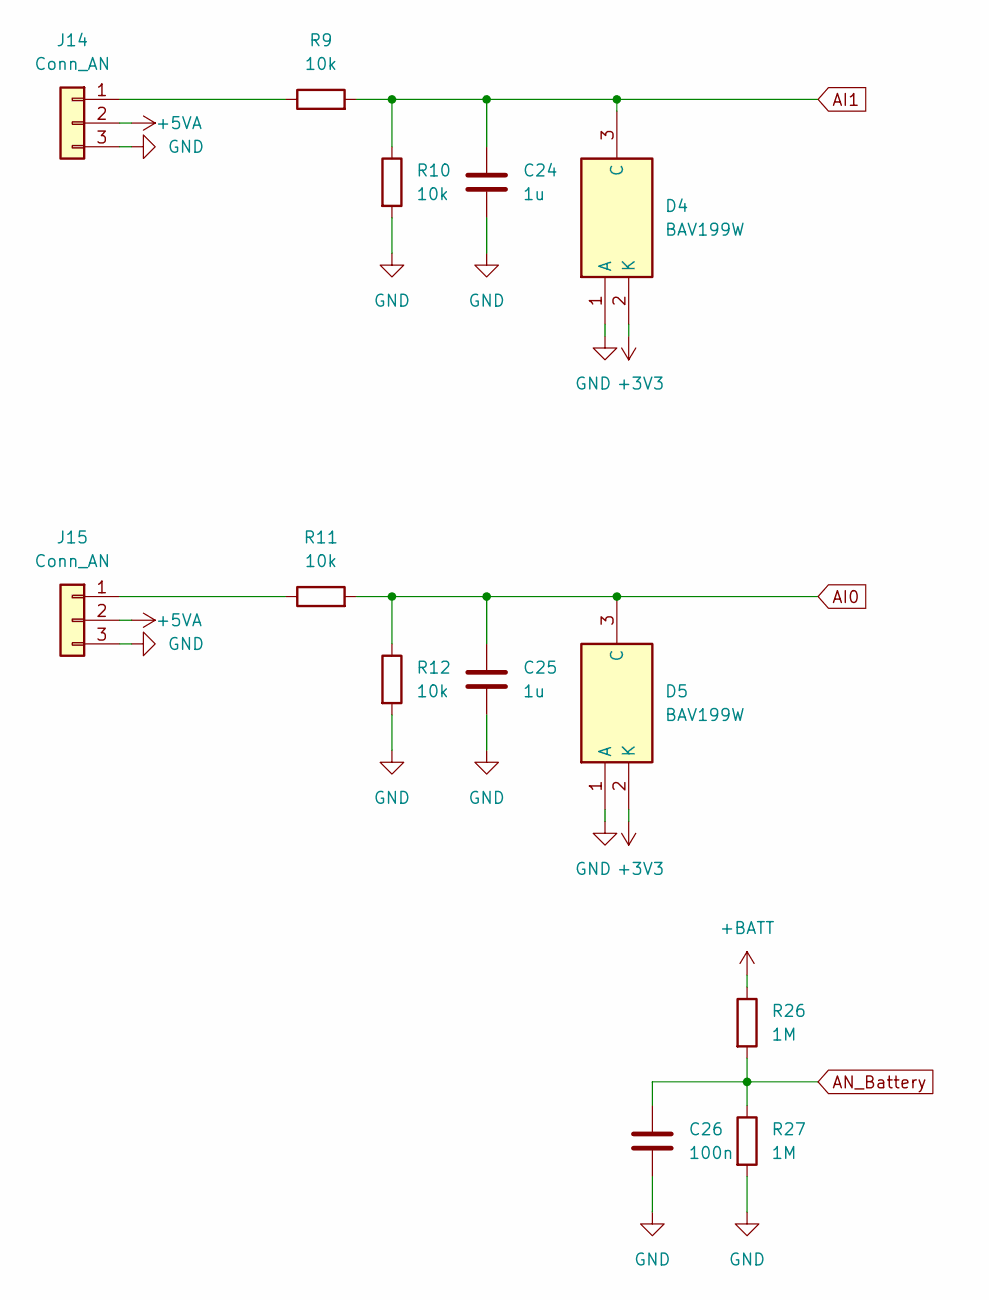
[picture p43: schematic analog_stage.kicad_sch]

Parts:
C24, C25: 1u; C_0805_2012Metric_Pad1.18x1.45mm_HandSolder; MPN KAM21KR71H105KL
C26: 100n; C_0805_2012Metric_Pad1.18x1.45mm_HandSolder; MPN KAM21BR71H104JM
D4, D5: BAV199W; SOT65P210X110-3N; Mouser Part Number 621-BAV199W-7
J14, J15: Conn_AN; Custom_PinHeader_1x03_P2.54mm_Horizontal; MPN 22-28-8030
R9, R10, R11, R12: 10k; R_0805_2012Metric_Pad1.20x1.40mm_HandSolder; Tolerance 0.1%; MPN 4-2176238-9
R26, R27: 1M; R_0805_2012Metric_Pad1.20x1.40mm_HandSolder; Tolerance 0.1%; MPN 1623141-1

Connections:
+3V3: D4.2 (K), D5.2 (K); also elsewhere on the board
+5VA: J14.2, J15.2; also elsewhere on the board
+BATT: R26.1; also elsewhere on the board
AI0: C25.1, D5.3 (C), R11.2, R12.1; also elsewhere on the board
AI1: C24.1, D4.3 (C), R9.2, R10.1; also elsewhere on the board
AN_Battery: C26.1, R26.2, R27.1; also elsewhere on the board
GND: C24.2, C25.2, C26.2, D4.1 (A), D5.1 (A), J14.3, J15.3, R10.2, R12.2, R27.2; also elsewhere on the board
unnamed: J14.1, R9.1
unnamed: J15.1, R11.1

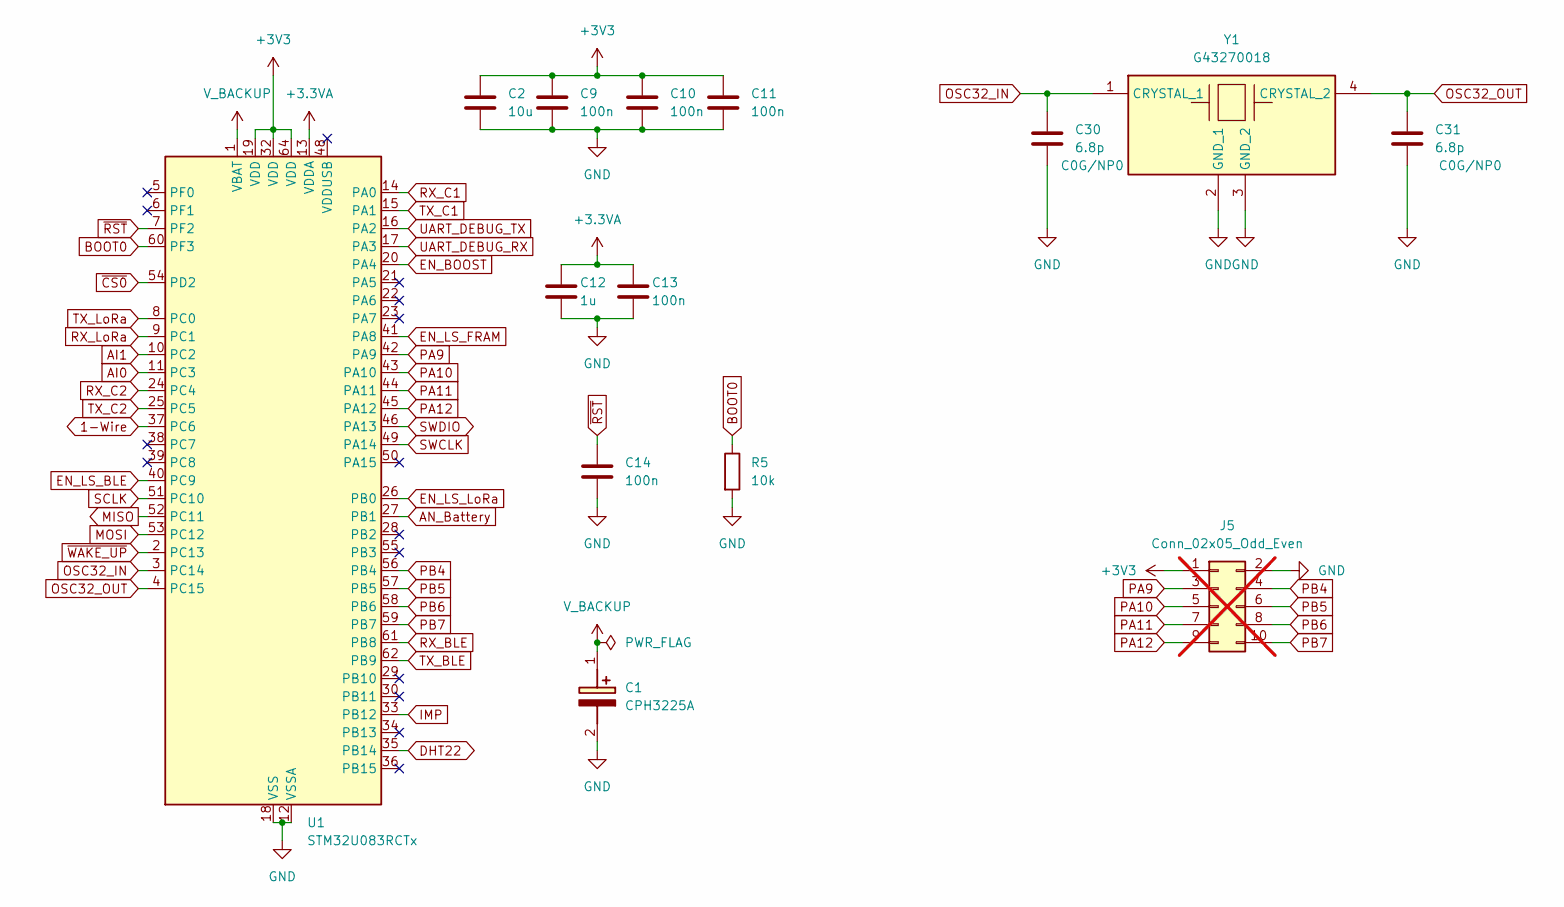
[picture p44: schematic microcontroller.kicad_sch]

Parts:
C1: CPH3225A; Mouser Part Number 628-CPH3225A
C2: 10u; C_0805_2012Metric_Pad1.18x1.45mm_HandSolder; MPN 0805X7R106KT1AT
C9, C10, C11, C13, C14: 100n; C_0805_2012Metric_Pad1.18x1.45mm_HandSolder; MPN KAM21BR71H104JM
C12: 1u; C_0805_2012Metric_Pad1.18x1.45mm_HandSolder; MPN KAM21KR71H105KL
C30: 6.8p; C_0805_2012Metric_Pad1.18x1.45mm_HandSolder; MPN 08051A6R8JAT2A
C31: 6.8p; C_0805_2012Metric_Pad1.18x1.45mm_HandSolder; Tolerance 5%; MPN 08051A6R8JAT2A
J5: Conn_02x05_Odd_Even; PinHeader_2x05_P2.54mm_Vertical; not fitted
R5: 10k; R_0805_2012Metric_Pad1.20x1.40mm_HandSolder; MPN RV0805JR-0710KL
U1: STM32U083RCTx; LQFP-64_10x10mm_P0.5mm; MPN STM32U083RCT6
Y1: G43270018; Mouser Part Number 729-G43270018

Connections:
1-Wire: U1.37 (PC6); also elsewhere on the board
+3.3VA: C12.1, C13.1, U1.13 (VDDA); also elsewhere on the board
+3V3: C2.1, C9.1, C10.1, C11.1, J5.1, U1.19 (VDD), U1.32 (VDD), U1.64 (VDD); also elsewhere on the board
AI0: U1.11 (PC3); also elsewhere on the board
AI1: U1.10 (PC2); also elsewhere on the board
AN_Battery: U1.27 (PB1); also elsewhere on the board
BOOT0: R5.1, U1.60 (PF3); also elsewhere on the board
DHT22: U1.35 (PB14); also elsewhere on the board
EN_BOOST: U1.20 (PA4); also elsewhere on the board
EN_LS_BLE: U1.40 (PC9); also elsewhere on the board
EN_LS_FRAM: U1.41 (PA8); also elsewhere on the board
EN_LS_LoRa: U1.26 (PB0); also elsewhere on the board
GND: C1.2 (-), C2.2, C9.2, C10.2, C11.2, C12.2, C13.2, C14.2, C30.2, C31.2, J5.2, R5.2, U1.12 (VSSA), U1.18 (VSS), U1.31 (VSS), U1.47 (VSS), U1.63 (VSS), Y1.2 (GND_1), Y1.3 (GND_2); also elsewhere on the board
IMP: U1.33 (PB12); also elsewhere on the board
MISO: U1.52 (PC11); also elsewhere on the board
MOSI: U1.53 (PC12); also elsewhere on the board
OSC32_IN: C30.1, U1.3 (PC14), Y1.1 (CRYSTAL_1)
OSC32_OUT: C31.1, U1.4 (PC15), Y1.4 (CRYSTAL_2)
PA9: J5.3, U1.42 (PA9)
PA10: J5.5, U1.43 (PA10)
PA11: J5.7, U1.44 (PA11)
PA12: J5.9, U1.45 (PA12)
PB4: J5.4, U1.56 (PB4)
PB5: J5.6, U1.57 (PB5)
PB6: J5.8, U1.58 (PB6)
PB7: J5.10, U1.59 (PB7)
RX_BLE: U1.61 (PB8); also elsewhere on the board
RX_C1: U1.14 (PA0); also elsewhere on the board
RX_C2: U1.24 (PC4); also elsewhere on the board
RX_LoRa: U1.9 (PC1); also elsewhere on the board
SCLK: U1.51 (PC10); also elsewhere on the board
SWCLK: U1.49 (PA14); also elsewhere on the board
SWDIO: U1.46 (PA13); also elsewhere on the board
TX_BLE: U1.62 (PB9); also elsewhere on the board
TX_C1: U1.15 (PA1); also elsewhere on the board
TX_C2: U1.25 (PC5); also elsewhere on the board
TX_LoRa: U1.8 (PC0); also elsewhere on the board
UART_DEBUG_RX: U1.17 (PA3); also elsewhere on the board
UART_DEBUG_TX: U1.16 (PA2); also elsewhere on the board
V_BACKUP: C1.1 (+), U1.1 (VBAT)
~CS0: U1.54 (PD2); also elsewhere on the board
~RST: C14.1, U1.7 (PF2); also elsewhere on the board
~WAKE_UP: U1.2 (PC13); also elsewhere on the board

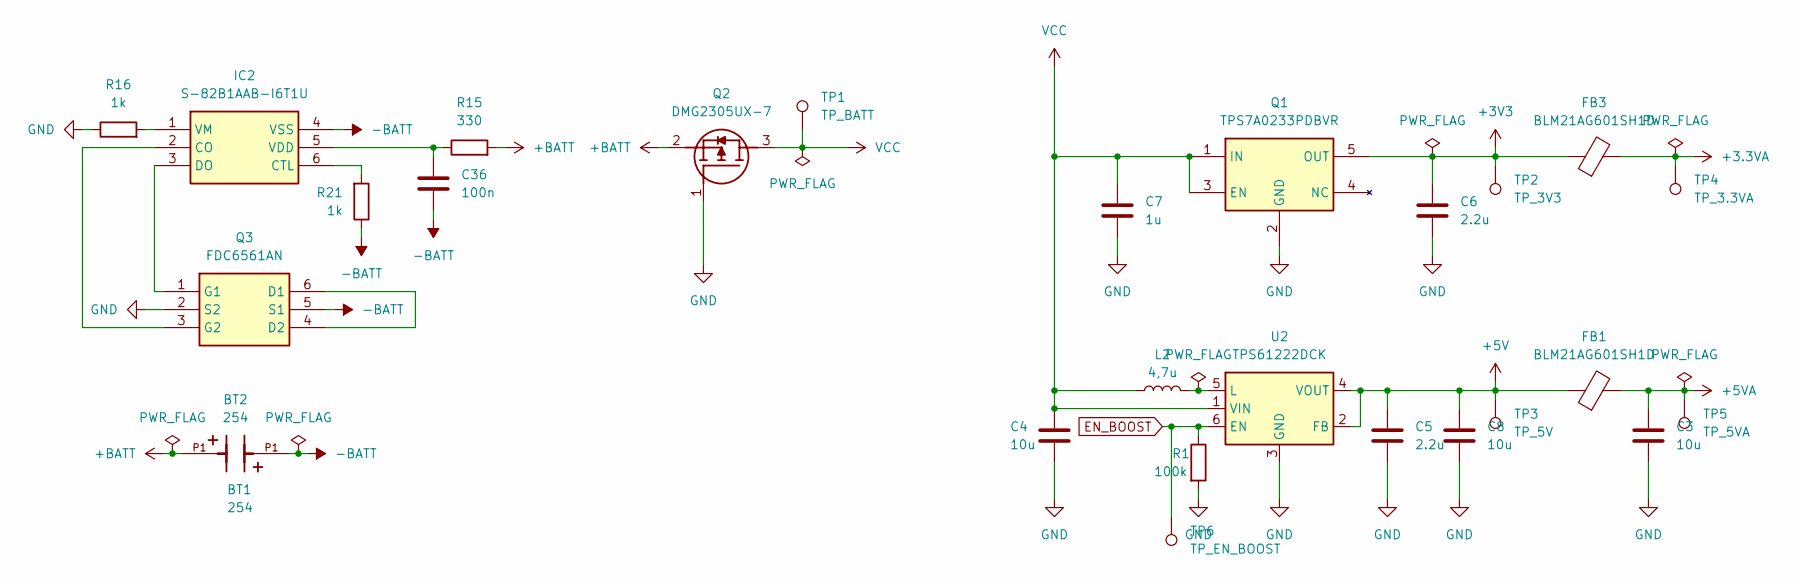
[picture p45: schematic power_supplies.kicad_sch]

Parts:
BT1, BT2: 254; BAT_254; PARTREV C
C3, C4, C8: 10u; C_0805_2012Metric_Pad1.18x1.45mm_HandSolder; MPN 0805X7R106KT1AT
C5, C6: 2.2u; C_0805_2012Metric_Pad1.18x1.45mm_HandSolder; MPN GXT21BR71C225KE01L
C7: 1u; C_0805_2012Metric_Pad1.18x1.45mm_HandSolder; MPN KAM21KR71H105KL
C36: 100n; C_0805_2012Metric_Pad1.18x1.45mm_HandSolder; MPN KAM21BR71H104JM
FB1, FB3: BLM21AG601SH1D; L_0805_2012Metric_Pad1.05x1.20mm_HandSolder; MPN BLM21AG601SH1D
IC2: S-82B1AAB-I6T1U; SOTFL50P180X50-6N; Mouser Part Number 628-S-82B1AAB-I6T1U
L2: 4,7u; 744031004; MPN 744031004
Q1: TPS7A0233PDBVR; SOT95P280X145-5N; Mouser Part Number 595-TPS7A0233PDBVR
Q2: DMG2305UX-7; SOT96P240X115-3N; Mouser Part Number 621-DMG2305UX-7
Q3: FDC6561AN; SOT95P280X110-6N; Mouser Part Number 512-FDC6561AN
R1: 100k; R_0805_2012Metric_Pad1.20x1.40mm_HandSolder; MPN TR0805NR-07100KL
R15: 330; R_0805_2012Metric_Pad1.20x1.40mm_HandSolder; MPN CRCW0805330RJNTA
R16, R21: 1k; R_0805_2012Metric_Pad1.20x1.40mm_HandSolder; MPN AC0805JR-071KL
TP1: TP_BATT; TestPoint_Pad_D2.0mm
TP2: TP_3V3; TestPoint_Pad_D2.0mm
TP3: TP_5V; TestPoint_Pad_D2.0mm
TP4: TP_3.3VA; TestPoint_Pad_D2.0mm
TP5: TP_5VA; TestPoint_Pad_D2.0mm
TP6: TP_EN_BOOST; TestPoint_Pad_D2.0mm
U2: TPS61222DCK; Texas_R-PDSO-G6; MPN TPS61222DCKT

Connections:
+3.3VA: FB3.2, TP4.1 (1_1); also elsewhere on the board
+3V3: C6.2, FB3.1, Q1.5 (OUT), TP2.1 (1_1); also elsewhere on the board
+5V: C5.2, C8.2, FB1.1, TP3.1 (1_1), U2.2 (FB), U2.4 (VOUT); also elsewhere on the board
+5VA: C3.2, FB1.2, TP5.1 (1_1); also elsewhere on the board
+BATT: BT1.P1, BT1.P2, Q2.2 (S), R15.2; also elsewhere on the board
-BATT: BT2.P1, BT2.P2, C36.2, IC2.4 (VSS), Q3.5 (S1), R21.1
EN_BOOST: R1.1, TP6.1 (1_1), U2.6 (EN); also elsewhere on the board
GND: C3.1, C4.1, C5.1, C6.1, C7.1, C8.1, Q1.2 (GND), Q2.1 (G), Q3.2 (S2), R1.2, R16.1, U2.3 (GND); also elsewhere on the board
unnamed: IC2.2 (CO), Q3.3 (G2)
unnamed: IC2.6 (CTL), R21.2
unnamed: IC2.3 (DO), Q3.1 (G1)
unnamed: C36.1, IC2.5 (VDD), R15.1
unnamed: IC2.1 (VM), R16.2
unnamed: Q3.4 (D2), Q3.6 (D1)
unnamed: L2.2, U2.5 (L)
VCC: C4.2, C7.2, L2.1, Q1.1 (IN), Q1.3 (EN), Q2.3 (D), TP1.1 (1_1), U2.1 (VIN)

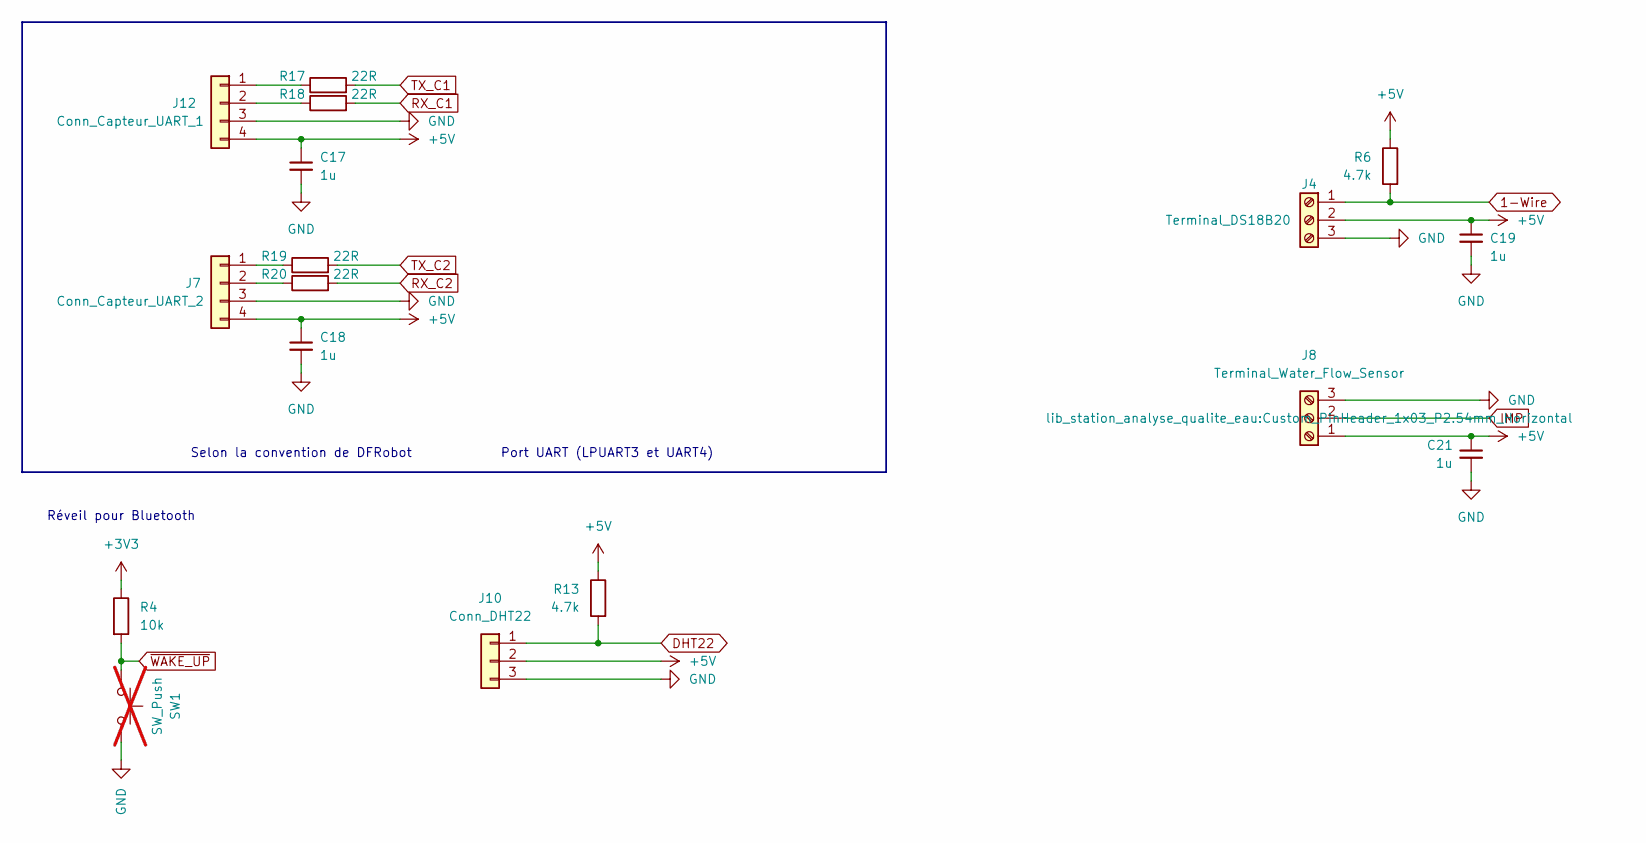
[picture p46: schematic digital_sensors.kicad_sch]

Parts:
C17, C18, C19, C21: 1u; C_0805_2012Metric_Pad1.18x1.45mm_HandSolder; MPN KAM21KR71H105KL
J4: Terminal_DS18B20; TBC05031GG; MPN TBC05-03-1-G-G
J7: Conn_Capteur_UART_2; Custom_PinHeader_1x04_P2.54mm_Horizontal; MPN 22-28-8040
J8: Terminal_Water_Flow_Sensor; Custom_PinHeader_1x03_P2.54mm_Horizontal; MPN 22-28-8030
J10: Conn_DHT22; Custom_PinHeader_1x03_P2.54mm_Horizontal; MPN 22-28-8030
J12: Conn_Capteur_UART_1; Custom_PinHeader_1x04_P2.54mm_Horizontal; MPN 22-28-8040
R4: 10k; R_0805_2012Metric_Pad1.20x1.40mm_HandSolder; MPN RV0805JR-0710KL
R6, R13: 4.7k; R_0805_2012Metric_Pad1.20x1.40mm_HandSolder; MPN RMCA0805JT4K70-HP
R17, R18, R19, R20: 22R; R_0805_2012Metric_Pad1.20x1.40mm_HandSolder; MPN CRCW080522R0JNEAC
SW1: SW_Push; P5.08mm; not fitted

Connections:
1-Wire: J4.1, R6.2; also elsewhere on the board
+3V3: R4.1; also elsewhere on the board
+5V: C17.1, C18.1, C19.1, C21.1, J4.2, J7.4, J8.1, J10.2, J12.4, R6.1, R13.1; also elsewhere on the board
DHT22: J10.1, R13.2; also elsewhere on the board
GND: C17.2, C18.2, C19.2, C21.2, J4.3, J7.3, J8.3, J10.3, J12.3, SW1.2; also elsewhere on the board
IMP: J8.2; also elsewhere on the board
unnamed: J7.1, R19.1
unnamed: J7.2, R20.1
unnamed: J12.1, R17.1
unnamed: J12.2, R18.1
RX_C1: R18.2; also elsewhere on the board
RX_C2: R20.2; also elsewhere on the board
TX_C1: R17.2; also elsewhere on the board
TX_C2: R19.2; also elsewhere on the board
~WAKE_UP: R4.2, SW1.1; also elsewhere on the board

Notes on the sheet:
Port UART (LPUART3 et UART4)
Réveil pour Bluetooth
Selon la convention de DFRobot

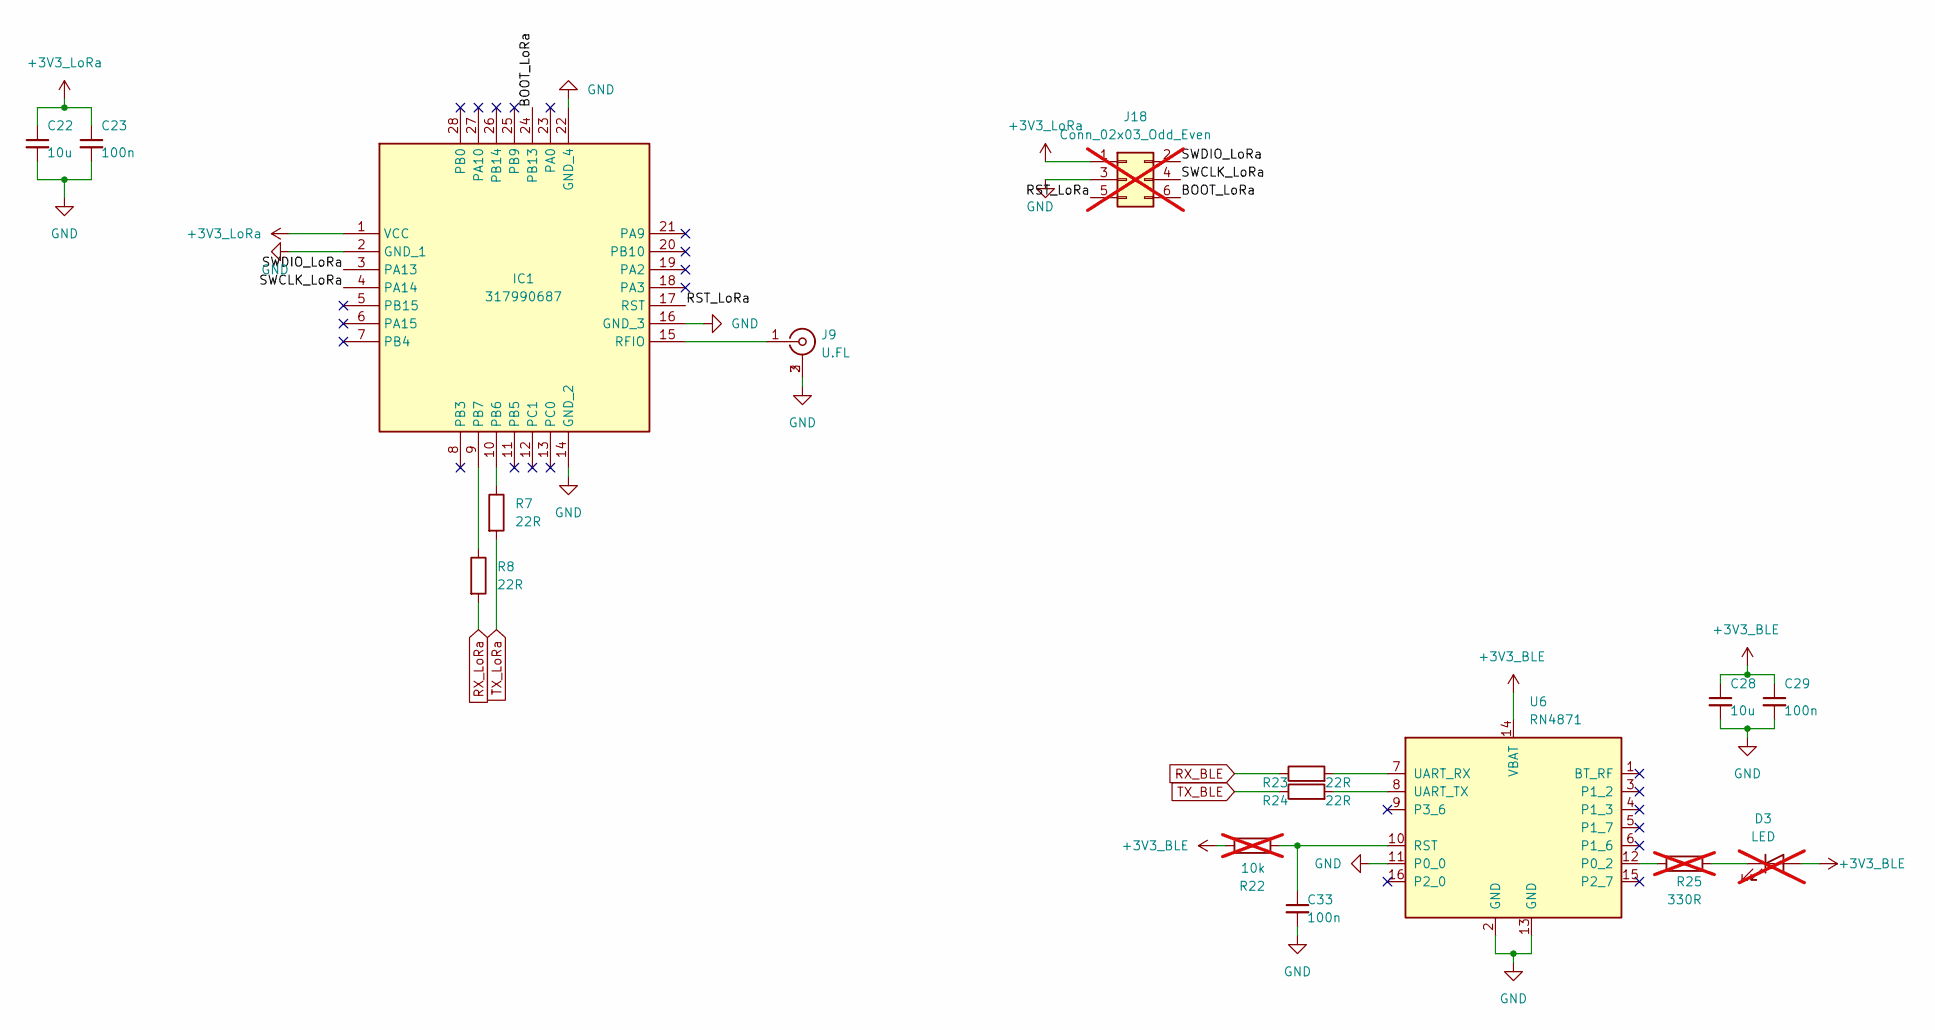
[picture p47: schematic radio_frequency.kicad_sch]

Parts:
C22, C28: 10u; C_0805_2012Metric_Pad1.18x1.45mm_HandSolder; MPN 0805X7R106KT1AT
C23, C29, C33: 100n; C_0805_2012Metric_Pad1.18x1.45mm_HandSolder; MPN KAM21BR71H104JM
D3: LED; R_0805_2012Metric_Pad1.20x1.40mm_HandSolder; not fitted
IC1: 317990687; Mouser Part Number 713-317990687
J9: U.FL; UFLRSMT10; MPN U.FL-R-SMT-1(01)
J18: Conn_02x03_Odd_Even; PinHeader_2x03_P2.54mm_Vertical; not fitted
R7, R8, R23, R24: 22R; R_0805_2012Metric_Pad1.20x1.40mm_HandSolder; MPN CRCW080522R0JNEAC
R22: 10k; R_0805_2012Metric_Pad1.20x1.40mm_HandSolder; not fitted
R25: 330R; R_0805_2012Metric_Pad1.20x1.40mm_HandSolder; not fitted
U6: RN4871; Microchip_RN4871; MPN RN4871

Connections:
+3V3_BLE: C28.1, C29.1, D3.2 (A), R22.2, U6.14 (VBAT); also elsewhere on the board
+3V3_LoRa: C22.1, C23.1, IC1.1 (VCC), J18.1; also elsewhere on the board
/Radio Frequency/BOOT_LoRa: IC1.24 (PB13), J18.6
/Radio Frequency/RST_LoRa: IC1.17 (RST), J18.5
/Radio Frequency/SWCLK_LoRa: IC1.4 (PA14), J18.4
/Radio Frequency/SWDIO_LoRa: IC1.3 (PA13), J18.2
GND: C22.2, C23.2, C28.2, C29.2, C33.2, IC1.2 (GND_1), IC1.14 (GND_2), IC1.16 (GND_3), IC1.22 (GND_4), J9.2 (Ext), J9.3 (Ext), J18.3, U6.2 (GND), U6.11 (P0_0), U6.13 (GND); also elsewhere on the board
unnamed: D3.1 (K), R25.2
unnamed: IC1.10 (PB6), R7.1
unnamed: IC1.9 (PB7), R8.1
unnamed: IC1.15 (RFIO), J9.1 (In)
unnamed: R25.1, U6.12 (P0_2)
unnamed: C33.1, R22.1, U6.10 (RST)
unnamed: R23.2, U6.7 (UART_RX)
unnamed: R24.2, U6.8 (UART_TX)
RX_BLE: R23.1; also elsewhere on the board
RX_LoRa: R8.2; also elsewhere on the board
TX_BLE: R24.1; also elsewhere on the board
TX_LoRa: R7.2; also elsewhere on the board

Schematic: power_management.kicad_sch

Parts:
C15, C27, C34: 1u; C_0805_2012Metric_Pad1.18x1.45mm_HandSolder; MPN KAM21KR71H105KL
C16, C32, C35: 100n; C_0805_2012Metric_Pad1.18x1.45mm_HandSolder; MPN KAM21BR71H104JM
JP1: Bypass LS BLE; SolderJumper-2_P1.3mm_Open_TrianglePad1.0x1.5mm
JP3: Bypass LS LoRa; SolderJumper-2_P1.3mm_Open_TrianglePad1.0x1.5mm
JP4: Bypass LS FRAM; SolderJumper-2_P1.3mm_Open_TrianglePad1.0x1.5mm
R2, R3, R14: 100k; R_0805_2012Metric_Pad1.20x1.40mm_HandSolder; MPN TR0805NR-07100KL
TP7: TP_EN_LS_BLE; TestPoint_Pad_D2.0mm
TP8: TP_EN_LS_LORA; TestPoint_Pad_D2.0mm
TP9: TP_EN_LS_FRAM; TestPoint_Pad_D2.0mm
U3, U7, U8: SiP32431DR3; SOT-363_SC-70-6; MPN SIP32431DR3

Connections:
+3V3: C15.1, C27.1, C34.1, JP1.1 (A), JP3.1 (A), JP4.1 (A), U3.4 (IN), U7.4 (IN), U8.4 (IN); also elsewhere on the board
+3V3_BLE: C16.1, JP1.2 (B), U3.1 (OUT); also elsewhere on the board
+3V3_FRAM: C35.1, JP4.2 (B), U8.1 (OUT); also elsewhere on the board
+3V3_LoRa: C32.1, JP3.2 (B), U7.1 (OUT); also elsewhere on the board
EN_LS_BLE: R2.1, TP7.1 (1_1), U3.3 (ON); also elsewhere on the board
EN_LS_FRAM: R14.1, TP9.1 (1_1), U8.3 (ON); also elsewhere on the board
EN_LS_LoRa: R3.1, TP8.1 (1_1), U7.3 (ON); also elsewhere on the board
GND: C15.2, C16.2, C27.2, C32.2, C34.2, C35.2, R2.2, R3.2, R14.2, U3.2 (GND), U3.5 (GND), U7.2 (GND), U7.5 (GND), U8.2 (GND), U8.5 (GND); also elsewhere on the board

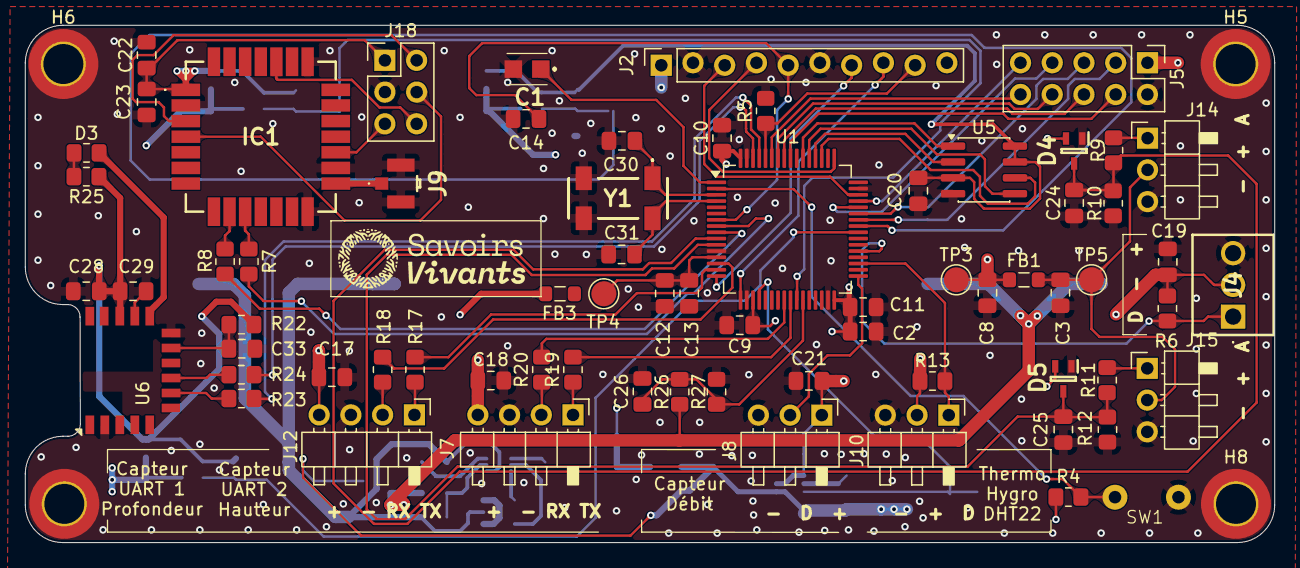
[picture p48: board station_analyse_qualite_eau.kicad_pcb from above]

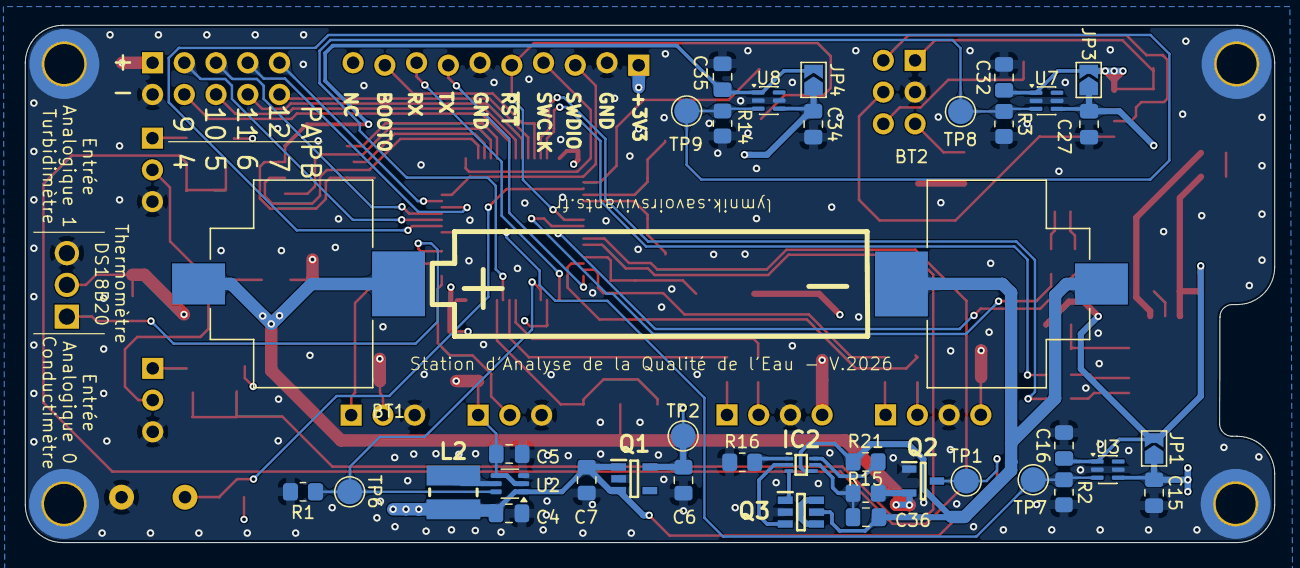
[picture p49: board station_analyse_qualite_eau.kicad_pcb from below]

Board: 4 copper layers, 100.0 x 41.4 mm, 112 parts (38 on the bottom side), 76 nets.

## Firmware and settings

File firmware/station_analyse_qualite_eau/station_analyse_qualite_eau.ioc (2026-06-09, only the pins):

Mcu.UserName=STM32U083RCTx
PA0.Signal=USART4_TX
PA1.Signal=USART4_RX
PA2.Signal=USART2_TX
PA3.Signal=USART2_RX
PA4.GPIO_Label=EN_LS_C5V
PA4.Signal=GPIO_Output
PA8.GPIO_Label=EN_LS_FRAM
PA8.Signal=GPIO_Output
PB0.GPIO_Label=EN_LS_LoRa
PB0.Signal=GPIO_Output
PB1.Signal=ADC1_IN18
PB12.GPIO_Label=IMP
PB12.Signal=GPIO_Input
PB14.Signal=S_TIM15_CH1
PB8.Signal=USART3_TX
PB9.Signal=USART3_RX
PC0.Signal=LPUART1_RX
PC1.Signal=LPUART1_TX
PC10.Signal=SPI3_SCK
PC11.Signal=SPI3_MISO
PC12.Signal=SPI3_MOSI
PC13.GPIO_Label=EN_BLE
PC13.Signal=GPXTI13
PC14-OSC32_IN.GPIO_Label=OSC32_IN
PC14-OSC32_IN.Signal=RCC_OSC32_IN
PC15-OSC32_OUT.GPIO_Label=OSC32_OUT
PC15-OSC32_OUT.Signal=RCC_OSC32_OUT
PC2.GPIO_Label=AI1
PC2.Signal=SharedAnalog_PC2
PC3.GPIO_Label=AI0
PC3.Signal=SharedAnalog_PC3
PC4.Signal=LPUART3_TX
PC5.Signal=LPUART3_RX
PC6.Signal=LPUART2_TX
PC9.GPIO_Label=EN_LS_BLE
PC9.Signal=GPIO_Output
PD2.GPIO_Label=SPI3_CS0
PD2.Signal=GPIO_Output
PF0-OSC_IN.GPIO_Label=OSC_IN
PF0-OSC_IN.Signal=RCC_OSC_IN
PF1-OSC_OUT.GPIO_Label=OSC_OUT
PF1-OSC_OUT.Signal=RCC_OSC_OUT

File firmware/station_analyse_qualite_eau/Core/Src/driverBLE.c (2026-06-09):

/*
 * driverBLE.c
 */

#include "driverBLE.h"
#include <string.h>

/* --- Timeouts et Constantes --- */
#define BLE_TIMEOUT_CONNEXION 60000 // 60s pour se connecter et envoyer la requête
#define BLE_TIMEOUT_ACK       60000 // 60s d'attente max après l'envoi
#define BLE_BOOT_TIME         500   // 500ms d'attente au démarrage du module

#define TO_CMD				  500 // TODO : A supprimer

typedef struct {
    const char *cmd;
    uint32_t timeout_ms;
    const char *expected_reply;
} BLE_AT_Cmd_t;

static const BLE_AT_Cmd_t config_sequence[] = {
		{"$$$", 500, "CMD"},
		{"S-,StationEau\r", 500, "AOK"},
		{"---\r", 500, "END"}
};

#define CONFIG_STEPS (sizeof(config_sequence) / sizeof(config_sequence[0])) // TODO : A mon avis cela ne foncitonne plus...


/* --- Helper Interne --- */
static void UART_Send_Cmd(BLE_t *hble, const char *cmd) {
    /* Nettoyage du buffer RX avant chaque nouvel envoi */
    memset(hble->rx_buffer, 0, sizeof(hble->rx_buffer));
    hble->rx_size = 0;
    hble->rx_flag = false;

    __HAL_UART_CLEAR_OREFLAG(hble->huart);

    /* On relance l'écoute DMA */
    HAL_UARTEx_ReceiveToIdle_DMA(hble->huart, (uint8_t*)hble->rx_buffer, sizeof(hble->rx_buffer));

    /* Envoi de la commande */
    strncpy(hble->tx_buffer, cmd, sizeof(hble->tx_buffer) - 1);
    HAL_UART_Transmit_IT(hble->huart, (const uint8_t*)hble->tx_buffer, strlen(hble->tx_buffer));

    hble->timer_start = HAL_GetTick();
}


void BLE_Init(BLE_t *hble, UART_HandleTypeDef *huart)
{
    hble->huart = huart;
    hble->state = BLE_STATE_IDLE;
    hble->rx_flag = false;
    memset(hble->tx_buffer, 0, sizeof(hble->tx_buffer));

    BLE_PRINT("Initialisation terminee.\r\n");
}

BLE_Result_t BLE_Configure(BLE_t *hble)
{
	if (hble == NULL) return BLE_ERR_PARAM;

	hble->state = BLE_STATE_CONFIGURING;
	hble->status = BLE_STATUS_CONFIGURING;

	hble->timer_start = HAL_GetTick();

	return BLE_OK;
}

BLE_Result_t BLE_Start(BLE_t *hble)
{
	if (hble == NULL) return BLE_ERR_PARAM;
	if (hble->state != BLE_STATE_IDLE) return BLE_BUSY;

	hble->timer_start = HAL_GetTick();
	hble->state = BLE_STATE_START;

	return BLE_OK;
}

void BLE_Process(BLE_t *hble)
{
    switch(hble->state)
    {
        case BLE_STATE_IDLE:
            break;

        case BLE_STATE_CONFIGURING:
            if (HAL_GetTick() - hble->timer_start > BLE_BOOT_TIME) {
            	if (hble->config_step < CONFIG_STEPS) {
					printf("[BLE] Config step %d/%d\r\n", hble->config_step + 1, CONFIG_STEPS);
					UART_Send_Cmd(hble, config_sequence[hble->config_step].cmd);
					hble->state = BLE_STATE_CONFIGURING_WAIT;
				} else {
					/* Fin de la configuration, on repasse en IDLE */
					hble->status = BLE_STATUS_READY;
					hble->state  = BLE_STATE_IDLE;
				}
            }
        	break;

        case BLE_STATE_CONFIGURING_WAIT:
        	if (hble->rx_flag) {
				hble->rx_flag = false;
				printf("[BLE] Retour %s\r\n", hble->rx_buffer);

				/* Si on trouve la réponse attendue */
				if (strstr((char*)hble->rx_buffer, config_sequence[hble->config_step].expected_reply) != NULL) {
					hble->config_step++;
					hble->retry_count = 0;
					hble->state = BLE_STATE_CONFIGURING; /* On boucle sur le suivant ! */
				}
				/* Si on reçoit une erreur AT */
				else if (strstr((char*)hble->rx_buffer, "ERR") != NULL) { // TODO : Ou alors aussi "?" qui vient lorsque il ne reconnait pas du tout la commande
					hble->retry_count++;
					BLE_PRINT("Retry %d\r\n", hble->retry_count);
					if (hble->retry_count >= 3) {
						hble->status = BLE_STATUS_ERROR;
						hble->state  = BLE_STATE_ERROR;
					} else {
						hble->state = BLE_STATE_CONFIGURING; /* On retente la même commande */
					}
				} else {
					/* Bruit, on relance l'écoute */
					HAL_UARTEx_ReceiveToIdle_DMA(hble->huart, (uint8_t*)hble->rx_buffer, sizeof(hble->rx_buffer));
				}
			}
			/* Timeout spécifique à cette commande */
			else if ((HAL_GetTick() - hble->timer_start) > config_sequence[hble->config_step].timeout_ms) {
				HAL_UART_AbortReceive(hble->huart);
				hble->state = BLE_STATE_CONFIGURING; /* On retente */
				hble->retry_count++;
				BLE_PRINT("Retry %d\r\n", hble->retry_count);

			}
        	break;

        case BLE_STATE_START:
            if (HAL_GetTick() - hble->timer_start > BLE_BOOT_TIME) {
                BLE_PRINT("Module pret. Attente requete utilisateur ('?')...\r\n");

                // On met l'UART en écoute (1 octet)
                __HAL_UART_CLEAR_FLAG(hble->huart, UART_CLEAR_OREF);
                memset(hble->rx_buffer, 0, sizeof(hble->rx_buffer));
				HAL_UARTEx_ReceiveToIdle_DMA(hble->huart, (uint8_t*)hble->rx_buffer, sizeof(hble->rx_buffer));


                hble->timer_start = HAL_GetTick();
                hble->state = BLE_STATE_WAIT_CMD;
            }
            break;

        case BLE_STATE_WAIT_CMD:
			if (hble->rx_flag) {
				hble->rx_flag = false;
				hble->rx_buffer[sizeof(hble->rx_buffer) - 1] = '\0';
				BLE_PRINT("Commande receptionnee : %s\r\n", hble->rx_buffer);
				if (strchr((char*)hble->rx_buffer, '?') != NULL) {
					BLE_PRINT("Le telephone est pret a recevoir !\r\n");
					hble->timer_start = HAL_GetTick();
					hble->status = BLE_STATUS_STREAMING;
					hble->state = BLE_STATE_STREAMING;  // On passe en mode "Tuyau ouvert"
				} else {
					BLE_PRINT("Commande inconnue : %s\r\n", hble->rx_buffer); // TODO : Est-ce que cela pose un problème ? on est pas sur que il y aura un \0 à la fin non ?
					__HAL_UART_CLEAR_FLAG(hble->huart, UART_CLEAR_OREF);
					memset(hble->rx_buffer, 0, sizeof(hble->rx_buffer));
					HAL_UARTEx_ReceiveToIdle_DMA(hble->huart, (uint8_t*)hble->rx_buffer, sizeof(hble->rx_buffer));

				}
			}
			if ((HAL_GetTick() - hble->timer_start) > BLE_TIMEOUT_CONNEXION) {
				HAL_UART_AbortReceive(hble->huart);
				hble->state = BLE_STATE_STOP;
			}
			break;

		case BLE_STATE_STREAMING:
			// Le driver ne fait RIEN de lui-même ici !
			// Il attend passivement que le main.c appelle BLE_SendChunk().
			if ((HAL_GetTick() - hble->timer_start) > BLE_TIMEOUT_ACK) {
				BLE_PRINT("TIMEOUT Inactivite (30s) après le signalement de disponibilité. Extinction.\r\n");
				HAL_UART_AbortReceive(hble->huart);
				hble->state = BLE_STATE_STOP;
			}
			break;

		case BLE_STATE_STREAMING_WAIT:
			if (hble->tx_flag) {
				hble->tx_flag = false;
				hble->state = BLE_STATE_STREAMING;
			}
			if ((HAL_GetTick() - hble->timer_start) > BLE_TIMEOUT_ACK) {
				BLE_PRINT("TIMEOUT Inactivite (30s) après le signalement de disponibilité. Extinction.\r\n");
				HAL_UART_AbortReceive(hble->huart);
				hble->state = BLE_STATE_STOP;
			}
			break;
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

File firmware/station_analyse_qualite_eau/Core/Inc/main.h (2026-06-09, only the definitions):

#define EN_BLE_Pin GPIO_PIN_13
#define EN_BLE_GPIO_Port GPIOC
#define EN_BLE_EXTI_IRQn EXTI4_15_IRQn
#define OSC32_IN_Pin GPIO_PIN_14
#define OSC32_IN_GPIO_Port GPIOC
#define OSC32_OUT_Pin GPIO_PIN_15
#define OSC32_OUT_GPIO_Port GPIOC
#define OSC_IN_Pin GPIO_PIN_0
#define OSC_IN_GPIO_Port GPIOF
#define OSC_OUT_Pin GPIO_PIN_1
#define OSC_OUT_GPIO_Port GPIOF
#define AI1_Pin GPIO_PIN_2
#define AI1_GPIO_Port GPIOC
#define AI0_Pin GPIO_PIN_3
#define AI0_GPIO_Port GPIOC
#define EN_LS_C5V_Pin GPIO_PIN_4
#define EN_LS_C5V_GPIO_Port GPIOA
#define EN_LS_LoRa_Pin GPIO_PIN_0
#define EN_LS_LoRa_GPIO_Port GPIOB
#define IMP_Pin GPIO_PIN_12
#define IMP_GPIO_Port GPIOB
#define EN_LS_BLE_Pin GPIO_PIN_9
#define EN_LS_BLE_GPIO_Port GPIOC
#define EN_LS_FRAM_Pin GPIO_PIN_8
#define EN_LS_FRAM_GPIO_Port GPIOA
#define SWDIO_Pin GPIO_PIN_13
#define SWDIO_GPIO_Port GPIOA
#define SWCLK_Pin GPIO_PIN_14
#define SWCLK_GPIO_Port GPIOA
#define SPI3_CS0_Pin GPIO_PIN_2
#define SPI3_CS0_GPIO_Port GPIOD

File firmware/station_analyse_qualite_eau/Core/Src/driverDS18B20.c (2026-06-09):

/*
 * driverDS18B20.c
 *
 *  Created on: 30 mars 2026
 *      Author: valen
 */

#include <stdint.h>

#include "usart.h"
#include "main.h"
#include "driverDS18B20.h"

/* * Précalcul des commandes 1-Wire pour l'UART.
 * Exemple pour 0xCC (Skip ROM) : 1100 1100 en binaire
 * /!\ C'est transmis de LSB à MSB !
 * Bit 0: 0 -> 0x00
 * Bit 1: 0 -> 0x00
 * Bit 2: 1 -> 0xFF
 * ... etc.
 */
const uint8_t DS_CMD_SKIP_ROM[8]  = {0x00, 0x00, 0xFF, 0xFF, 0x00, 0x00, 0xFF, 0xFF}; 		// 0xCC = 0b11001100
const uint8_t DS_CMD_CONVERT_T[8] = {0x00, 0x00, 0xFF, 0x00, 0x00, 0x00, 0xFF, 0x00}; 		// 0x44 = 0b01000100
const uint8_t DS_CMD_READ_SCRATCH[8] = {0x00, 0xFF, 0xFF, 0xFF, 0xFF, 0xFF, 0x00, 0xFF}; 	// 0xBE = 0b10111110
const uint8_t DS_CMD_READ[72] = {0xFF, 0xFF, 0xFF, 0xFF, 0xFF, 0xFF, 0xFF, 0xFF,
								 0xFF, 0xFF, 0xFF, 0xFF, 0xFF, 0xFF, 0xFF, 0xFF,
								 0xFF, 0xFF, 0xFF, 0xFF, 0xFF, 0xFF, 0xFF, 0xFF,
								 0xFF, 0xFF, 0xFF, 0xFF, 0xFF, 0xFF, 0xFF, 0xFF,
								 0xFF, 0xFF, 0xFF, 0xFF, 0xFF, 0xFF, 0xFF, 0xFF,
								 0xFF, 0xFF, 0xFF, 0xFF, 0xFF, 0xFF, 0xFF, 0xFF,
								 0xFF, 0xFF, 0xFF, 0xFF, 0xFF, 0xFF, 0xFF, 0xFF,
								 0xFF, 0xFF, 0xFF, 0xFF, 0xFF, 0xFF, 0xFF, 0xFF,
								 0xFF, 0xFF, 0xFF, 0xFF, 0xFF, 0xFF, 0xFF, 0xFF}; 			// 0xFF, 0xFF, 0xFF, 0xFF, 0xFF, 0xFF, 0xFF, 0xFF, 0xFF

const uint8_t DS_CMD_RESET[1] = {0xF0};														// Reset pulse


DS18B20_Result_t DS18B20_Init(DS18B20_t * hds, UART_HandleTypeDef * huart)
{
	if (hds == NULL || huart == NULL) return DS_ERR_PARAM; 	// Vérification des paramètres

	hds->huart = huart;
	hds->state = DS_STATE_IDLE;
	hds->already_converted = false;
	hds->temperature_conversion_done = false;
	hds->error_code = DS_ERROR_NONE;
	hds->last_error = DS_ERROR_NONE;
	hds->retry_count = 0;

	return DS_OK;								// Capteur bien initialisé
}

/**
 * @brief  Change le baudrate de l'UART de manière sécurisée.
 * @note   Fonction interne (static), non exposée dans le .h
 */
static DS18B20_Result_t DS18B20_SetBaudrate(DS18B20_t *hds, uint32_t baudrate)
{
    if (hds == NULL || hds->huart == NULL) return DS_ERR_PARAM;	// Vérification des paramètres

    __HAL_UART_DISABLE(hds->huart);
	if (baudrate == 9600) {
		hds->huart->Instance->BRR = LPUART_BRR_9600;
		hds->huart->Init.BaudRate = 9600;
	} else {
		hds->huart->Instance->BRR = LPUART_BRR_115200;
		hds->huart->Init.BaudRate = 115200;
	}
	__HAL_UART_ENABLE(hds->huart);

	return DS_OK;
}

DS18B20_Result_t DS18B20_Start(DS18B20_t *hds)
{
	if (hds == NULL) return DS_ERR_PARAM;

	if (hds->state == DS_STATE_ERROR) {
		return DS_ERR_HW_LOCKED;
	} else if (hds->state != DS_STATE_IDLE) {		// Vérification si une mesure n'est pas déjà en cours
		return DS_ERR_BUSY;
	}

	DS_LOG("Demarrage mesure...");

	hds->state = DS_STATE_START_RESET;				// Démarrage de la FSM de conversion
	hds->temperature_conversion_done = false;

	return DS_OK;
}

/**
 * @brief  Gère les erreurs de la FSM, nettoie le contexte et gère les tentatives.
 * @note   Fonction interne (static).
 */
static void DS18B20_HandleError(DS18B20_t *hds, DS18B20_Error_t error_code)
{
    if (hds == NULL || hds->huart == NULL) return;

    HAL_UART_Abort_IT(hds->huart);

    hds->last_error = error_code;
    hds->retry_count++;

    //hds->tx_done = false;
    //hds->rx_done = false;
    hds->temperature_conversion_done = false;
    hds->already_converted = false;

    if (hds->retry_count <= DS18B20_MAX_RETRIES) {
        DS_LOG("Erreur %d. Retry %d/%d...", error_code, hds->retry_count, DS18B20_MAX_RETRIES);
        hds->timer_start = HAL_GetTick();
        hds->state = DS_STATE_WAIT_RETRY;
    } else {
        DS_LOG("ECHEC CRITIQUE (Code %d). Abandon.", error_code);
        hds->state = DS_STATE_ERROR;
        HAL_UART_Abort(hds->huart);
    }
}

DS18B20_Status_t DS18B20_GetStatus(DS18B20_t *hds)
{
	if (hds == NULL) return DS_ERR_PARAM;

    if (hds->state == DS_STATE_IDLE) {
        return DS_STATUS_READY;
    }
    else if (hds->state == DS_STATE_ERROR) {
        return DS_STATUS_ERROR;
    }
    else {
        return DS_STATUS_BUSY;
    }
}

int16_t DS18B20_GetTemperature(DS18B20_t *hds) {
    return hds->temperature;
}

/**
 * @brief  Calcule le CRC-8 standard Dallas/Maxim (1-Wire).
 * @param  data Tableau des octets reçus.
 * @param  len  Nombre d'octets (généralement 8).
 * @return Le CRC calculé. S'il est égal au 9ème octet, les données sont valides.
 */
static uint8_t DS18B20_ComputeCRC(const uint8_t *data, uint8_t len) // TODO : Comprendre la fonction
{
    uint8_t crc = 0;
    for (uint8_t i = 0; i < len; i++) {
        uint8_t inbyte = data[i];
        for (uint8_t j = 0; j < 8; j++) {
            uint8_t mix = (crc ^ inbyte) & 0x01;
            crc >>= 1;
            if (mix) {
                crc ^= 0x8C; // Plynôme X^8 + X^5 + X^4 + 1 inversé
            }
            inbyte >>= 1;
        }
    }
    return crc;
}

void DS18B20_Process(DS18B20_t *hds) {
    switch (hds->state) {

        case DS_STATE_IDLE:
            break;

// ---------------- RESET PULSE ----------------

        case DS_STATE_START_RESET:
        	if (DS18B20_SetBaudrate(hds, 9600) != DS_OK) {
				DS18B20_HandleError(hds, DS_ERROR_UART_CONFIG);
				break;
			}

            hds->tx_done = false;
            hds->rx_done = false;

            __HAL_UART_DISABLE_IT(hds->huart, UART_IT_ERR);

            if (HAL_UART_Receive_DMA(hds->huart, hds->rx_buffer, 1) != HAL_OK) { DS18B20_HandleError(hds, DS_ERROR_DMA_INIT); break; }
            if (HAL_UART_Transmit_DMA(hds->huart, (uint8_t*)DS_CMD_RESET, 1) != HAL_OK) { DS18B20_HandleError(hds, DS_ERROR_DMA_INIT); break; }

            hds->timer_start = HAL_GetTick();
            hds->state = DS_STATE_WAIT_RESET_RX;
            break;

        case DS_STATE_WAIT_RESET_RX:
            if (hds->tx_done && hds->rx_done) {
                if (hds->rx_buffer[0] != 0xF0) {	// Est-ce que le capteur répond ?
					if (DS18B20_SetBaudrate(hds, 115200) != DS_OK) { DS18B20_HandleError(hds, DS_ERROR_UART_CONFIG); break; }
					hds->state = DS_STATE_SEND_SKIP_ROM;
				} else { DS18B20_HandleError(hds, DS_ERROR_NO_PRESENCE); }
            }
            else if ((HAL_GetTick() - hds->timer_start) > DS18B20_TIMEOUT_MS) { // Timeout
                HAL_UART_Abort_IT(hds->huart);
                DS18B20_HandleError(hds, DS_ERROR_UART_TIMEOUT);
            }
            break;
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

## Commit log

2026-06-05 add readme
    [254.step, 744031004.stp, BAV199W-7.stp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]
2026-06-09 Fix: Conversion du sous-module STM32 en dossier standard
    [app_main_test.c, driverAnalog.c, driverAnalog.h]

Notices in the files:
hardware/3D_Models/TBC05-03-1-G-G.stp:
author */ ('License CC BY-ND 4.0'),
